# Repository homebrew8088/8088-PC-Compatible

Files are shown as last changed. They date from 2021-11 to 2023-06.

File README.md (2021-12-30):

# 8088-PC-Compatible
8088 PC Compatible
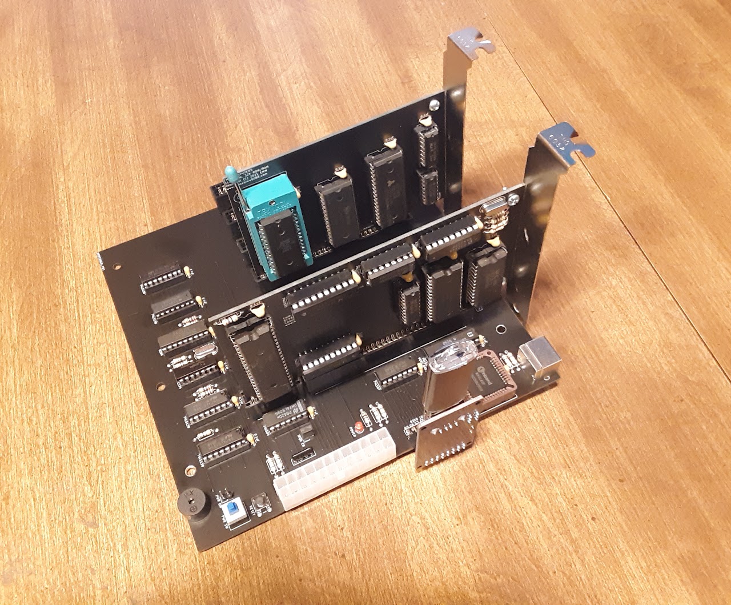
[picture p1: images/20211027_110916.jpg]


\
\
This is a repository for my 8088 PC Compatible project developed in 2021. The Motherboard is built to be generally PC XT compatible.

**Homepage**\
https://www.homebrew8088.com/

**Join the discussion group on Discord**\
https://discord.gg/AswNqwpRGP

**eBay store**\
http://www.ebay.com/sch/emil6190/m.html

**Features:**\
-8088, NEC V20, OR NEC V40 Processor\
-512k RAM (This can be changed)\
-8 Bit ISA sockets (4 slots or 7 slots)\
-PC Speaker\
-USB "Hard Drive"\
-PS/2 Keyboard\
-ATX form factor\
-Add on DMA controller (7 slot ISA only) 

[My BIOS Files](https://github.com/homebrew8088/8088-PC-Compatible/tree/main/bios) are early versions and are very primitive.

The best BIOS to use is located at https://gitlab.com/hakfoo1/v40-bios. This works on the V20 and V40 just fine. You will need one of the earlier version if you are using an actual 8088 processor. This is due to some 80186 code that was included.

-note this BIOS will not boot without a video card.

You will find the [Keyboard Fix](https://github.com/homebrew8088/8088-PC-Compatible/tree/main/asm/keyboard%20fix) under asm. Add this to your autoexec.bat if your keyboard is not working after DOS boots up.

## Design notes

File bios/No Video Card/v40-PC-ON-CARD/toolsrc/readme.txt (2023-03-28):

These tools were originally written in QuickBASIC and compiled for DOS.

However, they can be compiled for Windows/Linux with no modifications using

the FreeBASIC compiler with the "-lang qb" switch.

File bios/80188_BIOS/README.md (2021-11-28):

## This BIOS is for the 80188 with a CGA card

This is my basic BIOS adjusted for the 80188.\
For my project the only setup code needed for the 80188 processor is.

<pre>
MOV DX, 0XFFFE     ;Set DX to the Relocation Register
MOV AX, 0X40FF     ;Set AX to the new value
OUT DX, AX         ;OUT to port 0XFFFE

or 

MOV DX, 0XFFFE     ;Set DX to the Relocation Register
MOV AX, 0X60FF     ;Set AX to the new value
OUT DX, AX         ;OUT to port 0XFFFE
</pre>

This sets the internal interrupt controller as the slave making the external interrupt controller the master.

IO PORT 0XFFFE (Default value = 0X20FF)
Bit 15 |Bit 14       |Bit 13 |Bit 12       |Bit 11 - Bit 0 
-------|-------------|-------|-------------|-------
X 	   |Slave/Master |X      |M/IO         |Relocation Address 
0      |1 = S, 0 = M |0      |1 = M, 0 = IO|12 Bits if Mem Address, 8 Bits if IO Address

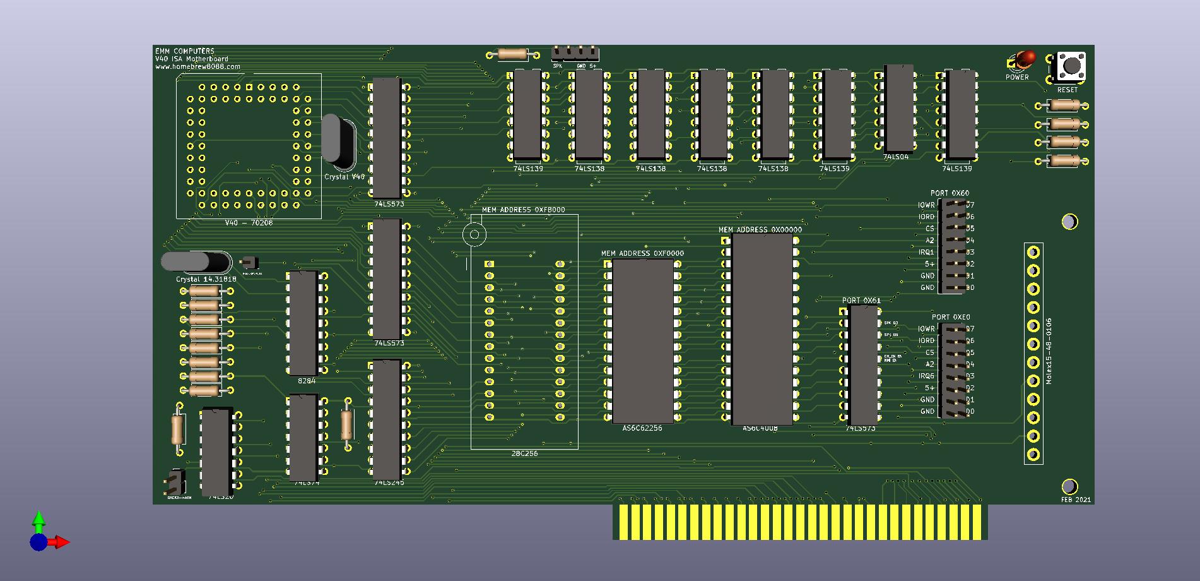
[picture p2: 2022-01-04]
Kicad/Multi ATX ISA With DMA/V40.jpg

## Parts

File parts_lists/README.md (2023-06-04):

# Parts List
This list was last updated 17 Nov 21

## Main Board 7 Slot
Description                 | Quantity
--------------------------- | ------------------------
PCB	                        |1
62 Pin Edge Card Connector 	|7
16 Pin Edge Card Connector 	|2
PLCC 44                    	|1
PS/2 Connector             	|1
24 Pin ATX Power Connector	|1
16 Right Angle Pin Header	  |1
6x6x4mm Button	            |1
8x8mm Push Pull Button	    |1
PC Speaker                	|1
1x2 Pin Header            	|1
3mm Led	                    |1
510 ohm Resistor	          |3
27 ohm Resistor           	|4
33 ohm Resistor           	|1
10K ohm Resistor	          |7
10k ohm 4 Pin Resistor Network  |2
10k ohm 9 Pin Resistor Network  |1
0.1uF Capacitor             |28
14.31818 MHz Crystal        |1
14 Pin DIP Socket         	|3
16 Pin DIP Socket         	|6
18 Pin DIP Socket           |1
20 Pin DIP Socket         	|2
74LS138                   	|3
74LS139	                    |3
74LS04                     	|1
74LS07                     	|1
74LS573	                    |1
74LS245                     |1
74LS74	                    |1
P8284	                      |1
VT82C42V                  	|1
CH376	                      |1
USB Drive	                  |1

## 8088 / V20 Card
Description           | Quantity
--------------------- | ------------------------
PCB	                  |1
16 Pin DIP Socket	    |1
18 Pin DIP Socket	    |1
20 Pin DIP Socket	    |3
24 Pin DIP Socket   	|1
28 Pin DIP Socket   	|1
40 Pin DIP Socket	    |1
70108 V20	            |1
74LS573	              |2
74LS245	              |1
74LS257	              |1
P8284               	|1
8259                	|1
8253                	|1
0.1uF Capacitor     	|8
510 ohm Resistor	    |2
27 ohm Resistor	      |1
10k ohm Resistor    	|2
~24 MHz Crystal      	|1
Keystone 9202	        |1
Screws              	|2

## V40 Card
Description           | Quantity
--------------------- | ------------------------
PCB	                  |1
PLCC 68 Socket	      |1
20 Pin DIP Socket	    |3
70208 V40	            |1
74LS573	              |2
74LS245	              |1
0.1uF Capacitor	      |4
10k ohm Resistor	    |2
16 MHz Crystal	      |1
Keystone 9202	        |1
Screws	              |2

## 640K RAM / 64K ROM Card
Description           | Quantity
--------------------- | ------------------------
PCB	                  |1
16 Pin DIP Socket     |2
32 Pin DIP Socket	    |4
74LS138	              |1
74LS139	              |1
AS6C4008	            |1
AS6C1008	            |1
W29C020	              |1
0.1uF Capacitor     	|6
Keystone 9202       	|1
Screws              	|2

## 512K RAM / 32K ROM Card
Description           | Quantity
--------------------- | ------------------------
PCB	                  |1
16 Pin DIP Socket     |2
28 Pin DIP Socket	    |1
32 Pin DIP Socket	    |1
28 Pin ZIF Socket	    |1
74LS138	              |1
74LS139	              |1
62256	                |1
AS6C4008	            |1
28C256	              |1
0.1uF Capacitor     	|5
Keystone 9202       	|1
Screws              	|2

## 640K RAM / 32K ROM Card
Description           | Quantity
--------------------- | ------------------------
PCB	                  |1
16 Pin DIP Socket     |2
28 Pin DIP Socket	    |2
32 Pin DIP Socket	    |2
74LS138	              |1
74LS139	              |1
AS6C4008	            |1
AS6C1008	            |1
62256	                |1
28C256	              |1
0.1uF Capacitor     	|6
Keystone 9202       	|1
Screws              	|2

## 8237 DMA Controller Card
Description           | Quantity
--------------------- | ------------------------
PCB	                  |1
40 Pin DIP Socket     |1
20 Pin DIP Socket     |1
16 Pin DIP Socket     |2
14 Pin DIP Socket     |1
74LS573		            |1
74LS670		            |1
74LS139		            |1
74LS04		            |1
8237-5		            |1
0.1uF Capacitor		    |5
10k ohm Resistor		  |2
27 ohm Resistor |1
Keystone 9202		      |1
Screws		            |2

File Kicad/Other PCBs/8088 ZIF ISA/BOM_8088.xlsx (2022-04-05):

Comment | Designator | Footprint | JLCPCB Part #（optional）
0.1uF | C1, C2, C3, C4, C5, C6, C7, C8 | RAD-0.2 | C19355
27R | R1 | Axial,2.4X6.5mm | C433740
510R | R2, R3 | Axial,2.4X6.5mm | C433711
10K | R4, R5 | Axial,2.4X6.5mm | C433778
DIP 40 SOCKET | U1 | DIP-40 | C72123
DIP 20 SOCKET | U2, U3, U4 | DIP-20 | C72118
DIP 16 SOCKET | U5 | DIP-16 | C72115
DIP 18 SOCKET | U6 | DIP-18 | C72116
DIP 28 SOCKET | U7 | DIP-28 | C72121
DIP 24 SOCKET | U8 | DIP-24 | C72120

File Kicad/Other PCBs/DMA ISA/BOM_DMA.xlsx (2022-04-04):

Comment | Designator | Footprint | JLCPCB Part #（optional）
0.1uF | C1, C2, C3, C4, C5 | RAD-0.2 | C19355
27R | R3 | Axial,2.4X6.5mm | C433740
10K | R1, R2 | Axial,2.4X6.5mm | C433778
DIP 40 SOCKET | U1 | DIP-40 | C72123
DIP 20 SOCKET | U5 | DIP-20 | C72118
DIP 16 SOCKET | U2, U4 | DIP-16 | C72115
DIP 14 SOCKET | U3 | DIP-14 | C72114

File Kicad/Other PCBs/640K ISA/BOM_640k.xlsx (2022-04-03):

Comment | Designator | Footprint | JLCPCB Part #（optional）
DIP-28 | U1, U2 | DIP-28_W15.24mm | C72121
DIP-32 | U3, U4 | DIP-32_W15.24mm | C146583
DIP-16 | U5, U6 | DIP-16_W7.62mm | C72115
0.1uF (104) | C1, C2, C3, C4, C5, C6 | RAD-0.2 | C19355

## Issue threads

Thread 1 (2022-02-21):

PIT initialisation code

gyorka, 2022-02-21:
Hi!
Since I'm doing V50 design myself, I wondered if someone did something similiar in the past, and I found your code and board design
I've looked into BIOS code and found that you're initialising Timer/Counter 2 to 0xFFFF - this counter counts down to 1, not to 0, thus you're a bit on high side for 18.2Hz period
Initialisation value should be 0x0000 instead, and it seems to be quite common "error"
Anyways - great project and I hope to see more of projects like this from you ;)
Cheers
 Sebastian

Closed 2023-06-17.

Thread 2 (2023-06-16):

pdf schematics seem to be broken

jmio23, 2023-06-16:
I've tried acrobat, word, chrome and a whole bunch of others, always looks like this

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

cuvtixo, 2023-06-16:
er, jmio23, firstly, there's 8 different schematics, I think you are looking at the 8088.pdf . But, THAT IS THE SCHEMATIC.  There's nothing more to these. They are not full electronic diagrams with symbols for resistors, capacitors, etc. It is mainly just the integrated circuits, and for example, 4 Slot Main Board.pdf has the various numerical values, but what you see is what you get.  I'm sorry you were expecting more.

homebrew8088, 2023-06-17:
That is how I draw my schematics. When I add the net lines it gets to busy for me to look at. I just know the chips by memory at this point and assign the pins where they need to go.

Yes they are bit out of date. I should get some newer ones published. **But** when you open the Kicad project files you will get the most up to date schematic that I been working on. Plus if you open the PCB files you can highlight the traces and see how everything is connected.

jmio23, 2023-06-18:
> That is how I draw my schematics. When I add the net lines it gets to busy for me to look at. I just know the chips by memory at this point and assign the pins where they need to go.
>
> Yes they are bit out of date. I should get some newer ones published. **But** when you open the Kicad project files you will get the most up to date schematic that I been working on. Plus if you open the PCB files you can highlight the traces and see how everything is connected.

thanks I'll check those files out; I've never used kiCad, will I be able to see for eg the entire circuit for the ISA pinout and ISA/BIOS connections? Unfortunately due to disability, even installing kiCad, let alone using it, will be a challenge for me, but if it will give me those details then it's worth the pain

I am trying to learn enough, so that I can add a solution for low rez monochrome graphics to my v20-mbc; an ISA bus i can plug a video (or whatever) card into is my preferred option; I was contemplating an ISA emulation over SPI, or an emulation of both the bus and graphics over SPI, but that feels a convoluted approach (esp considering what I still need to learn) if I can persuade the atmega32/BIOS to handle a hardware ISA bus

Closed 2023-06-17.

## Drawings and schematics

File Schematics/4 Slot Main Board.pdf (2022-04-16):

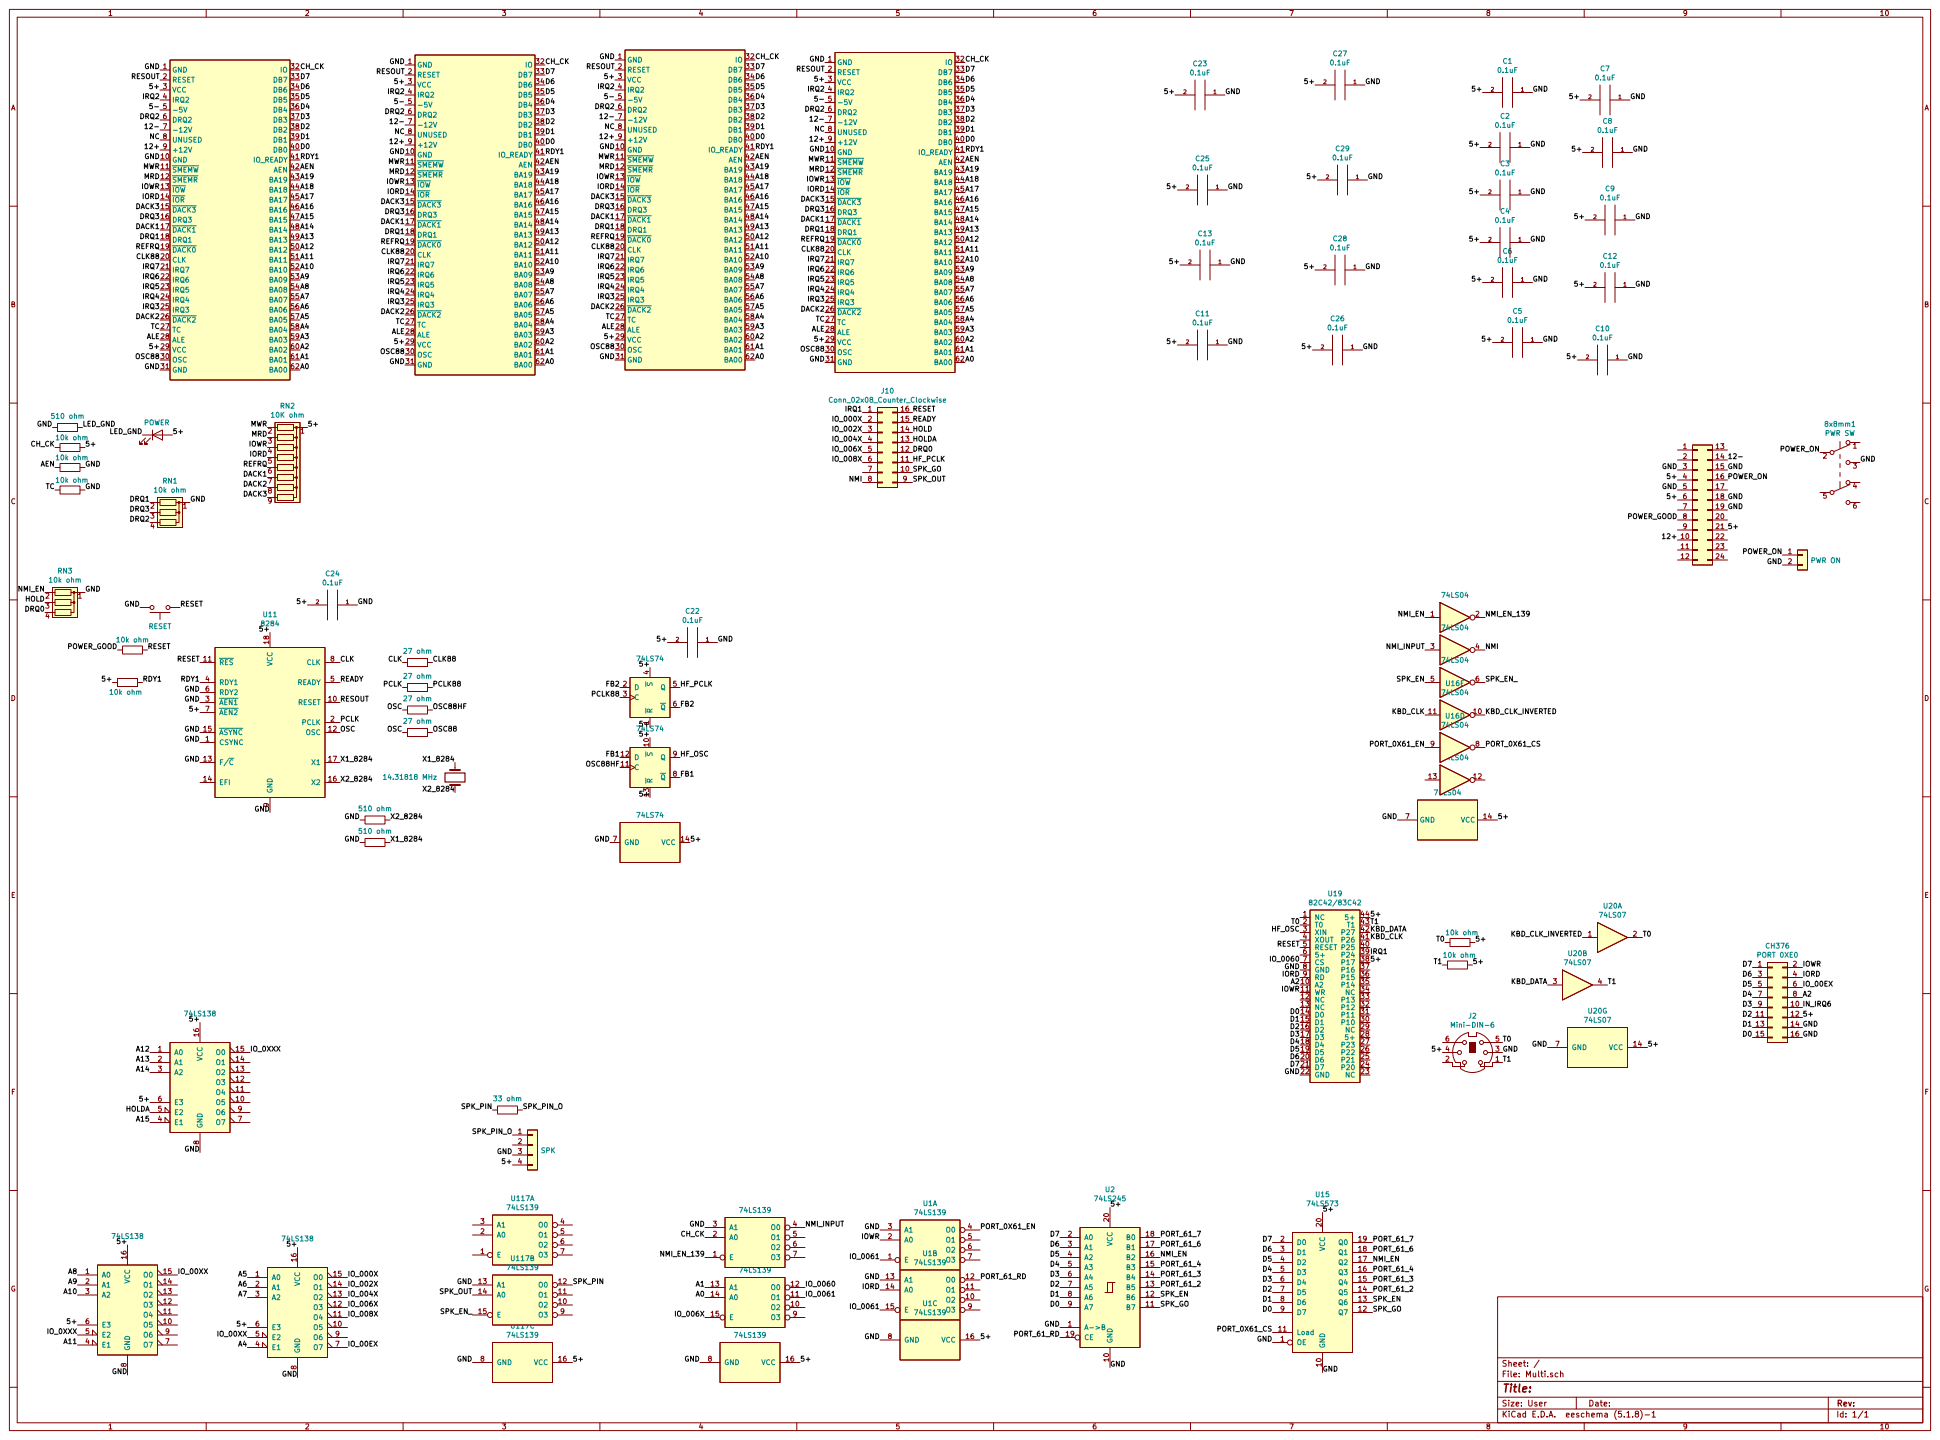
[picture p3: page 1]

12- AEN
IOWR MRD MWR GND

Id: 1/1 Title: File: Multi.sch Sheet: /

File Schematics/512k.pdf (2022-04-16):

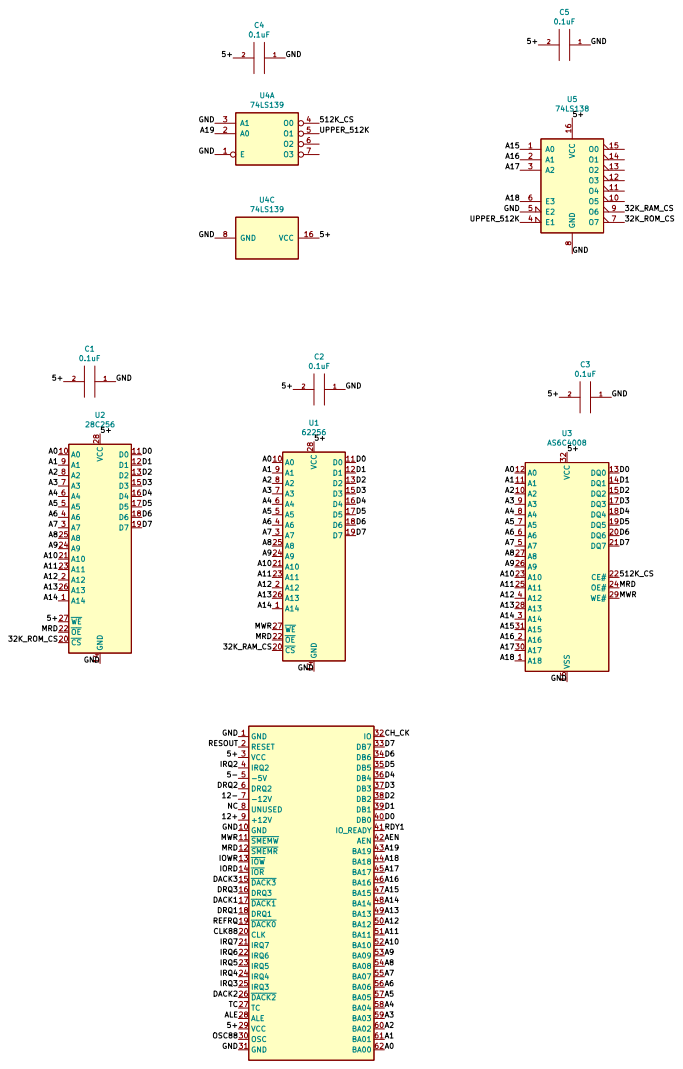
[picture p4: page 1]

IOWR MRD MWR GND

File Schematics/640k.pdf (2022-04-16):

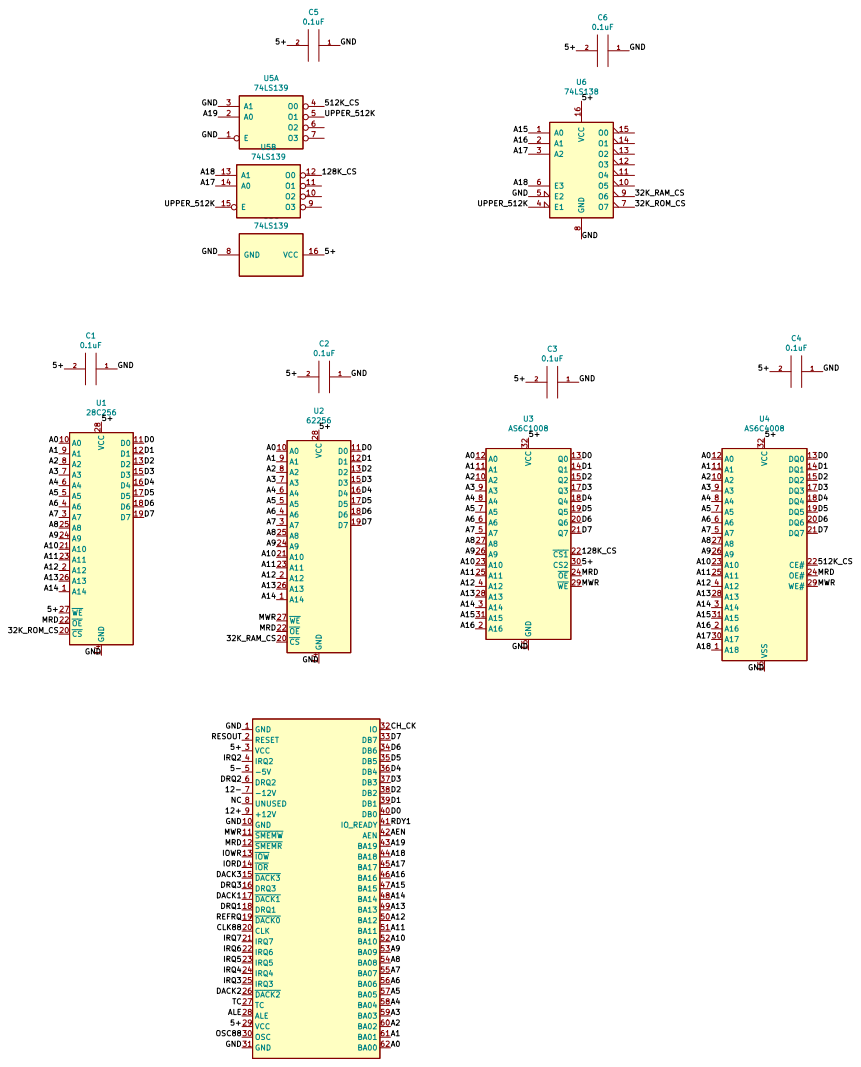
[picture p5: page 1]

IOWR MRD MWR GND

Id: 1/1 Title: File: 640k.sch Sheet: /

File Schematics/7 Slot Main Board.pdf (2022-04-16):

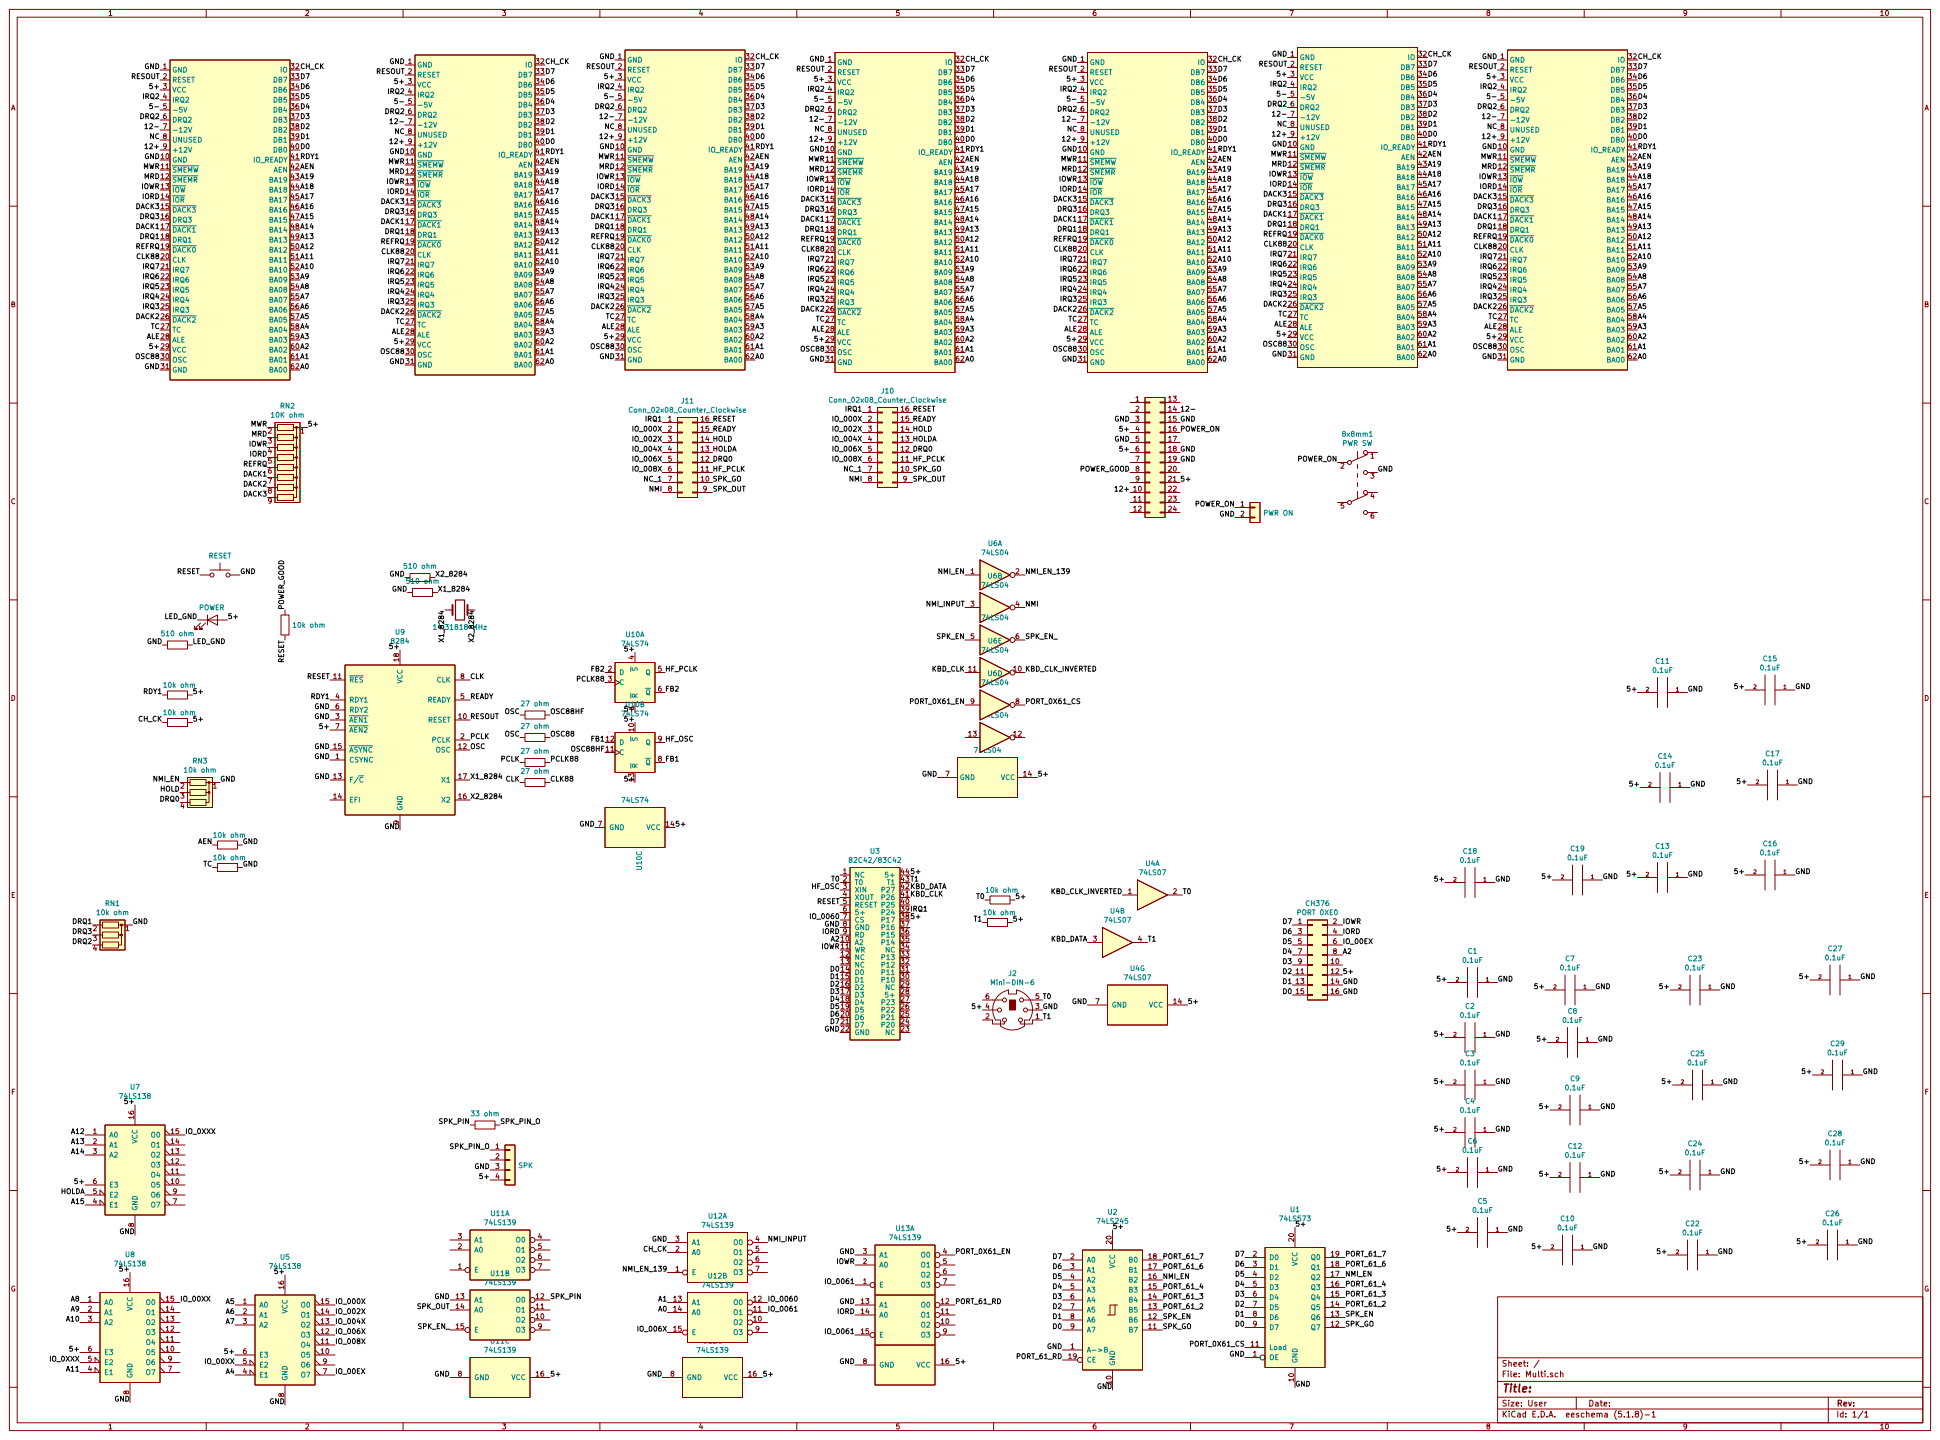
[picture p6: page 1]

IOWR MRD MWR GND

Id: 1/1 Title: File: Multi.sch Sheet: /

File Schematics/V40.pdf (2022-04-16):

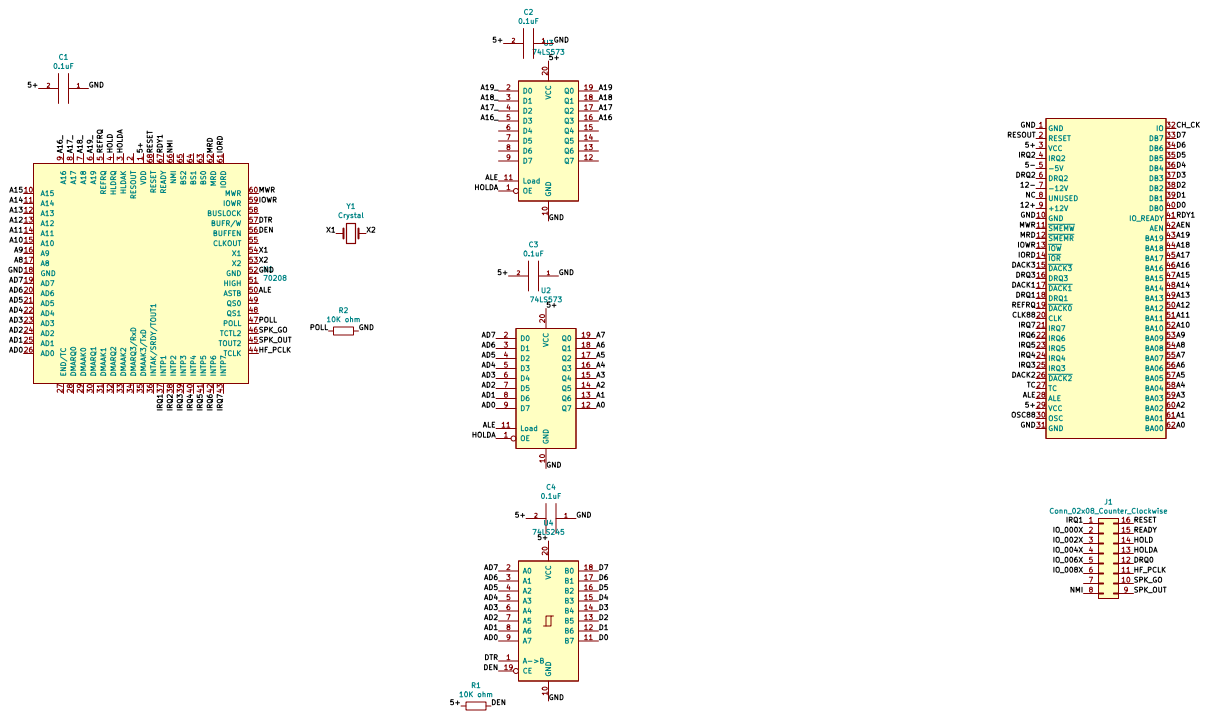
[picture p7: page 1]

IOWR MRD MWR GND

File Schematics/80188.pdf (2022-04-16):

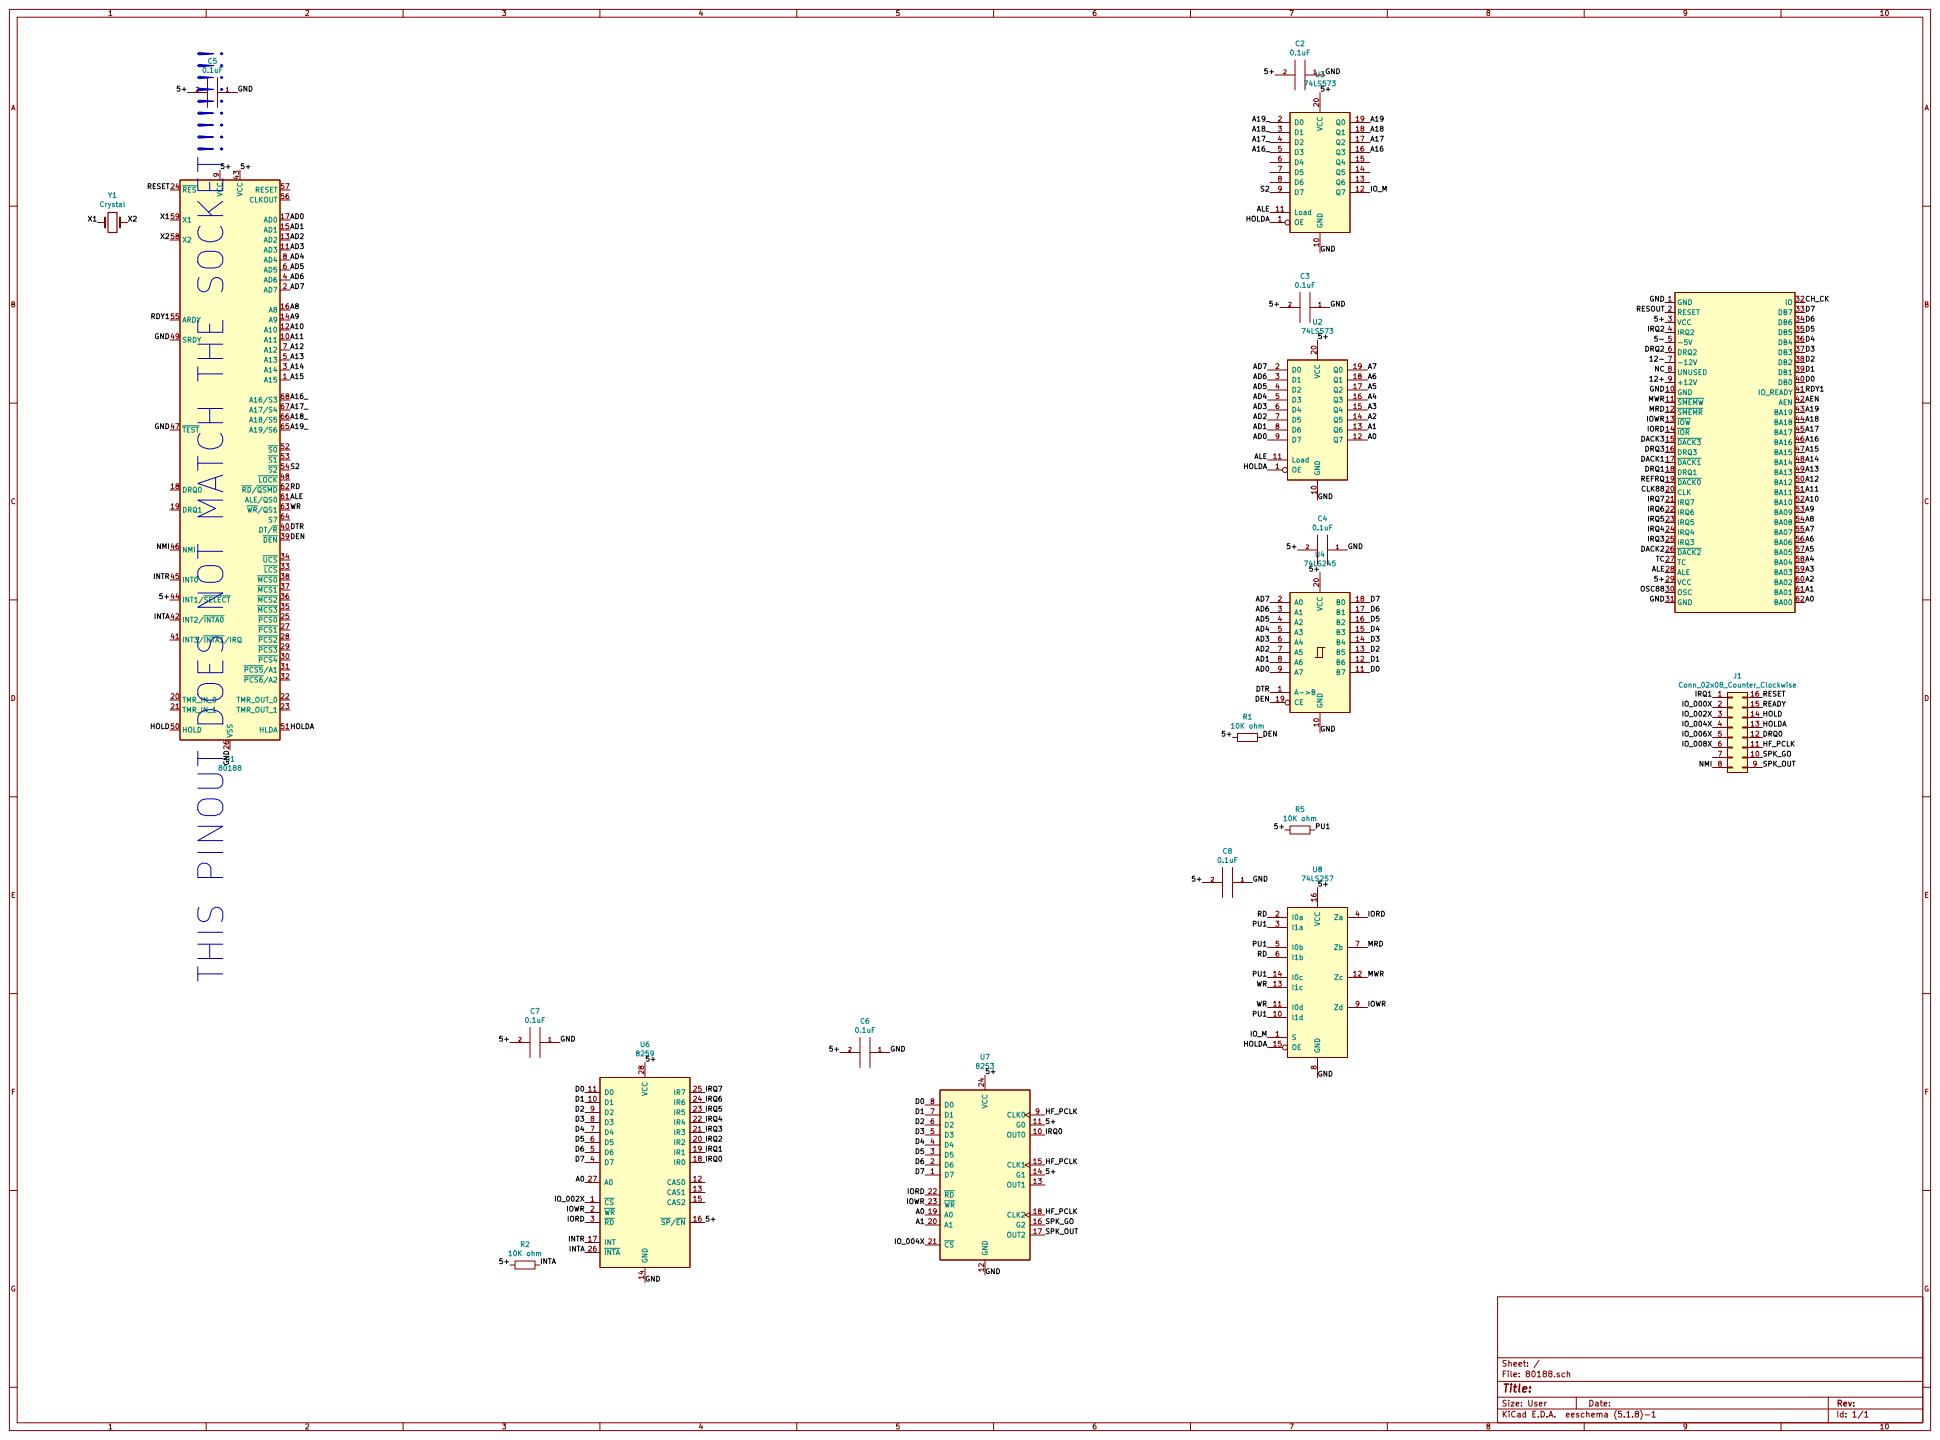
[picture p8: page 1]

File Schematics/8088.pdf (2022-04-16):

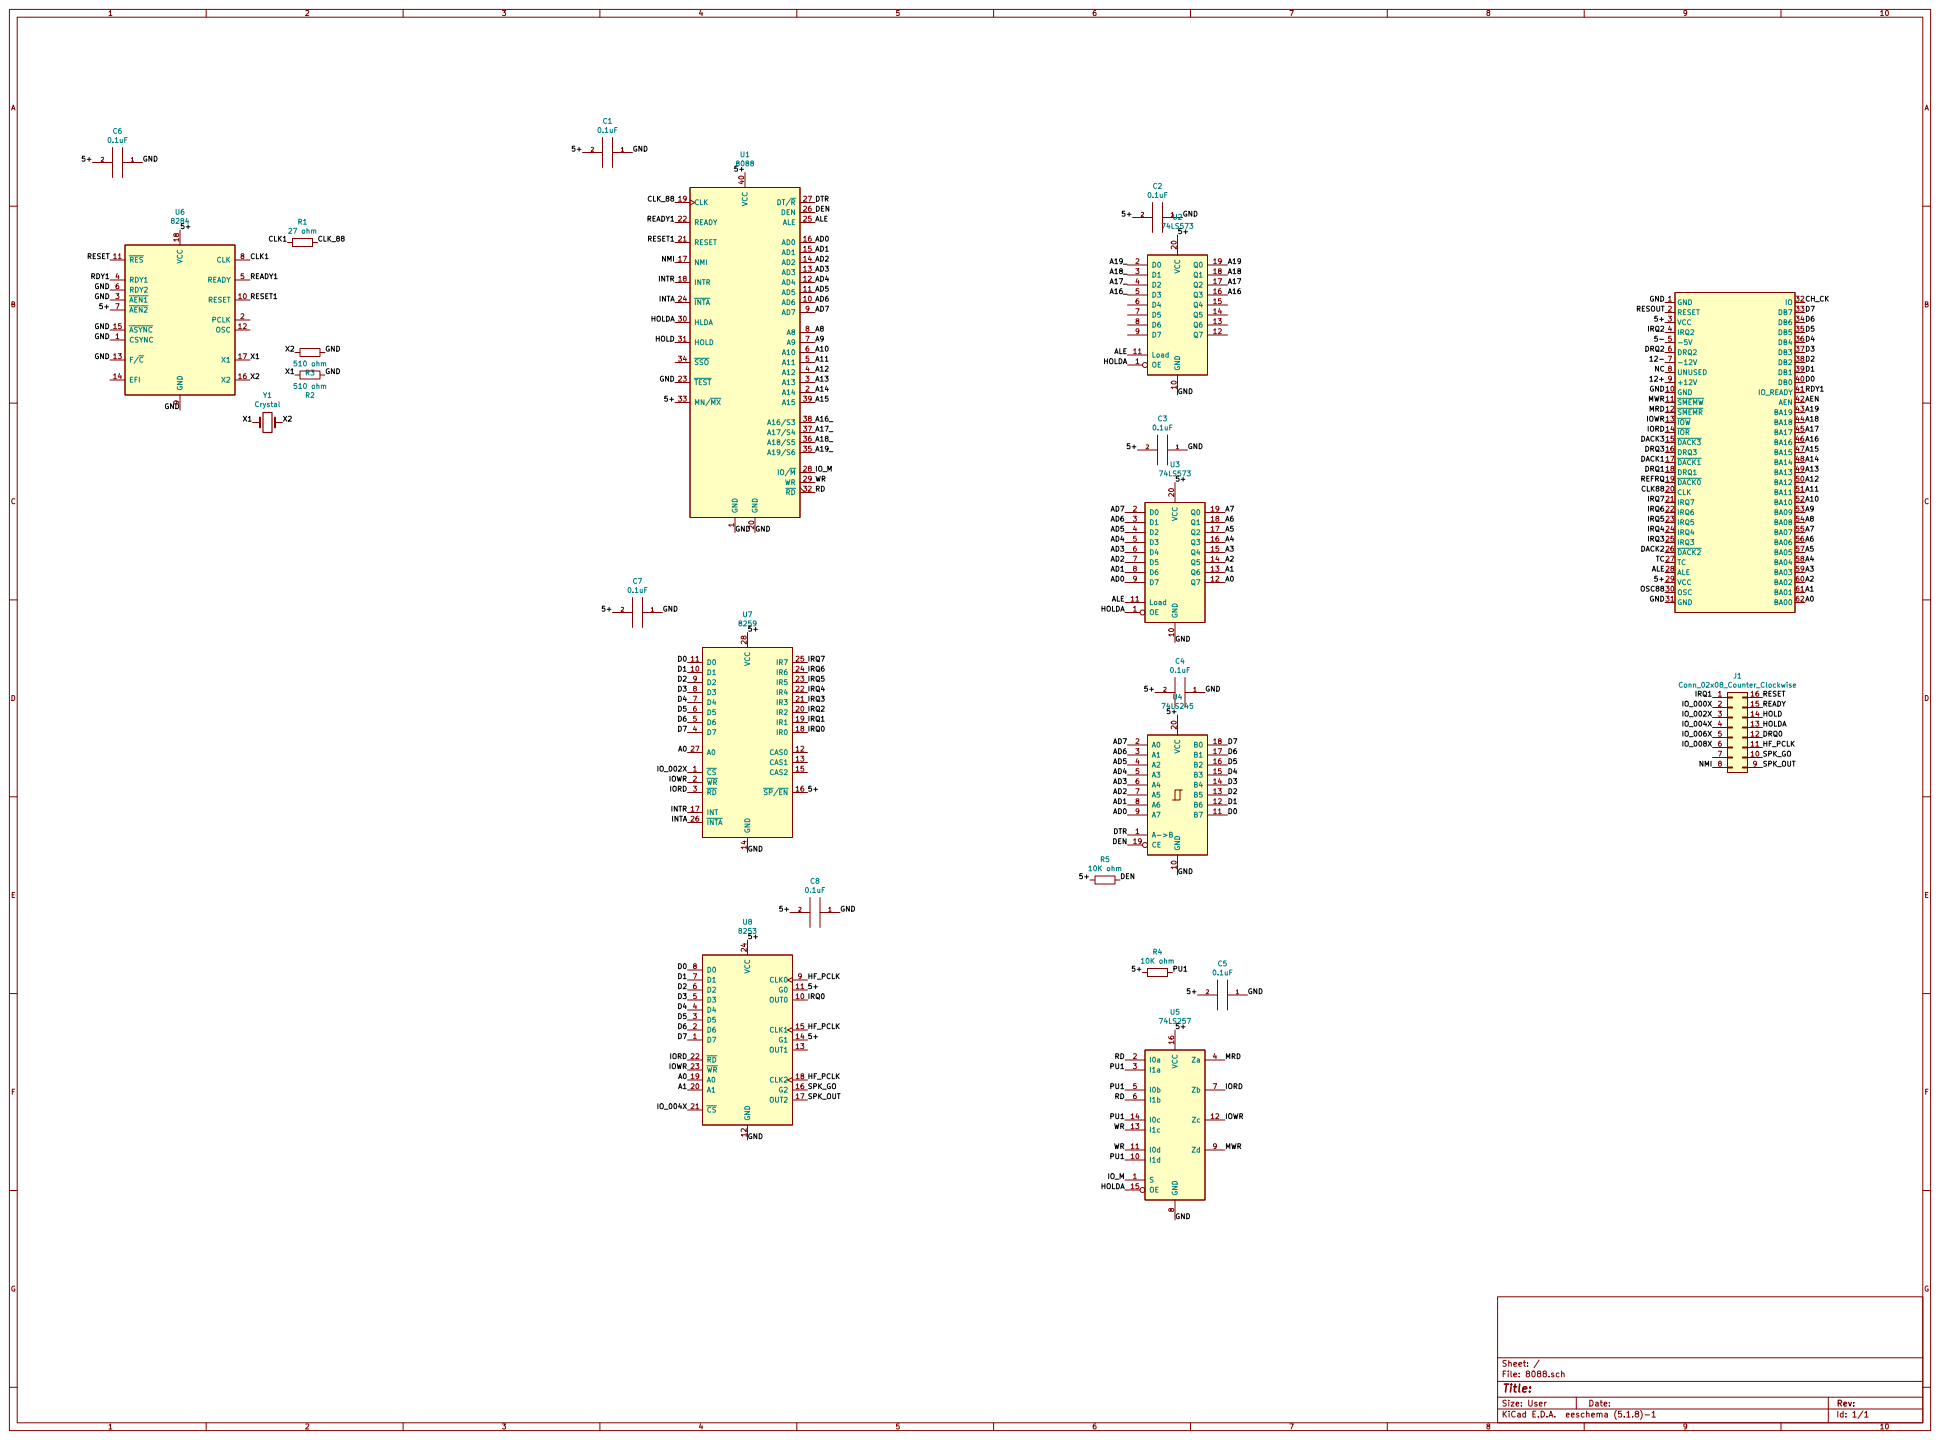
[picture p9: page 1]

Id: 1/1 Title: File: 8088.sch Sheet: / S 1

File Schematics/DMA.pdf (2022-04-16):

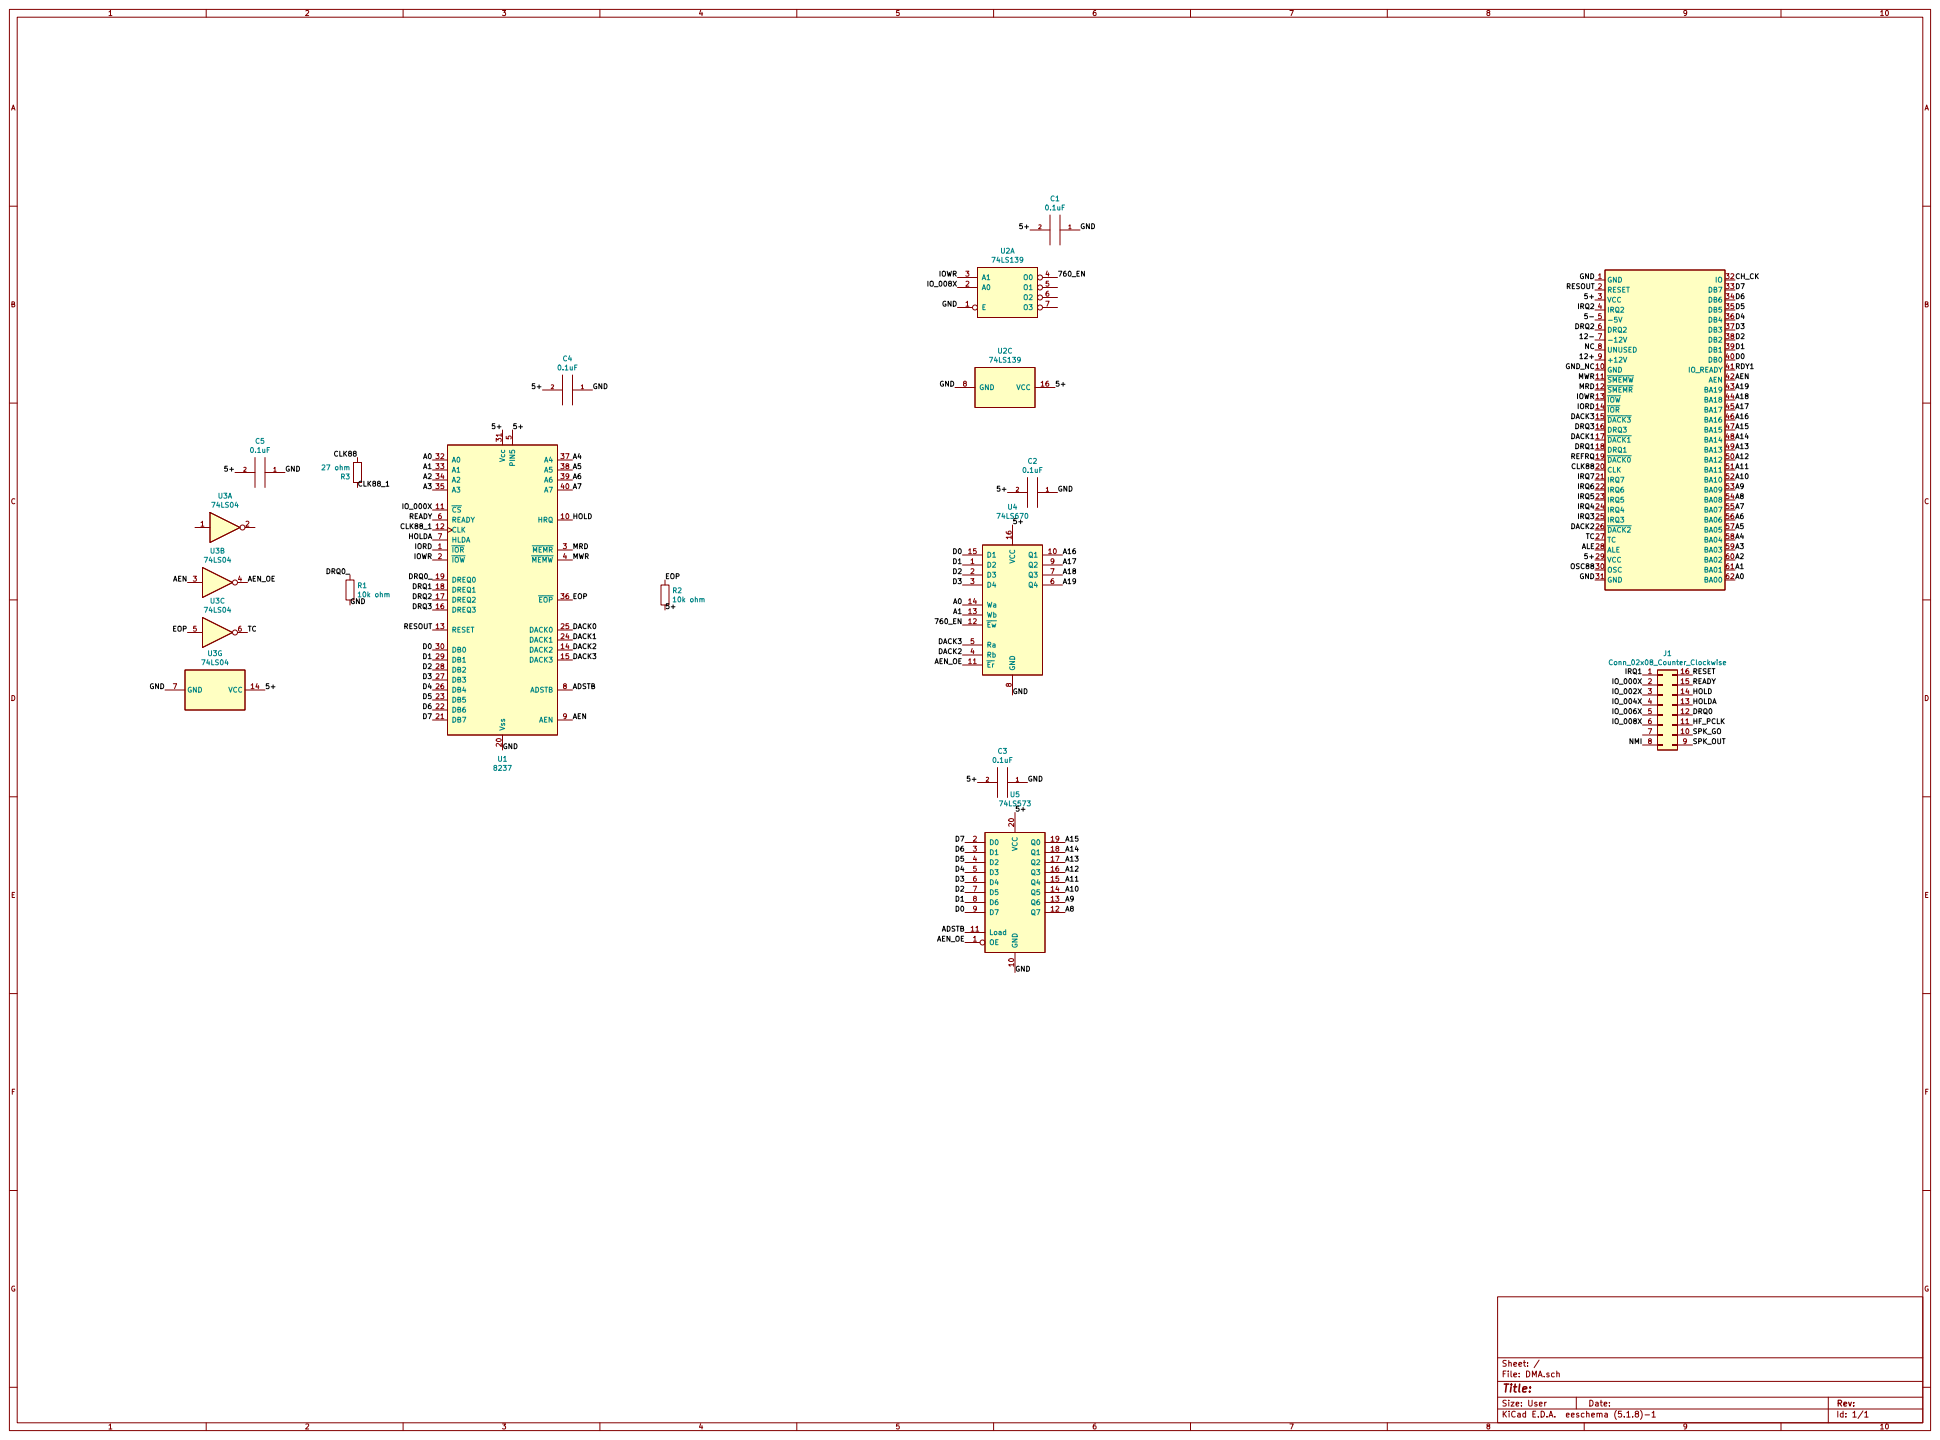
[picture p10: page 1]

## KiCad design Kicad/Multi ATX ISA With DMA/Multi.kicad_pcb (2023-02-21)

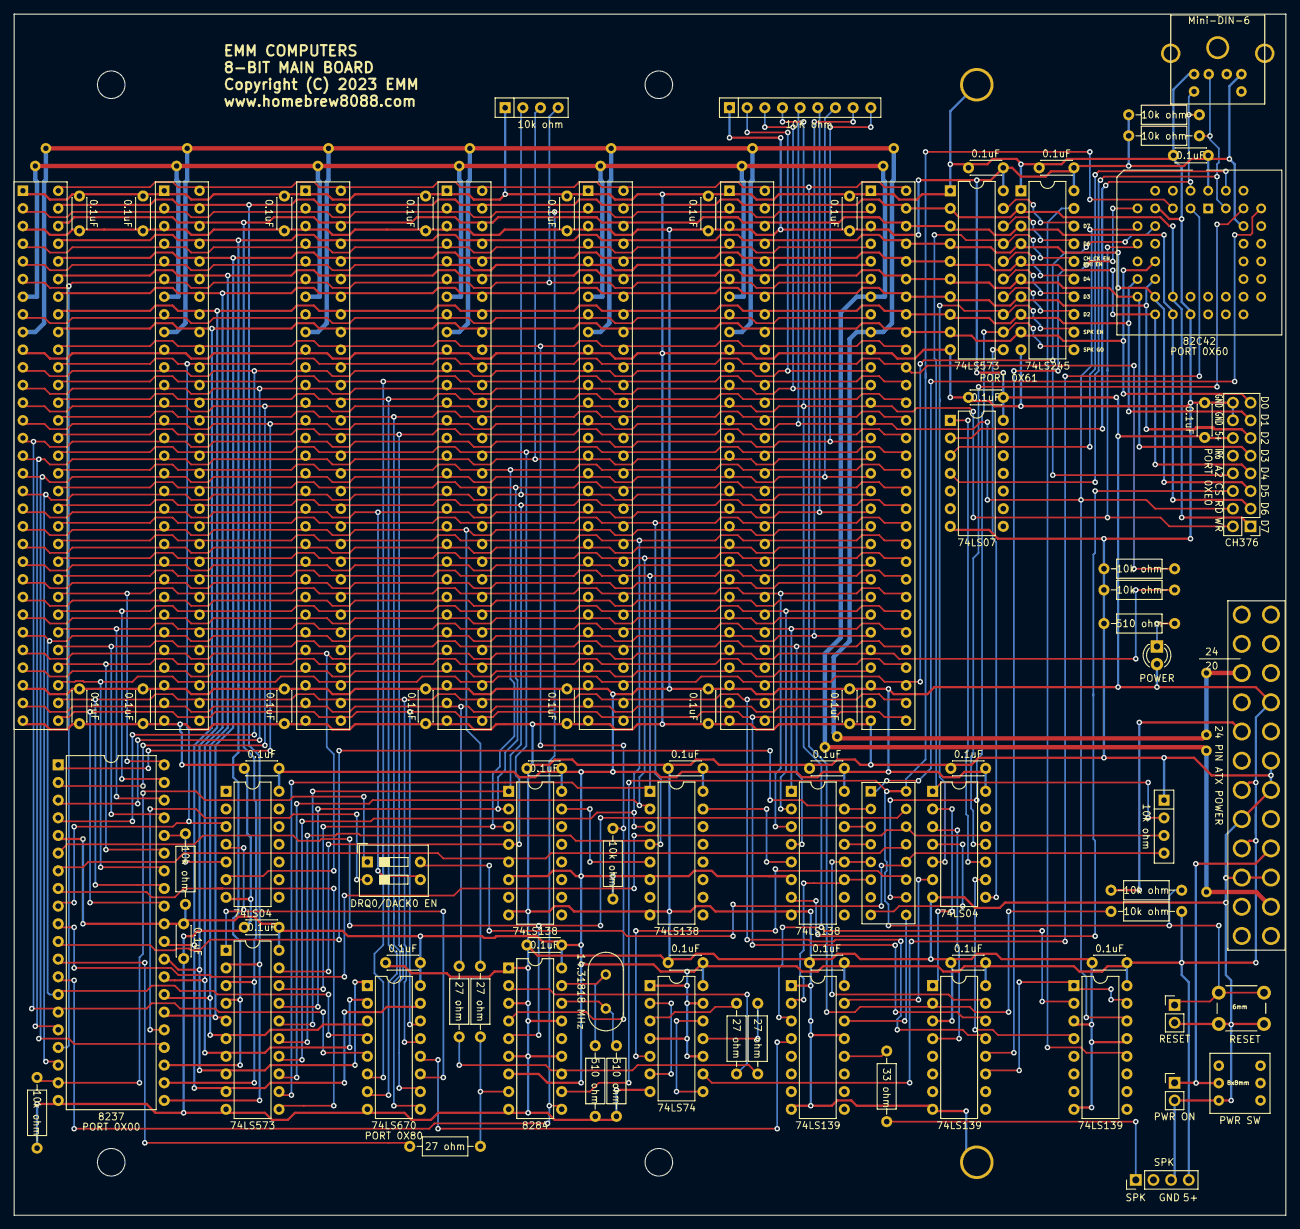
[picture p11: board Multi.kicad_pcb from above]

Board: 2 copper layers, 182.9 x 172.7 mm, 109 parts (0 on the bottom side), 119 nets.

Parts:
8x8mm1: PWR SW; 6 PIN DTDP
ATXPOWER1: Conn_02x12_Top_Bottom; 24_PIN_ATX_POWER
C1, C1#2, C1#3, C2, C3, C4, C5, C6, C7, C8, C9, C10, C11, C12, C13, C14, C15, C16, C17, C18, C19, C22, C23, C24, C25, C26, C27, C28, C29, C63, C64, C65: 0.1uF; C_Disc_D4.3mm_W1.9mm_P5.00mm
CH376: PORT 0XE0; PinHeader_2x08_P2.54mm_Vertical
D1: POWER; LED_D3.0mm
J1, J4, J5, J7, J8, J9, J11: Bus_ISA_8bit; 8-bit-ISA
J2: Mini-DIN-6; 6_PIN_DIN
J3: SPK; PinHeader_1x04_P2.54mm_Vertical
J6: PWR ON; PinHeader_1x02_P2.54mm_Vertical
J10: Conn_02x08_Counter_Clockwise; 2x08_PIN_EDGE_CARD
J12: RESET; PinHeader_1x02_P2.54mm_Vertical
R: L; Large_Via
R1, R2, R4: 510 ohm; R_Axial_DIN0207_L6.3mm_D2.5mm_P10.16mm_Horizontal
R3, R14, R17, R18, R63: 27 ohm; R_Axial_DIN0207_L6.3mm_D2.5mm_P10.16mm_Horizontal
R5, R6, R7, R8, R9, R12, R13, R61, R62: 10k ohm; R_Axial_DIN0207_L6.3mm_D2.5mm_P10.16mm_Horizontal
R#2, R#3, R#4, R#5, R#6, R#7, R#8, R#9, R#10, R#11, R#12, R#13, R#14, R#15, R#16, R#17, R#18, R#19, R#20: L; Large_Via
RN1, RN3: 10k ohm; R_Array_SIP4
RN2: 10K ohm; R_Array_SIP9
SW1: RESET; SW_PUSH_6mm
SW2: DRQ0/DACK0 EN; SW_DIP_SPSTx02_Slide_9.78x7.26mm_W7.62mm_P2.54mm
U1, U17, U117: 74LS139; DIP-16_W7.62mm
U2: 74LS245; DIP-20_W7.62mm
U3: 33 ohm; R_Axial_DIN0207_L6.3mm_D2.5mm_P10.16mm_Horizontal
U9, U12, U13: 74LS138; DIP-16_W7.62mm
U11: 8284; DIP-18_W7.62mm
U14: 74LS74; DIP-14_W7.62mm
U15, U65: 74LS573; DIP-20_W7.62mm
U16, U63: 74LS04; DIP-14_W7.62mm
U19: 82C42; PLCC-44_THT-Socket
U20: 74LS07; DIP-14_W7.62mm
U61: 8237; DIP-40_W15.24mm
U64: 74LS670; DIP-16_W7.62mm
Y2: 14.31818 MHz; Crystal_HC18-U_Vertical

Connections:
/5+: ATXPOWER1.4, ATXPOWER1.6, ATXPOWER1.21, C1.2, C1#2.2, C1#3.2, C2.2, C3.2, C4.2, C5.2, C6.2, C7.2, C8.2, C9.2, C10.2, C11.2, C12.2, C13.2, C14.2, C15.2, C16.2, C17.2, C18.2, C19.2, C22.2, C23.2, C24.2, C25.2, C26.2, C27.2, C28.2, C29.2, C63.2, C64.2, C65.2, CH376.12, D1.2, J1.3, J1.29, J2.4, J3.4, J4.3, J4.29, J5.3, J5.29, J7.3, J7.29, J8.3, J8.29, J9.3, J9.29, J11.3, J11.29, R6.1, R7.1, R8.1, R9.1, R62.2, RN2.1, U1.16, U2.20, U9.6, U9.16, U11.7, U11.18, U12.6, U12.16, U13.6, U13.16, U14.1, U14.4, U14.10, U14.13, U14.14, U15.20, U16.14, U17.16, U19.38, U19.44, U20.14, U61.5, U61.31, U63.14, U64.16, U65.20, U117.16
/5-: J1.5, J4.5, J5.5, J7.5, J8.5, J9.5, J11.5
/12+: ATXPOWER1.10, J1.9, J4.9, J5.9, J7.9, J8.9, J9.9, J11.9, R.1, R#3.1, R#6.1, R#7.1, R#8.1, R#12.1, R#14.1, R#15.1, R#18.1, R#20.1
/12-: ATXPOWER1.14, J1.7, J4.7, J5.7, J7.7, J8.7, J9.7, J11.7, R#2.1, R#4.1, R#5.1, R#9.1, R#10.1, R#11.1, R#13.1, R#16.1, R#17.1, R#19.1
/760_EN: U64.12, U117.4
/A0: J1.62, J4.62, J5.62, J7.62, J8.62, J9.62, J11.62, U17.14, U61.32, U64.14
/A1: J1.61, J4.61, J5.61, J7.61, J8.61, J9.61, J11.61, U17.13, U61.33, U64.13
/A2: CH376.8, J1.60, J4.60, J5.60, J7.60, J8.60, J9.60, J11.60, U19.10, U61.34
/A3: J1.59, J4.59, J5.59, J7.59, J8.59, J9.59, J11.59, U61.35
/A4: J1.58, J4.58, J5.58, J7.58, J8.58, J9.58, J11.58, U13.4, U61.37
/A5: J1.57, J4.57, J5.57, J7.57, J8.57, J9.57, J11.57, U13.1, U61.38
/A6: J1.56, J4.56, J5.56, J7.56, J8.56, J9.56, J11.56, U13.2, U61.39
/A7: J1.55, J4.55, J5.55, J7.55, J8.55, J9.55, J11.55, U13.3, U61.40
/A8: J1.54, J4.54, J5.54, J7.54, J8.54, J9.54, J11.54, U12.1, U65.12
/A9: J1.53, J4.53, J5.53, J7.53, J8.53, J9.53, J11.53, U12.2, U65.13
/A10: J1.52, J4.52, J5.52, J7.52, J8.52, J9.52, J11.52, U12.3, U65.14
/A11: J1.51, J4.51, J5.51, J7.51, J8.51, J9.51, J11.51, U12.4, U65.15
/A12: J1.50, J4.50, J5.50, J7.50, J8.50, J9.50, J11.50, U9.1, U65.16
/A13: J1.49, J4.49, J5.49, J7.49, J8.49, J9.49, J11.49, U9.2, U65.17
/A14: J1.48, J4.48, J5.48, J7.48, J8.48, J9.48, J11.48, U9.3, U65.18
/A15: J1.47, J4.47, J5.47, J7.47, J8.47, J9.47, J11.47, U9.4, U65.19
/A16: J1.46, J4.46, J5.46, J7.46, J8.46, J9.46, J11.46, U64.10
/A17: J1.45, J4.45, J5.45, J7.45, J8.45, J9.45, J11.45, U64.9
/A18: J1.44, J4.44, J5.44, J7.44, J8.44, J9.44, J11.44, U64.7
/A19: J1.43, J4.43, J5.43, J7.43, J8.43, J9.43, J11.43, U64.6
/ADSTB: U61.8, U65.11
/AEN: J1.42, J4.42, J5.42, J7.42, J8.42, J9.42, J11.42, R12.2, U61.9, U63.3
/AEN_OE: U63.4, U64.11, U65.1
/ALE: J1.28, J4.28, J5.28, J7.28, J8.28, J9.28, J11.28
/CH_CK: J1.32, J4.32, J5.32, J7.32, J8.32, J9.32, J11.32, R7.2, U17.2
/CLK: R18.2, R63.2, U11.8
/CLK88: J1.20, J4.20, J5.20, J7.20, J8.20, J9.20, J11.20, R18.1
/CLK88_1: R63.1, U61.12
/D0: CH376.15, J1.40, J4.40, J5.40, J7.40, J8.40, J9.40, J11.40, U2.9, U15.9, U19.14, U61.30, U64.15, U65.9
/D1: CH376.13, J1.39, J4.39, J5.39, J7.39, J8.39, J9.39, J11.39, U2.8, U15.8, U19.15, U61.29, U64.1, U65.8
/D2: CH376.11, J1.38, J4.38, J5.38, J7.38, J8.38, J9.38, J11.38, U2.7, U15.7, U19.16, U61.28, U64.2, U65.7
/D3: CH376.9, J1.37, J4.37, J5.37, J7.37, J8.37, J9.37, J11.37, U2.6, U15.6, U19.17, U61.27, U64.3, U65.6
/D4: CH376.7, J1.36, J4.36, J5.36, J7.36, J8.36, J9.36, J11.36, U2.5, U15.5, U19.18, U61.26, U65.5
/D5: CH376.5, J1.35, J4.35, J5.35, J7.35, J8.35, J9.35, J11.35, U2.4, U15.4, U19.19, U61.23, U65.4
/D6: CH376.3, J1.34, J4.34, J5.34, J7.34, J8.34, J9.34, J11.34, U2.3, U15.3, U19.20, U61.22, U65.3
/D7: CH376.1, J1.33, J4.33, J5.33, J7.33, J8.33, J9.33, J11.33, U2.2, U15.2, U19.21, U61.21, U65.2
/DACK0: SW2.2, U61.25
/DACK1: J1.17, J4.17, J5.17, J7.17, J8.17, J9.17, J11.17, RN2.7, U61.24
/DACK2: J1.26, J4.26, J5.26, J7.26, J8.26, J9.26, J11.26, RN2.8, U61.14, U64.4
/DACK3: J1.15, J4.15, J5.15, J7.15, J8.15, J9.15, J11.15, RN2.9, U61.15, U64.5
/DRQ0: J10.12, RN3.4, SW2.4
/DRQ0_: R61.1, SW2.1, U61.19
/DRQ1: J1.18, J4.18, J5.18, J7.18, J8.18, J9.18, J11.18, RN1.2, U61.18
/DRQ2: J1.6, J4.6, J5.6, J7.6, J8.6, J9.6, J11.6, RN1.4, U61.17
/DRQ3: J1.16, J4.16, J5.16, J7.16, J8.16, J9.16, J11.16, RN1.3, U61.16
/EOP: R62.1, U61.36, U63.5
/FB1: U14.8, U14.12
/FB2: U14.2, U14.6
/GND: 8x8mm1.3, ATXPOWER1.3, ATXPOWER1.5, ATXPOWER1.15, ATXPOWER1.18, ATXPOWER1.19, C1.1, C1#2.1, C1#3.1, C2.1, C3.1, C4.1, C5.1, C6.1, C7.1, C8.1, C9.1, C10.1, C11.1, C12.1, C13.1, C14.1, C15.1, C16.1, C17.1, C18.1, C19.1, C22.1, C23.1, C24.1, C25.1, C26.1, C27.1, C28.1, C29.1, C63.1, C64.1, C65.1, CH376.14, CH376.16, J1.1, J1.10, J1.31, J2.3, J3.3, J4.1, J4.10, J4.31, J5.1, J5.10, J5.31, J6.2, J7.1, J7.10, J7.31, J8.1, J8.10, J8.31, J9.1, J9.10, J9.31, J11.1, J11.10, J11.31, J12.2, R1.2, R2.2, R4.2, R12.1, R13.1, R61.2, RN1.1, RN3.1, SW1.2, U1.3, U1.8, U1.13, U2.1, U2.10, U9.8, U11.1, U11.3, U11.6, U11.9, U11.13, U11.15, U12.8, U13.8, U14.7, U15.1, U15.10, U16.7, U17.3, U17.8, U19.8, U19.22, U20.7, U61.20, U63.7, U64.8, U65.10, U117.1, U117.8, U117.13
/HF_OSC: U14.9, U19.3
/HF_PCLK: J10.11, U14.5
/HOLD: J10.14, RN3.3, U61.10
/HOLDA: J10.13, U9.5, U61.7
/IORD: CH376.4, J1.14, J4.14, J5.14, J7.14, J8.14, J9.14, J11.14, RN2.5, U1.14, U19.9, U61.1
/IOWR: CH376.2, J1.13, J4.13, J5.13, J7.13, J8.13, J9.13, J11.13, RN2.4, U1.2, U19.11, U61.2, U117.3
/IO_00EX: CH376.6, U13.7
/IO_000X: J10.2, U13.15, U61.11
/IO_00XX: U12.15, U13.5
/IO_0XXX: U9.15, U12.5
/IO_002X: J10.3, U13.14
/IO_004X: J10.4, U13.13
/IO_006X: J10.5, U13.12, U17.15
/IO_008X: J10.6, U13.11, U117.2
/IO_0060: U17.12, U19.7
/IO_0061: U1.1, U1.15, U17.11
/IRQ1: J10.1, U19.39
/IRQ2: J1.4, J4.4, J5.4, J7.4, J8.4, J9.4, J11.4
/IRQ3: J1.25, J4.25, J5.25, J7.25, J8.25, J9.25, J11.25
/IRQ4: J1.24, J4.24, J5.24, J7.24, J8.24, J9.24, J11.24
/IRQ5: J1.23, J4.23, J5.23, J7.23, J8.23, J9.23, J11.23
/IRQ6: J1.22, J4.22, J5.22, J7.22, J8.22, J9.22, J11.22
/IRQ7: J1.21, J4.21, J5.21, J7.21, J8.21, J9.21, J11.21
/KBD_CLK: U16.11, U19.41
/KBD_CLK_INVERTED: U16.10, U20.1
/KBD_DATA: U19.42, U20.3
/LED_GND: D1.1, R1.1
/MRD: J1.12, J4.12, J5.12, J7.12, J8.12, J9.12, J11.12, RN2.3, U61.3
/MWR: J1.11, J4.11, J5.11, J7.11, J8.11, J9.11, J11.11, RN2.2, U61.4
/NC: J1.8, J4.8, J5.8, J7.8, J8.8, J9.8, J11.8
/NMI: J10.8, U16.4
/NMI_EN: RN3.2, U2.16, U15.17, U16.1
/NMI_EN_139: U16.2, U17.1
/NMI_INPUT: U16.3, U17.4
/OSC: R3.2, R14.2, U11.12
/OSC88: J1.30, J4.30, J5.30, J7.30, J8.30, J9.30, J11.30, R14.1
/OSC88HF: R3.1, U14.11
/PCLK: R17.2, U11.2
/PCLK88: R17.1, U14.3
/PORT_0X61_CS: U15.11, U16.8
/PORT_0X61_EN: U1.4, U16.9
/PORT_61_2: U2.13, U15.14
/PORT_61_3: U2.14, U15.15
/PORT_61_4: U2.15, U15.16
/PORT_61_6: U2.17, U15.18
/PORT_61_7: U2.18, U15.19
/PORT_61_RD: U1.12, U2.19
/POWER_GOOD: ATXPOWER1.8, R5.1
/POWER_ON: 8x8mm1.2, ATXPOWER1.16, J6.1
/RDY1: J1.41, J4.41, J5.41, J7.41, J8.41, J9.41, J11.41, R6.2, U11.4
/READY: J10.15, U11.5, U61.6
/REFRQ: J1.19, J4.19, J5.19, J7.19, J8.19, J9.19, J11.19, RN2.6, SW2.3
/RESET: J10.16, J12.1, R5.2, SW1.1, U11.11, U19.5
/RESOUT: J1.2, J4.2, J5.2, J7.2, J8.2, J9.2, J11.2, U11.10, U61.13
/SPK_EN: U2.12, U15.13, U16.5
/SPK_EN_: U16.6, U117.15
/SPK_GO: J10.10, U2.11, U15.12
/SPK_OUT: J10.9, U117.14
/SPK_PIN: U3.2, U117.12
/SPK_PIN_O: J3.1, U3.1
/T0: J2.5, R8.2, U19.2, U20.2
/T1: J2.1, R9.2, U19.43, U20.4
/TC: J1.27, J4.27, J5.27, J7.27, J8.27, J9.27, J11.27, R13.2, U63.6
/X1_8284: R4.1, U11.17, Y2.2
/X2_8284: R2.1, U11.16, Y2.1

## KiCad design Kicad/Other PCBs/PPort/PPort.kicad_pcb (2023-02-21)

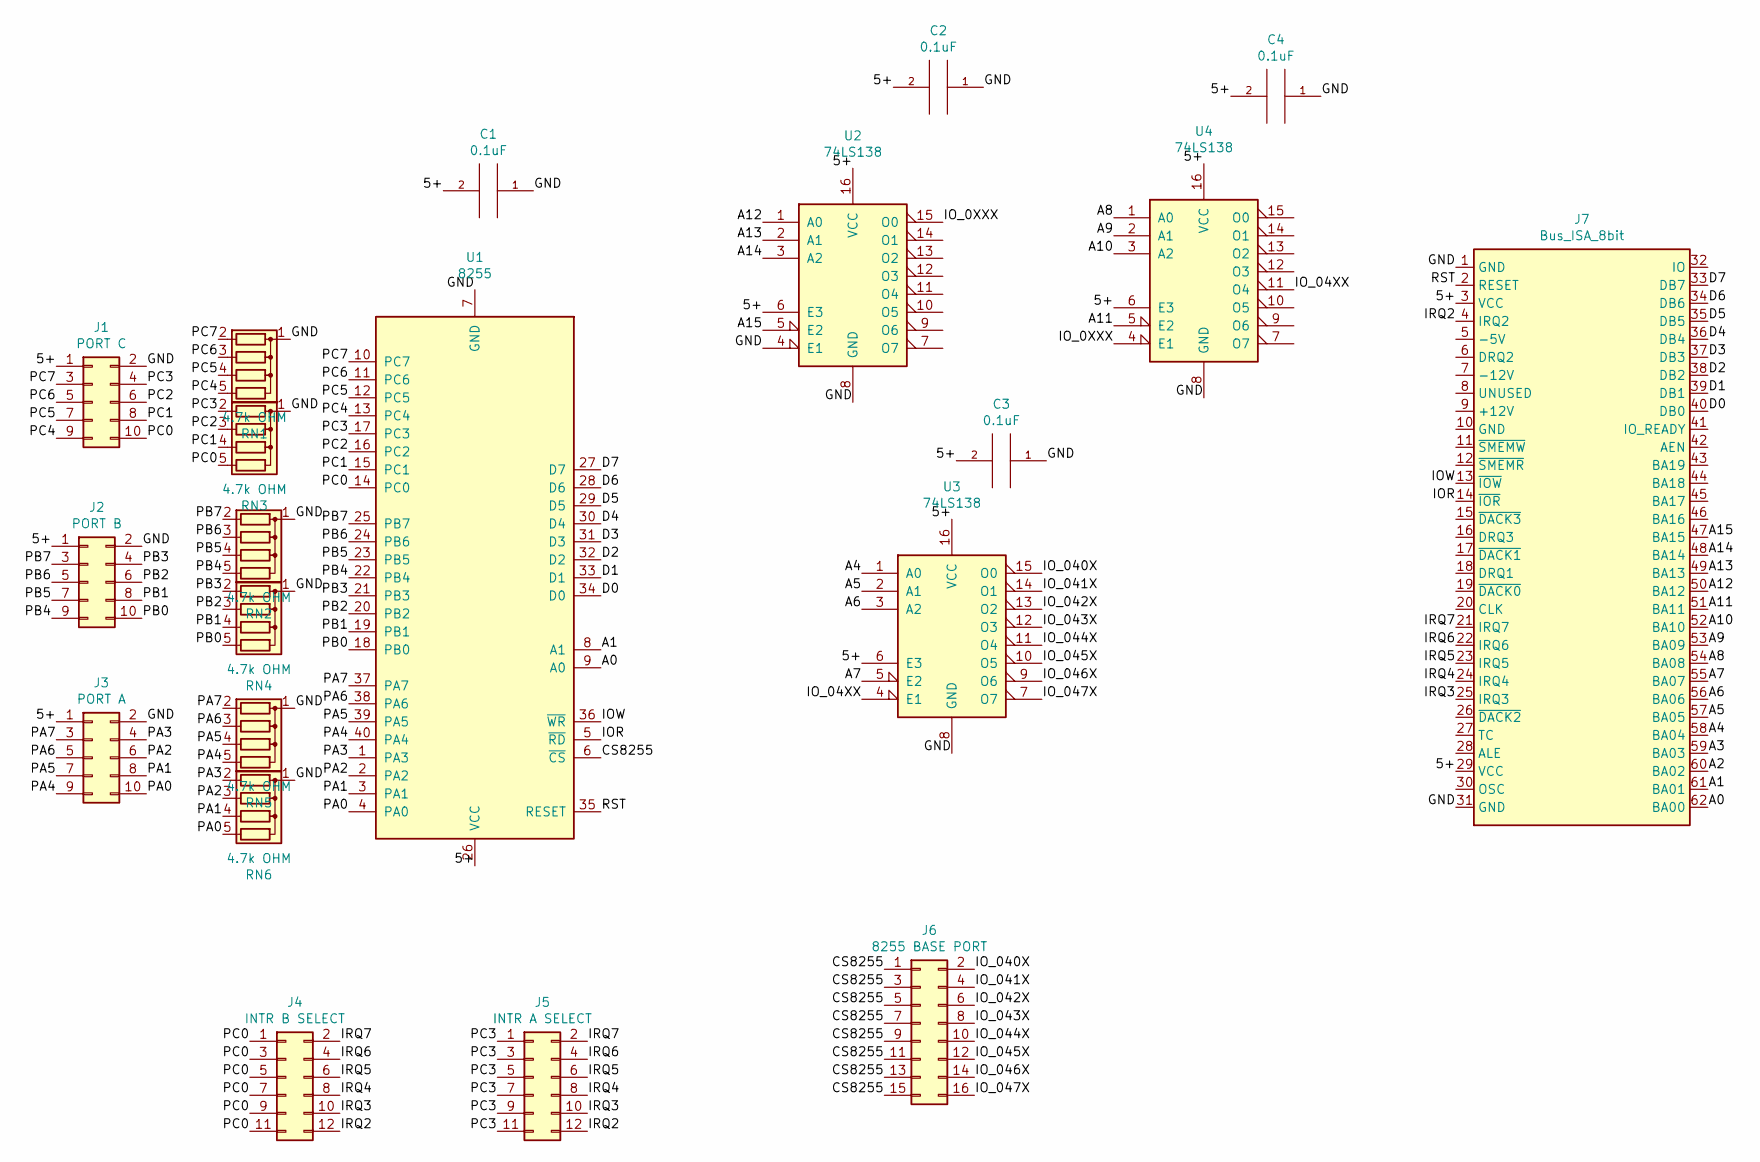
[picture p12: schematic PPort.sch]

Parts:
C1, C2, C3, C4: 0.1uF; C_Disc_D4.3mm_W1.9mm_P5.00mm
J1: PORT C; PinHeader_2x05_P2.54mm_Vertical
J2: PORT B; PinHeader_2x05_P2.54mm_Vertical
J3: PORT A; PinHeader_2x05_P2.54mm_Vertical
J4: INTR B SELECT; PinHeader_2x06_P2.54mm_Vertical
J5: INTR A SELECT; PinHeader_2x06_P2.54mm_Vertical
J6: 8255 BASE PORT; PinHeader_2x08_P2.54mm_Vertical
J7: Bus_ISA_8bit; BUS_8_BIT
RN1, RN2, RN3, RN4, RN5, RN6: 4.7k OHM; R_Array_SIP5
U1: 8255; DIP-40_W15.24mm
U2, U3, U4: 74LS138; DIP-16_W7.62mm

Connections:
/5+: C1.2, C2.2, C3.2, C4.2, J1.1, J2.1, J3.1, J7.3 (VCC), J7.29 (VCC), U1.26 (VCC), U2.6 (E3), U2.16 (VCC), U3.6 (E3), U3.16 (VCC), U4.6 (E3), U4.16 (VCC)
/A0: J7.62 (BA00), U1.9 (A0)
/A1: J7.61 (BA01), U1.8 (A1)
/A2: J7.60 (BA02)
/A3: J7.59 (BA03)
/A4: J7.58 (BA04), U3.1 (A0)
/A5: J7.57 (BA05), U3.2 (A1)
/A6: J7.56 (BA06), U3.3 (A2)
/A7: J7.55 (BA07), U3.5 (E2)
/A8: J7.54 (BA08), U4.1 (A0)
/A9: J7.53 (BA09), U4.2 (A1)
/A10: J7.52 (BA10), U4.3 (A2)
/A11: J7.51 (BA11), U4.5 (E2)
/A12: J7.50 (BA12), U2.1 (A0)
/A13: J7.49 (BA13), U2.2 (A1)
/A14: J7.48 (BA14), U2.3 (A2)
/A15: J7.47 (BA15), U2.5 (E2)
/CS8255: J6.1, J6.3, J6.5, J6.7, J6.9, J6.11, J6.13, J6.15, U1.6 (~CS~)
/D0: J7.40 (DB0), U1.34 (D0)
/D1: J7.39 (DB1), U1.33 (D1)
/D2: J7.38 (DB2), U1.32 (D2)
/D3: J7.37 (DB3), U1.31 (D3)
/D4: J7.36 (DB4), U1.30 (D4)
/D5: J7.35 (DB5), U1.29 (D5)
/D6: J7.34 (DB6), U1.28 (D6)
/D7: J7.33 (DB7), U1.27 (D7)
/GND: C1.1, C2.1, C3.1, C4.1, J1.2, J2.2, J3.2, J7.1 (GND), J7.31 (GND), RN1.1 (common), RN2.1 (common), RN3.1 (common), RN4.1 (common), RN5.1 (common), RN6.1 (common), U1.7 (GND), U2.4 (E1), U2.8 (GND), U3.8 (GND), U4.8 (GND); also elsewhere on the board
/IOR: J7.14 (~IOR), U1.5 (~RD~)
/IOW: J7.13 (~IOW), U1.36 (~WR~)
/IO_0XXX: U2.15 (O0), U4.4 (E1)
/IO_04XX: U3.4 (E1), U4.11 (O4)
/IO_040X: J6.2, U3.15 (O0)
/IO_041X: J6.4, U3.14 (O1)
/IO_042X: J6.6, U3.13 (O2)
/IO_043X: J6.8, U3.12 (O3)
/IO_044X: J6.10, U3.11 (O4)
/IO_045X: J6.12, U3.10 (O5)
/IO_046X: J6.14, U3.9 (O6)
/IO_047X: J6.16, U3.7 (O7)
/IRQ2: J4.12, J5.12, J7.4 (IRQ2)
/IRQ3: J4.10, J5.10, J7.25 (IRQ3)
/IRQ4: J4.8, J5.8, J7.24 (IRQ4)
/IRQ5: J4.6, J5.6, J7.23 (IRQ5)
/IRQ6: J4.4, J5.4, J7.22 (IRQ6)
/IRQ7: J4.2, J5.2, J7.21 (IRQ7)
/PA0: J3.10, RN6.5 (R4), U1.4 (PA0)
/PA1: J3.8, RN6.4 (R3), U1.3 (PA1)
/PA2: J3.6, RN6.3 (R2), U1.2 (PA2)
/PA3: J3.4, RN6.2 (R1), U1.1 (PA3)
/PA4: J3.9, RN5.5 (R4), U1.40 (PA4)
/PA5: J3.7, RN5.4 (R3), U1.39 (PA5)
/PA6: J3.5, RN5.3 (R2), U1.38 (PA6)
/PA7: J3.3, RN5.2 (R1), U1.37 (PA7)
/PB0: J2.10, RN4.5 (R4), U1.18 (PB0)
/PB1: J2.8, RN4.4 (R3), U1.19 (PB1)
/PB2: J2.6, RN4.3 (R2), U1.20 (PB2)
/PB3: J2.4, RN4.2 (R1), U1.21 (PB3)
/PB4: J2.9, RN2.5 (R4), U1.22 (PB4)
/PB5: J2.7, RN2.4 (R3), U1.23 (PB5)
/PB6: J2.5, RN2.3 (R2), U1.24 (PB6)
/PB7: J2.3, RN2.2 (R1), U1.25 (PB7)
/PC0: J1.10, J4.1, J4.3, J4.5, J4.7, J4.9, J4.11, RN3.5 (R4), U1.14 (PC0)
/PC1: J1.8, RN3.4 (R3), U1.15 (PC1)
/PC2: J1.6, RN3.3 (R2), U1.16 (PC2)
/PC3: J1.4, J5.1, J5.3, J5.5, J5.7, J5.9, J5.11, RN3.2 (R1), U1.17 (PC3)
/PC4: J1.9, RN1.5 (R4), U1.13 (PC4)
/PC5: J1.7, RN1.4 (R3), U1.12 (PC5)
/PC6: J1.5, RN1.3 (R2), U1.11 (PC6)
/PC7: J1.3, RN1.2 (R1), U1.10 (PC7)
/RST: J7.2 (RESET), U1.35 (RESET)

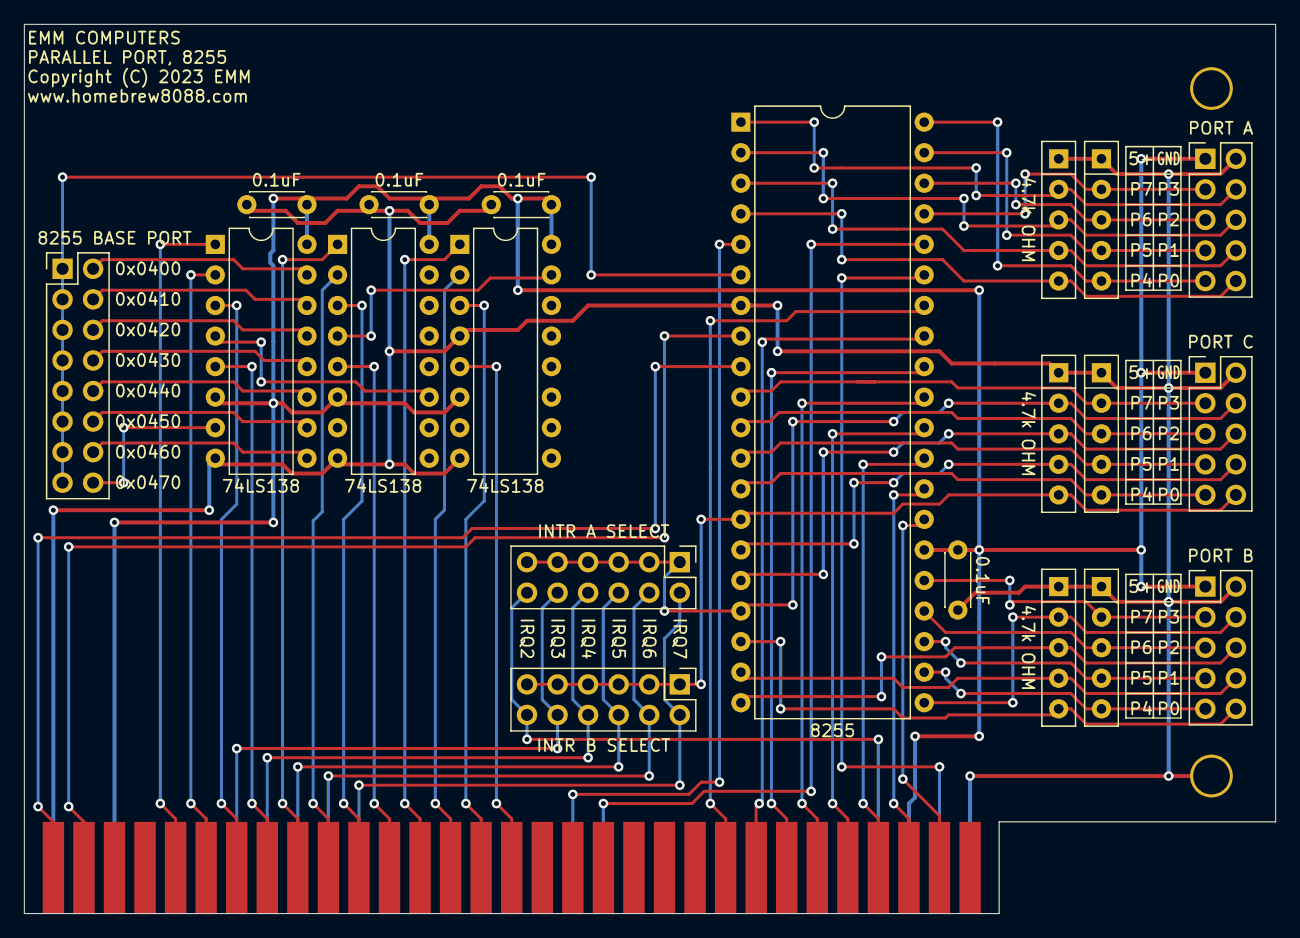
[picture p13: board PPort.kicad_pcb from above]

Board: 2 copper layers, 104.0 x 73.9 mm, 23 parts (0 on the bottom side), 68 nets.

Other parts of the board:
R: L; Large_Via
R#2: L; Large_Via

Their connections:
/GND: R.1; also elsewhere on the board

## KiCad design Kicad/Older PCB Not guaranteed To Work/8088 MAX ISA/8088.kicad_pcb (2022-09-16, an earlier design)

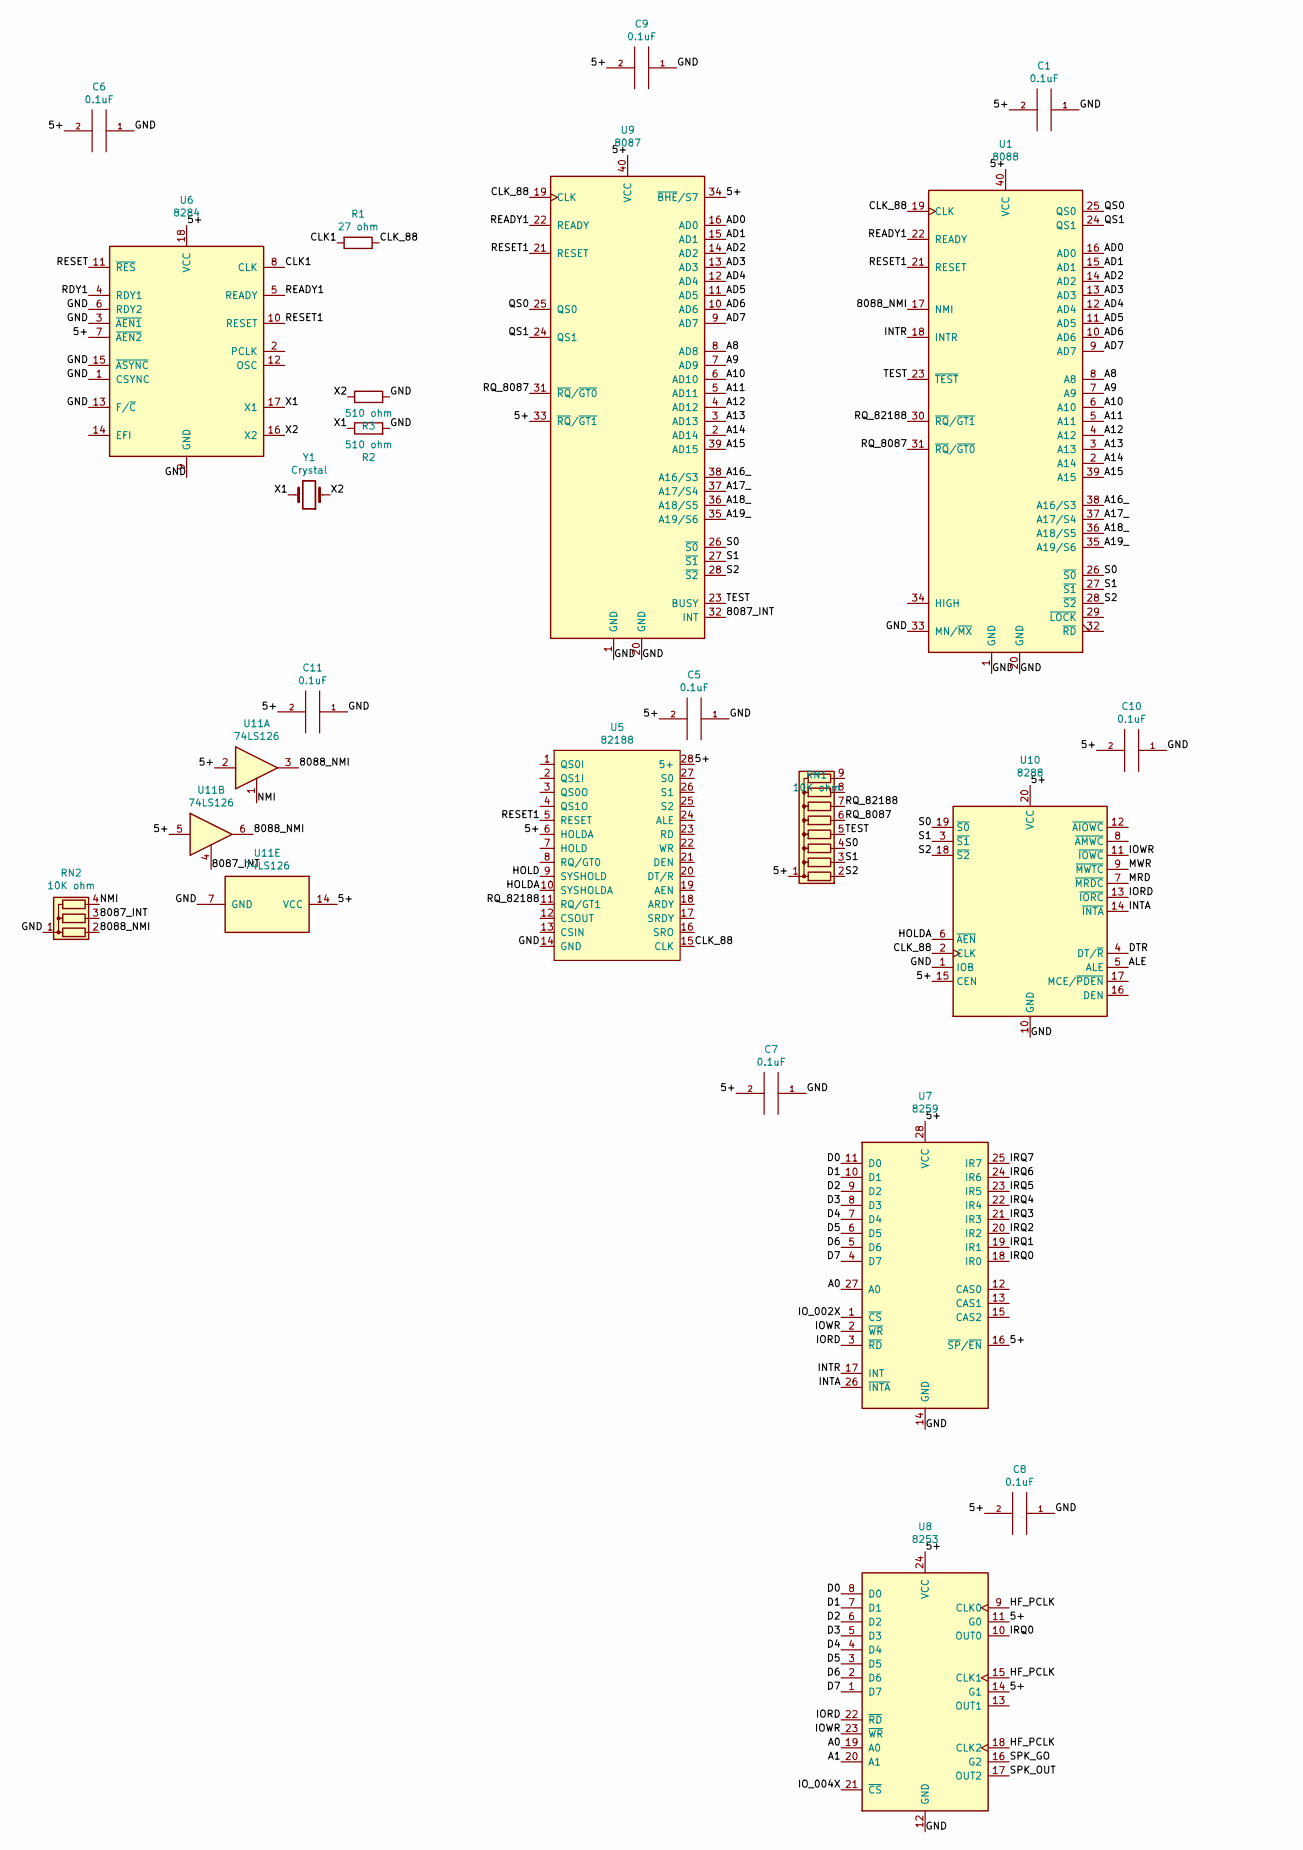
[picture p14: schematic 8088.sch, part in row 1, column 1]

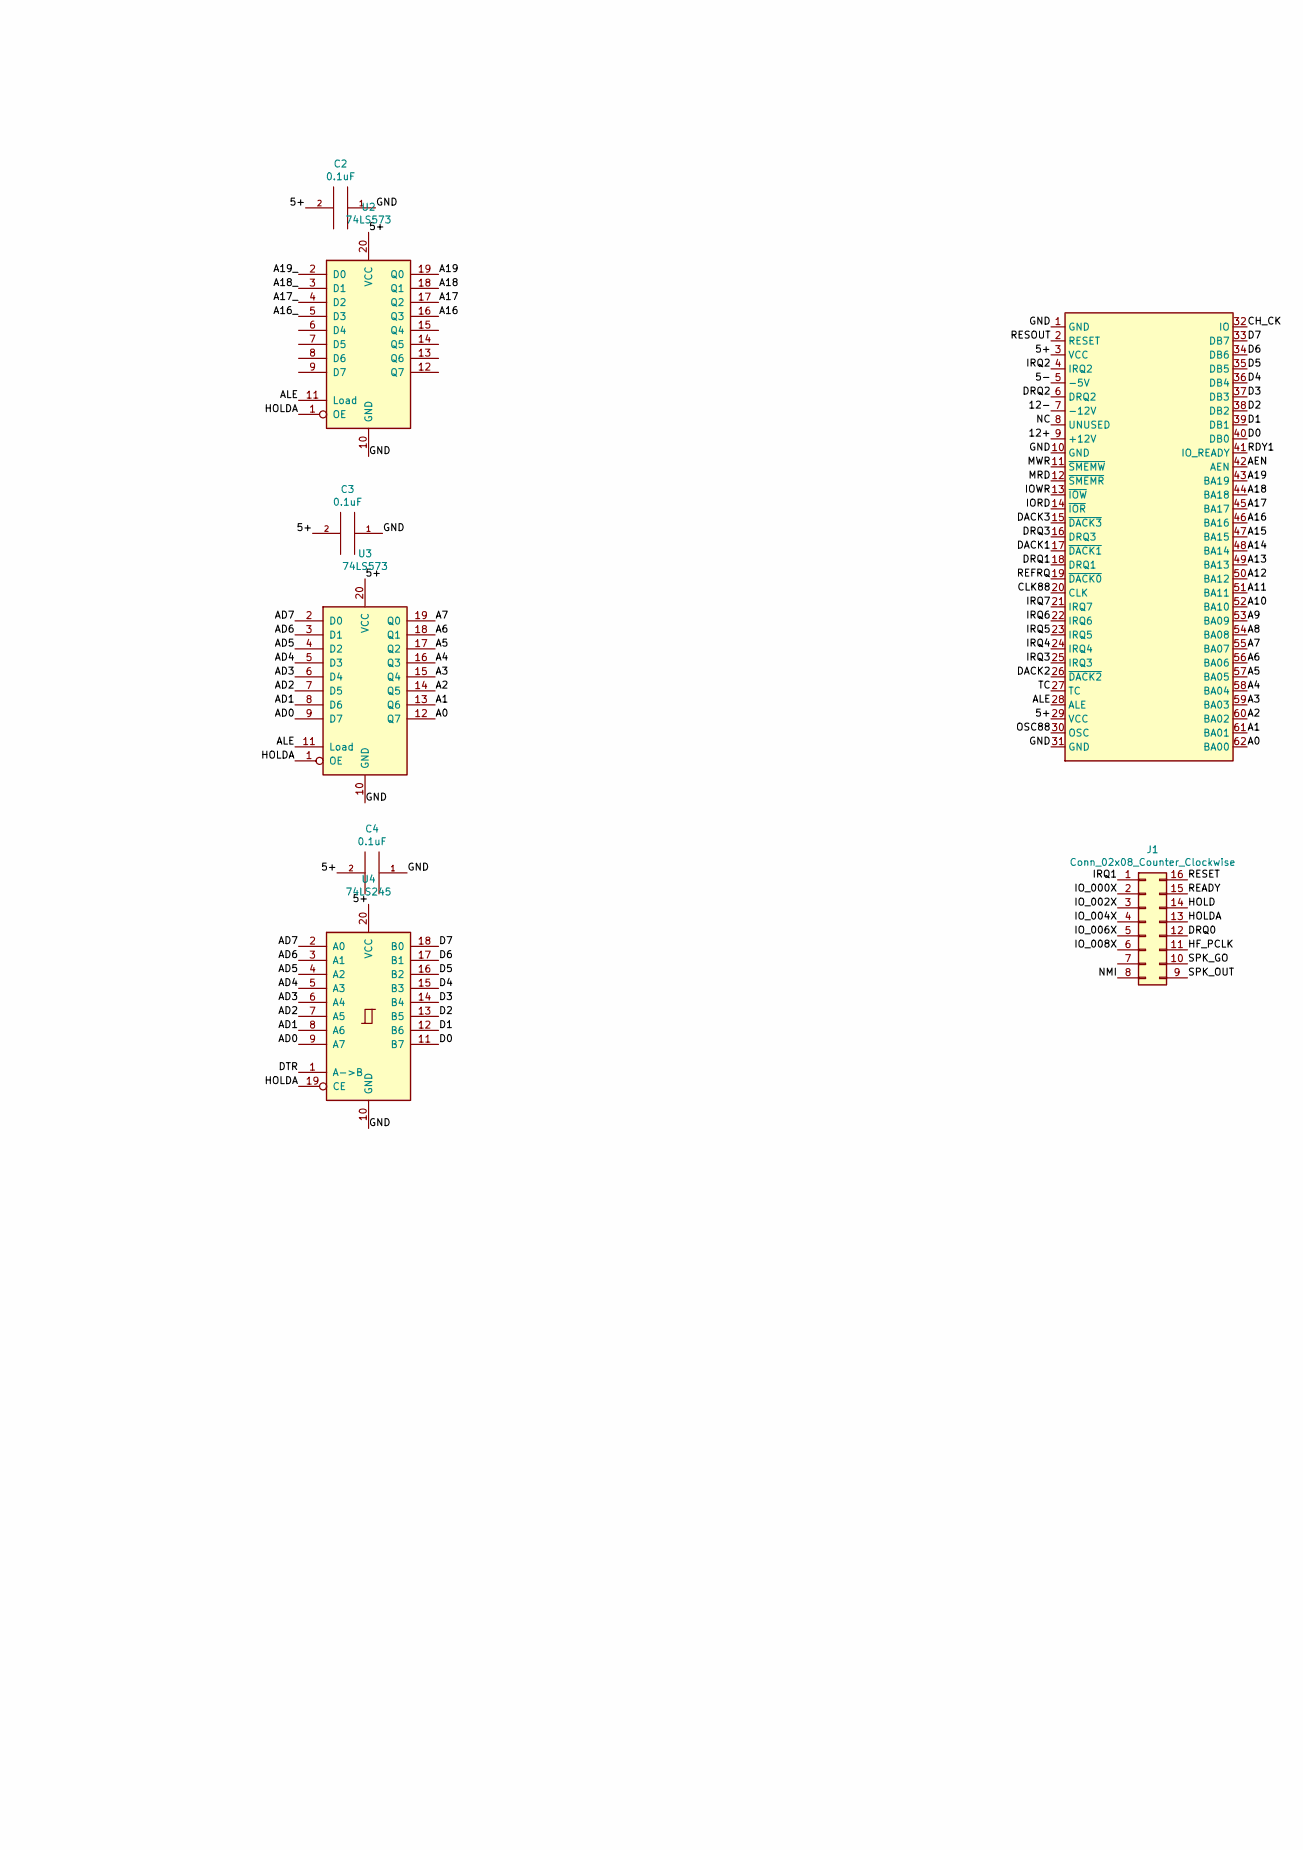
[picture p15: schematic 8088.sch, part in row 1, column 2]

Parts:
C1, C2, C3, C4, C5, C6, C7, C8, C9, C10, C11: 0.1uF; C_Disc_D4.3mm_W1.9mm_P5.00mm
J1: Conn_02x08_Counter_Clockwise; 16_EDGE_CARD_BUS
J9: Bus_ISA_8bit; BUS_8_BIT
R1: 27 ohm; R_Axial_DIN0207_L6.3mm_D2.5mm_P10.16mm_Horizontal
R2, R3: 510 ohm; R_Axial_DIN0207_L6.3mm_D2.5mm_P10.16mm_Horizontal
RN1: 10K ohm; R_Array_SIP9
RN2: 10K ohm; R_Array_SIP4
U1: 8088; DIP-40_W15.24mm
U2, U3: 74LS573; DIP-20_W7.62mm
U4: 74LS245; DIP-20_W7.62mm
U5: 82188; DIP-28_W15.24mm
U6: 8284; DIP-18_W7.62mm
U7: 8259; DIP-28_W15.24mm
U8: 8253; DIP-24_W15.24mm
U9: 8087; DIP-40_W15.24mm
U10: 8288; DIP-20_W7.62mm
U11: 74LS126; DIP-14_W7.62mm
Y1: Crystal; Crystal_HC18-U_Vertical

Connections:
/5+: C1.2, C2.2, C3.2, C4.2, C5.2, C6.2, C7.2, C8.2, C9.2, C10.2, C11.2, J9.3 (VCC), J9.29 (VCC), RN1.1 (common), U1.40 (VCC), U2.20 (VCC), U3.20 (VCC), U4.20 (VCC), U5.6 (HOLDA), U5.28 (5+), U6.7 (~AEN2~), U6.18 (VCC), U7.16 (~SP~/~EN~), U7.28 (VCC), U8.11 (G0), U8.14 (G1), U8.24 (VCC), U9.33 (~RQ~/~GT1~), U9.34 (~BHE~/S7), U9.40 (VCC), U10.15 (CEN), U10.20 (VCC), U11.2, U11.5, U11.14 (VCC)
/5-: J9.5 (-5V)
/12+: J9.9 (+12V)
/12-: J9.7 (-12V)
/8087_INT: RN2.3 (R2), U9.32 (INT), U11.4
/8088_NMI: RN2.2 (R1), U1.17 (NMI), U11.3, U11.6
/A0: J9.62 (BA00), U3.12 (Q7), U7.27 (A0), U8.19 (A0)
/A1: J9.61 (BA01), U3.13 (Q6), U8.20 (A1)
/A2: J9.60 (BA02), U3.14 (Q5)
/A3: J9.59 (BA03), U3.15 (Q4)
/A4: J9.58 (BA04), U3.16 (Q3)
/A5: J9.57 (BA05), U3.17 (Q2)
/A6: J9.56 (BA06), U3.18 (Q1)
/A7: J9.55 (BA07), U3.19 (Q0)
/A8: J9.54 (BA08), U1.8 (A8), U9.8 (AD8)
/A9: J9.53 (BA09), U1.7 (A9), U9.7 (AD9)
/A10: J9.52 (BA10), U1.6 (A10), U9.6 (AD10)
/A11: J9.51 (BA11), U1.5 (A11), U9.5 (AD11)
/A12: J9.50 (BA12), U1.4 (A12), U9.4 (AD12)
/A13: J9.49 (BA13), U1.3 (A13), U9.3 (AD13)
/A14: J9.48 (BA14), U1.2 (A14), U9.2 (AD14)
/A15: J9.47 (BA15), U1.39 (A15), U9.39 (AD15)
/A16: J9.46 (BA16), U2.16 (Q3)
/A16_: U1.38 (A16/S3), U2.5 (D3), U9.38 (A16/S3)
/A17: J9.45 (BA17), U2.17 (Q2)
/A17_: U1.37 (A17/S4), U2.4 (D2), U9.37 (A17/S4)
/A18: J9.44 (BA18), U2.18 (Q1)
/A18_: U1.36 (A18/S5), U2.3 (D1), U9.36 (A18/S5)
/A19: J9.43 (BA19), U2.19 (Q0)
/A19_: U1.35 (A19/S6), U2.2 (D0), U9.35 (A19/S6)
/AD0: U1.16 (AD0), U3.9 (D7), U4.9 (A7), U9.16 (AD0)
/AD1: U1.15 (AD1), U3.8 (D6), U4.8 (A6), U9.15 (AD1)
/AD2: U1.14 (AD2), U3.7 (D5), U4.7 (A5), U9.14 (AD2)
/AD3: U1.13 (AD3), U3.6 (D4), U4.6 (A4), U9.13 (AD3)
/AD4: U1.12 (AD4), U3.5 (D3), U4.5 (A3), U9.12 (AD4)
/AD5: U1.11 (AD5), U3.4 (D2), U4.4 (A2), U9.11 (AD5)
/AD6: U1.10 (AD6), U3.3 (D1), U4.3 (A1), U9.10 (AD6)
/AD7: U1.9 (AD7), U3.2 (D0), U4.2 (A0), U9.9 (AD7)
/AEN: J9.42 (AEN)
/ALE: J9.28 (ALE), U2.11 (Load), U3.11 (Load), U10.5 (ALE)
/CH_CK: J9.32 (IO)
/CLK1: R1.2, U6.8 (CLK)
/CLK88: J9.20 (CLK)
/CLK_88: R1.1, U1.19 (CLK), U5.15 (CLK), U9.19 (CLK), U10.2 (CLK)
/D0: J9.40 (DB0), U4.11 (B7), U7.11 (D0), U8.8 (D0)
/D1: J9.39 (DB1), U4.12 (B6), U7.10 (D1), U8.7 (D1)
/D2: J9.38 (DB2), U4.13 (B5), U7.9 (D2), U8.6 (D2)
/D3: J9.37 (DB3), U4.14 (B4), U7.8 (D3), U8.5 (D3)
/D4: J9.36 (DB4), U4.15 (B3), U7.7 (D4), U8.4 (D4)
/D5: J9.35 (DB5), U4.16 (B2), U7.6 (D5), U8.3 (D5)
/D6: J9.34 (DB6), U4.17 (B1), U7.5 (D6), U8.2 (D6)
/D7: J9.33 (DB7), U4.18 (B0), U7.4 (D7), U8.1 (D7)
/DACK1: J9.17 (~DACK1)
/DACK2: J9.26 (~DACK2)
/DACK3: J9.15 (~DACK3)
/DRQ0: J1.12
/DRQ1: J9.18 (DRQ1)
/DRQ2: J9.6 (DRQ2)
/DRQ3: J9.16 (DRQ3)
/DTR: U4.1 (A->B), U10.4 (DT/~R~)
/GND: C1.1, C2.1, C3.1, C4.1, C5.1, C6.1, C7.1, C8.1, C9.1, C10.1, C11.1, J9.1 (GND), J9.10 (GND), J9.31 (GND), R2.2, R3.2, RN2.1 (common), U1.1 (GND), U1.20 (GND), U1.33 (MN/~MX~), U2.10 (GND), U3.10 (GND), U4.10 (GND), U5.14 (GND), U6.1 (CSYNC), U6.3 (~AEN1~), U6.6 (RDY2), U6.9 (GND), U6.13 (F/~C~), U6.15 (~ASYNC~), U7.14 (GND), U8.12 (GND), U9.1 (GND), U9.20 (GND), U10.1 (IOB), U10.10 (GND), U11.7 (GND); also elsewhere on the board
/HF_PCLK: J1.11, U8.9 (CLK0), U8.15 (CLK1), U8.18 (CLK2)
/HOLD: J1.14, U5.9 (SYSHOLD)
/HOLDA: J1.13, U2.1 (OE), U3.1 (OE), U4.19 (CE), U5.10 (SYSHOLDA), U10.6 (~AEN~)
/INTA: U7.26 (~INTA~), U10.14 (~INTA~)
/INTR: U1.18 (INTR), U7.17 (INT)
/IORD: J9.14 (~IOR), U7.3 (~RD~), U8.22 (~RD~), U10.13 (~IORC~)
/IOWR: J9.13 (~IOW), U7.2 (~WR~), U8.23 (~WR~), U10.11 (~IOWC~)
/IO_000X: J1.2
/IO_002X: J1.3, U7.1 (~CS~)
/IO_004X: J1.4, U8.21 (~CS~)
/IO_006X: J1.5
/IO_008X: J1.6
/IRQ0: U7.18 (IR0), U8.10 (OUT0)
/IRQ1: J1.1, U7.19 (IR1)
/IRQ2: J9.4 (IRQ2), U7.20 (IR2)
/IRQ3: J9.25 (IRQ3), U7.21 (IR3)
/IRQ4: J9.24 (IRQ4), U7.22 (IR4)
/IRQ5: J9.23 (IRQ5), U7.23 (IR5)
/IRQ6: J9.22 (IRQ6), U7.24 (IR6)
/IRQ7: J9.21 (IRQ7), U7.25 (IR7)
/MRD: J9.12 (~SMEMR), U10.7 (~MRDC~)
/MWR: J9.11 (~SMEMW), U10.9 (~MWTC~)
/NC: J9.8 (UNUSED)
/NMI: J1.8, RN2.4 (R3), U11.1
/OSC88: J9.30 (OSC)
/QS0: U1.25 (QS0), U9.25 (QS0)
/QS1: U1.24 (QS1), U9.24 (QS1)
/RDY1: J9.41 (IO_READY), U6.4 (RDY1)
/READY: J1.15
/READY1: U1.22 (READY), U6.5 (READY), U9.22 (READY)
/REFRQ: J9.19 (~DACK0)
/RESET: J1.16, U6.11 (~RES~)
/RESET1: U1.21 (RESET), U5.5 (RESET), U6.10 (RESET), U9.21 (RESET)
/RESOUT: J9.2 (RESET)
/RQ_8087: RN1.6 (R5), U1.31 (~RQ~/~GT0~), U9.31 (~RQ~/~GT0~)
/RQ_82188: RN1.7 (R6), U1.30 (~RQ~/~GT1~), U5.11 (RQ/GT1)
/S0: RN1.4 (R3), U1.26 (~S0~), U9.26 (~S0~), U10.19 (~S0~)
/S1: RN1.3 (R2), U1.27 (~S1~), U9.27 (~S1~), U10.3 (~S1~)
/S2: RN1.2 (R1), U1.28 (~S2~), U9.28 (~S2~), U10.18 (~S2~)
/SPK_GO: J1.10, U8.16 (G2)
/SPK_OUT: J1.9, U8.17 (OUT2)
/TC: J9.27 (TC)
/TEST: RN1.5 (R4), U1.23 (~TEST~), U9.23 (BUSY)
/X1: R2.1, U6.17 (X1), Y1.2
/X2: R3.1, U6.16 (X2), Y1.1

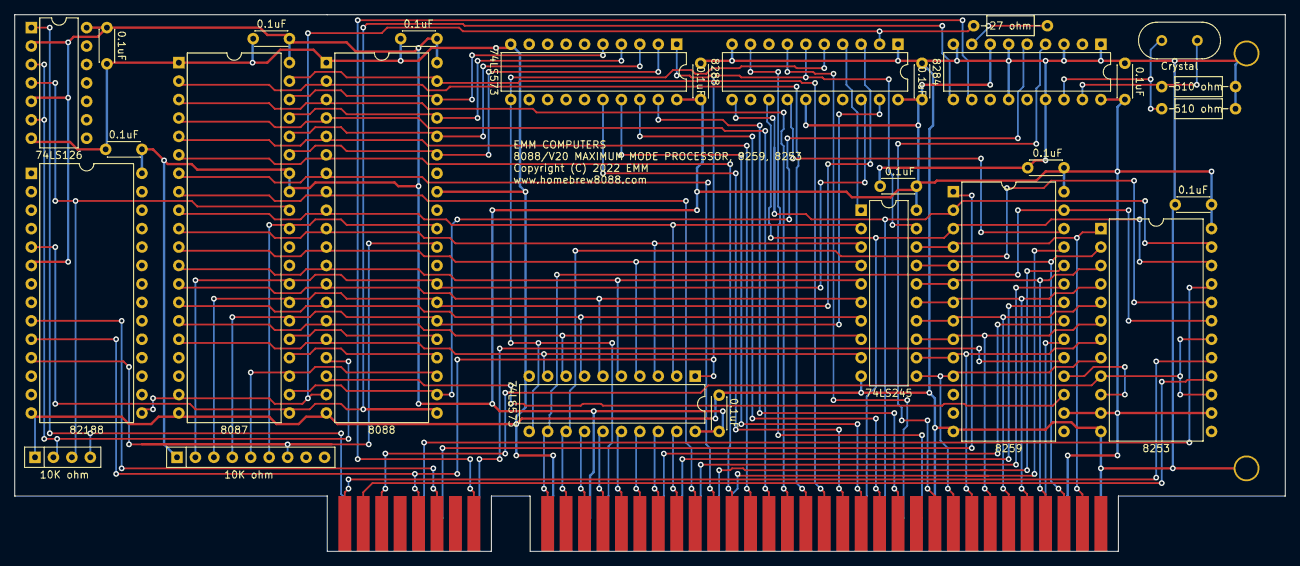
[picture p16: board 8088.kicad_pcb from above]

Board: 2 copper layers, 175.0 x 73.9 mm, 32 parts (0 on the bottom side), 84 nets.

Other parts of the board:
R: L; Large_Via
R#2: L; Large_Via

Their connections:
/GND: R.1, R#2.1; also elsewhere on the board

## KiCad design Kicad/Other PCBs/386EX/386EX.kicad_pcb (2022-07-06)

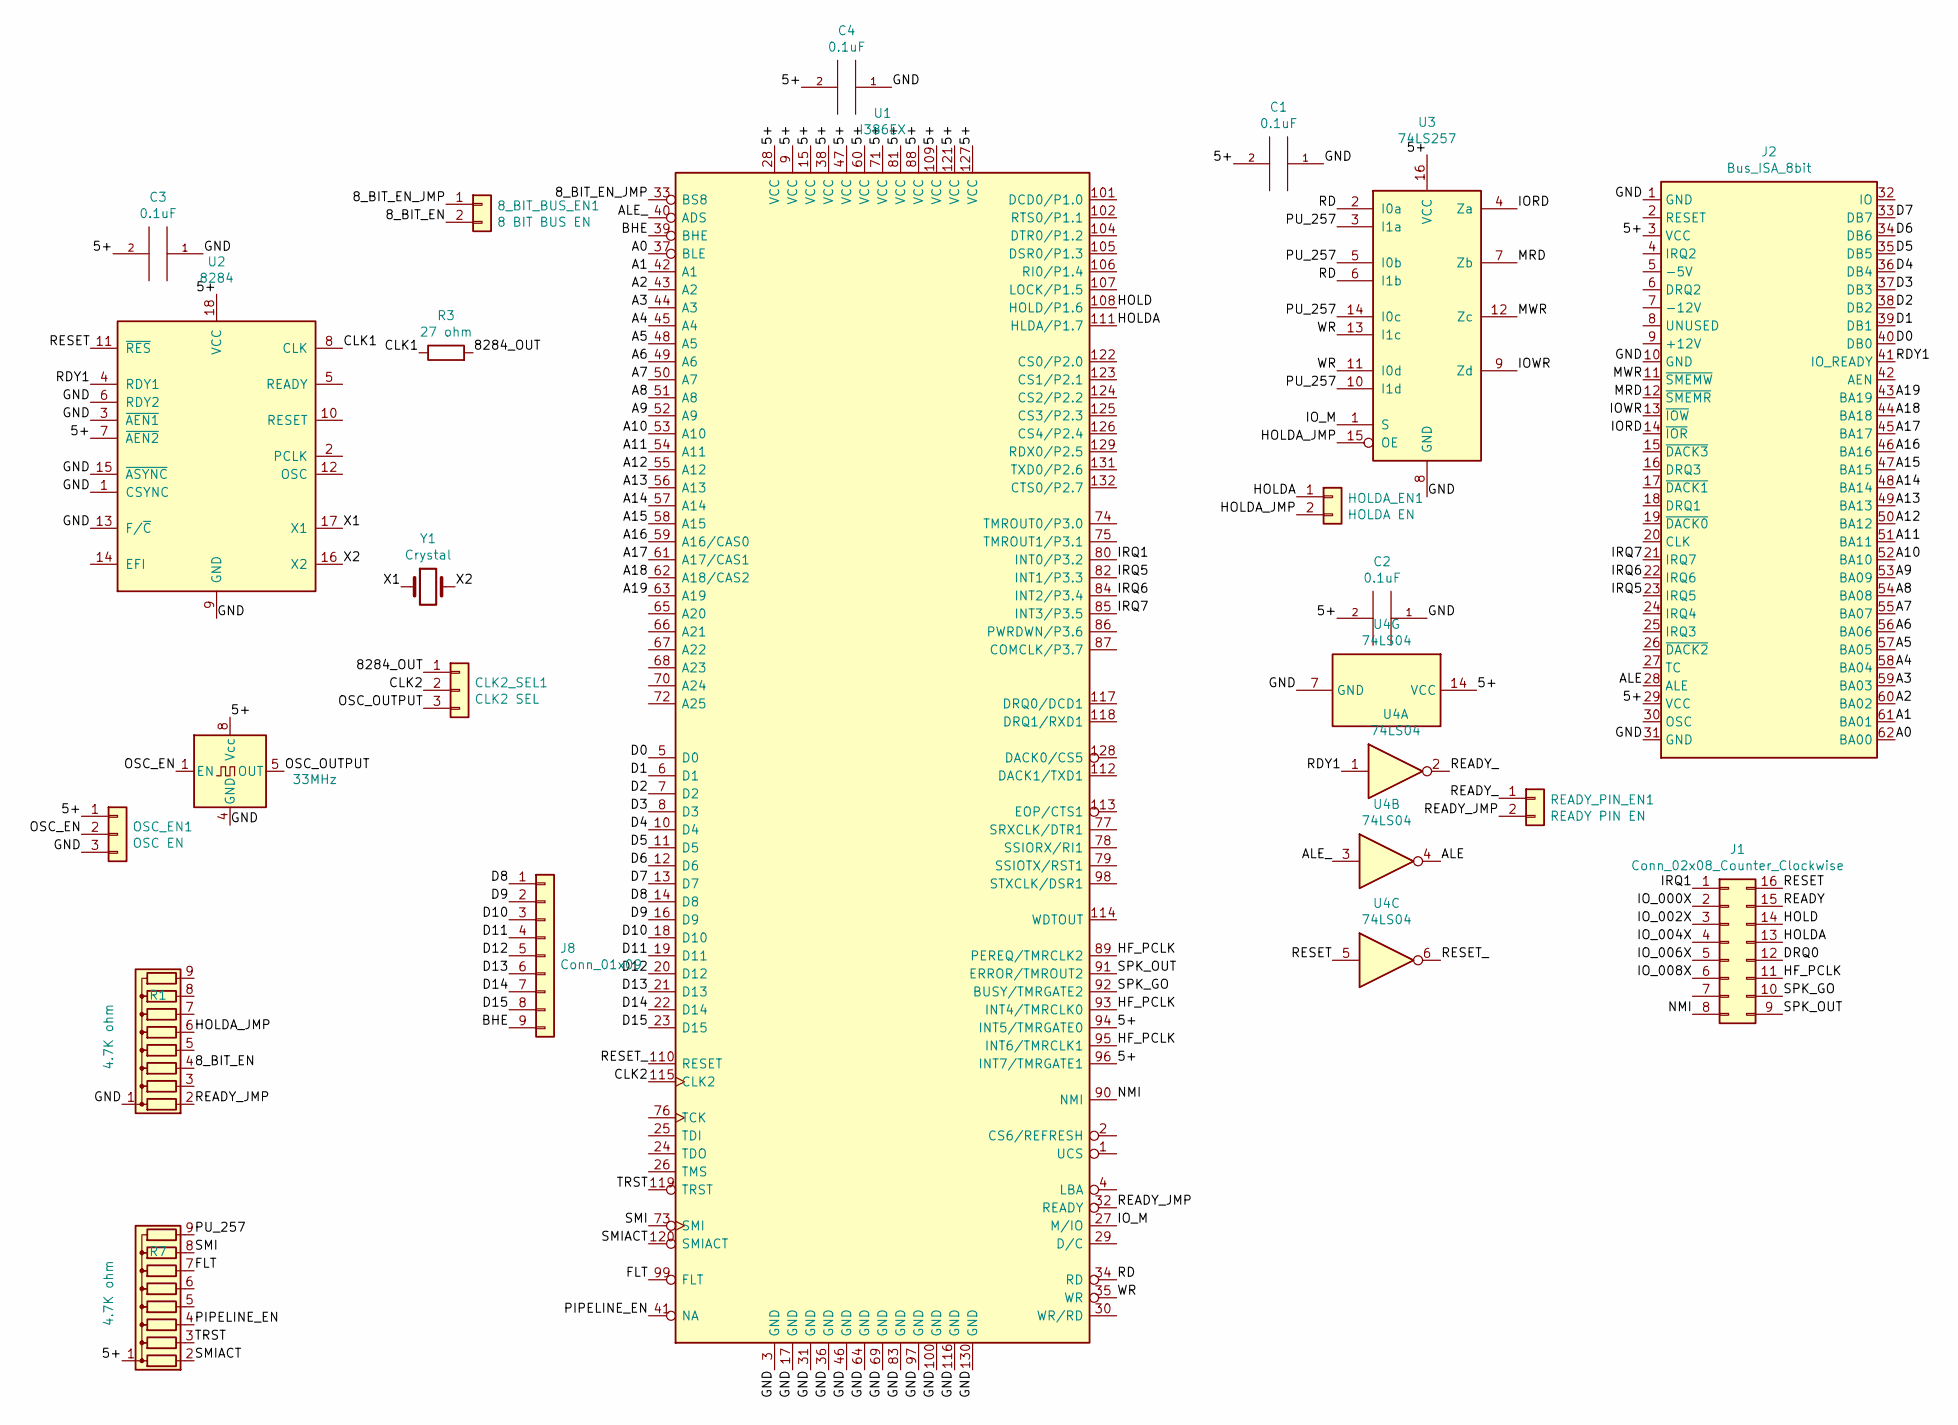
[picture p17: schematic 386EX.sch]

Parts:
8_BIT_BUS_EN1: 8 BIT BUS EN; PinHeader_1x02_P2.54mm_Vertical
C1, C2, C3, C4: 0.1uF; C_Disc_D4.3mm_W1.9mm_P5.00mm
CLK2_SEL1: CLK2 SEL; PinHeader_1x03_P2.54mm_Vertical
HOLDA_EN1: HOLDA EN; PinHeader_1x02_P2.54mm_Vertical
J1: Conn_02x08_Counter_Clockwise; 16_EDGE_CARD_BUS
J2: Bus_ISA_8bit; BUS_8_BIT
J8: Conn_01x09; PinHeader_1x09_P2.54mm_Vertical
OSC_EN1: OSC EN; PinHeader_1x03_P2.54mm_Vertical
R1, R7: 4.7K ohm; R_Array_SIP9
R3: 27 ohm; R_Axial_DIN0207_L6.3mm_D2.5mm_P10.16mm_Horizontal
READY_PIN_EN1: READY PIN EN; PinHeader_1x02_P2.54mm_Vertical
U1: I386EX; PQFP-132_24x24mm_P0.635mm_i386
U2: 8284; DIP-18_W7.62mm
U3: 74LS257; DIP-16_W7.62mm
U4: 74LS04; DIP-14_W7.62mm
X1: 33MHz; Oscillator_DIP-8
Y1: Crystal; Crystal_HC18-U_Vertical

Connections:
/5+: C1.2, C2.2, C3.2, C4.2, J2.3 (VCC), J2.29 (VCC), OSC_EN1.1, R7.1 (common), U1.9 (VCC), U1.15 (VCC), U1.28 (VCC), U1.38 (VCC), U1.47 (VCC), U1.60 (VCC), U1.71 (VCC), U1.81 (VCC), U1.88 (VCC), U1.94 (INT5/TMRGATE0), U1.96 (INT7/TMRGATE1), U1.109 (VCC), U1.121 (VCC), U1.127 (VCC), U2.7 (~AEN2~), U2.18 (VCC), U3.16 (VCC), U4.14 (VCC), X1.8 (Vcc)
/8_BIT_EN: 8_BIT_BUS_EN1.2, R1.4 (R3)
/8_BIT_EN_JMP: 8_BIT_BUS_EN1.1, U1.33 (BS8)
/8284_OUT: CLK2_SEL1.1, R3.2
/A0: J2.62 (BA00), U1.37 (BLE)
/A1: J2.61 (BA01), U1.42 (A1)
/A2: J2.60 (BA02), U1.43 (A2)
/A3: J2.59 (BA03), U1.44 (A3)
/A4: J2.58 (BA04), U1.45 (A4)
/A5: J2.57 (BA05), U1.48 (A5)
/A6: J2.56 (BA06), U1.49 (A6)
/A7: J2.55 (BA07), U1.50 (A7)
/A8: J2.54 (BA08), U1.51 (A8)
/A9: J2.53 (BA09), U1.52 (A9)
/A10: J2.52 (BA10), U1.53 (A10)
/A11: J2.51 (BA11), U1.54 (A11)
/A12: J2.50 (BA12), U1.55 (A12)
/A13: J2.49 (BA13), U1.56 (A13)
/A14: J2.48 (BA14), U1.57 (A14)
/A15: J2.47 (BA15), U1.58 (A15)
/A16: J2.46 (BA16), U1.59 (A16/CAS0)
/A17: J2.45 (BA17), U1.61 (A17/CAS1)
/A18: J2.44 (BA18), U1.62 (A18/CAS2)
/A19: J2.43 (BA19), U1.63 (A19)
/ALE: J2.28 (ALE), U4.4
/ALE_: U1.40 (ADS), U4.3
/BHE: J8.9, U1.39 (BHE)
/CLK1: R3.1, U2.8 (CLK)
/CLK2: CLK2_SEL1.2, U1.115 (CLK2)
/D0: J2.40 (DB0), U1.5 (D0)
/D1: J2.39 (DB1), U1.6 (D1)
/D2: J2.38 (DB2), U1.7 (D2)
/D3: J2.37 (DB3), U1.8 (D3)
/D4: J2.36 (DB4), U1.10 (D4)
/D5: J2.35 (DB5), U1.11 (D5)
/D6: J2.34 (DB6), U1.12 (D6)
/D7: J2.33 (DB7), U1.13 (D7)
/D8: J8.1, U1.14 (D8)
/D9: J8.2, U1.16 (D9)
/D10: J8.3, U1.18 (D10)
/D11: J8.4, U1.19 (D11)
/D12: J8.5, U1.20 (D12)
/D13: J8.6, U1.21 (D13)
/D14: J8.7, U1.22 (D14)
/D15: J8.8, U1.23 (D15)
/DRQ0: J1.12
/FLT: R7.7 (R6), U1.99 (FLT)
/GND: C1.1, C2.1, C3.1, C4.1, J2.1 (GND), J2.10 (GND), J2.31 (GND), OSC_EN1.3, R1.1 (common), U1.3 (GND), U1.17 (GND), U1.31 (GND), U1.36 (GND), U1.46 (GND), U1.64 (GND), U1.69 (GND), U1.83 (GND), U1.97 (GND), U1.100 (GND), U1.116 (GND), U1.130 (GND), U2.1 (CSYNC), U2.3 (~AEN1~), U2.6 (RDY2), U2.9 (GND), U2.13 (F/~C~), U2.15 (~ASYNC~), U3.8 (GND), U4.7 (GND), X1.4 (GND)
/HF_PCLK: J1.11, U1.89 (PEREQ/TMRCLK2), U1.93 (INT4/TMRCLK0), U1.95 (INT6/TMRCLK1)
/HOLD: J1.14, U1.108 (HOLD/P1.6)
/HOLDA: HOLDA_EN1.1, J1.13, U1.111 (HLDA/P1.7)
/HOLDA_JMP: HOLDA_EN1.2, R1.6 (R5), U3.15 (OE)
/IORD: J2.14 (~IOR), U3.4 (Za)
/IOWR: J2.13 (~IOW), U3.9 (Zd)
/IO_000X: J1.2
/IO_002X: J1.3
/IO_004X: J1.4
/IO_006X: J1.5
/IO_008X: J1.6
/IO_M: U1.27 (M/IO), U3.1 (S)
/IRQ1: J1.1, U1.80 (INT0/P3.2)
/IRQ5: J2.23 (IRQ5), U1.82 (INT1/P3.3)
/IRQ6: J2.22 (IRQ6), U1.84 (INT2/P3.4)
/IRQ7: J2.21 (IRQ7), U1.85 (INT3/P3.5)
/MRD: J2.12 (~SMEMR), U3.7 (Zb)
/MWR: J2.11 (~SMEMW), U3.12 (Zc)
/NMI: J1.8, U1.90 (NMI)
/OSC_EN: OSC_EN1.2, X1.1 (EN)
/OSC_OUTPUT: CLK2_SEL1.3, X1.5 (OUT)
/PIPELINE_EN: R7.4 (R3), U1.41 (NA)
/PU_257: R7.9 (R8), U3.3 (I1a), U3.5 (I0b), U3.10 (I1d), U3.14 (I0c)
/RD: U1.34 (RD), U3.2 (I0a), U3.6 (I1b)
/RDY1: J2.41 (IO_READY), U2.4 (RDY1), U4.1
/READY: J1.15
/READY_: READY_PIN_EN1.1, U4.2
/READY_JMP: R1.2 (R1), READY_PIN_EN1.2, U1.32 (READY)
/RESET: J1.16, U2.11 (~RES~), U4.5
/RESET_: U1.110 (RESET), U4.6
/SMI: R7.8 (R7), U1.73 (SMI)
/SMIACT: R7.2 (R1), U1.120 (SMIACT)
/SPK_GO: J1.10, U1.92 (BUSY/TMRGATE2)
/SPK_OUT: J1.9, U1.91 (ERROR/TMROUT2)
/TRST: R7.3 (R2), U1.119 (TRST)
/WR: U1.35 (WR), U3.11 (I0d), U3.13 (I1c)
/X1: U2.17 (X1), Y1.1
/X2: U2.16 (X2), Y1.2

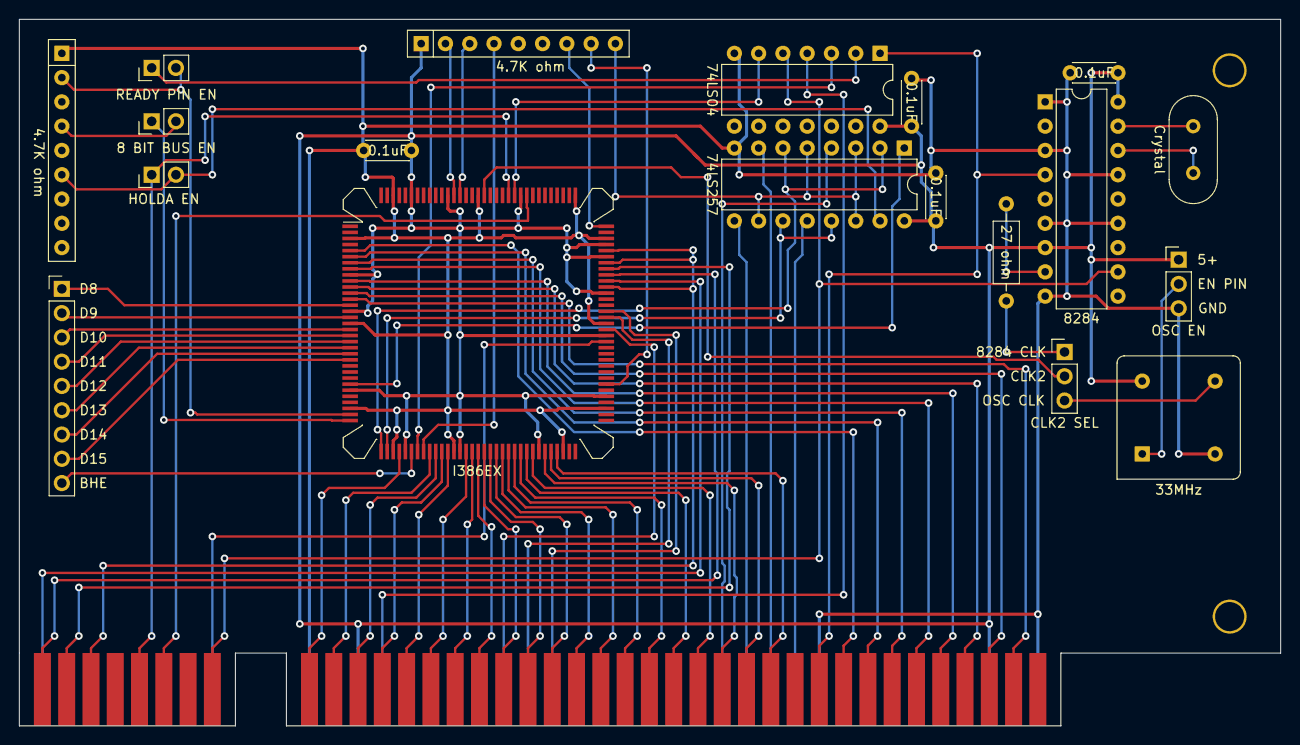
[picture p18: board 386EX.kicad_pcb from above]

Board: 2 copper layers, 132.0 x 73.9 mm, 23 parts (0 on the bottom side), 79 nets.

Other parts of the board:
R: L; Large_Via
R#2: L; Large_Via

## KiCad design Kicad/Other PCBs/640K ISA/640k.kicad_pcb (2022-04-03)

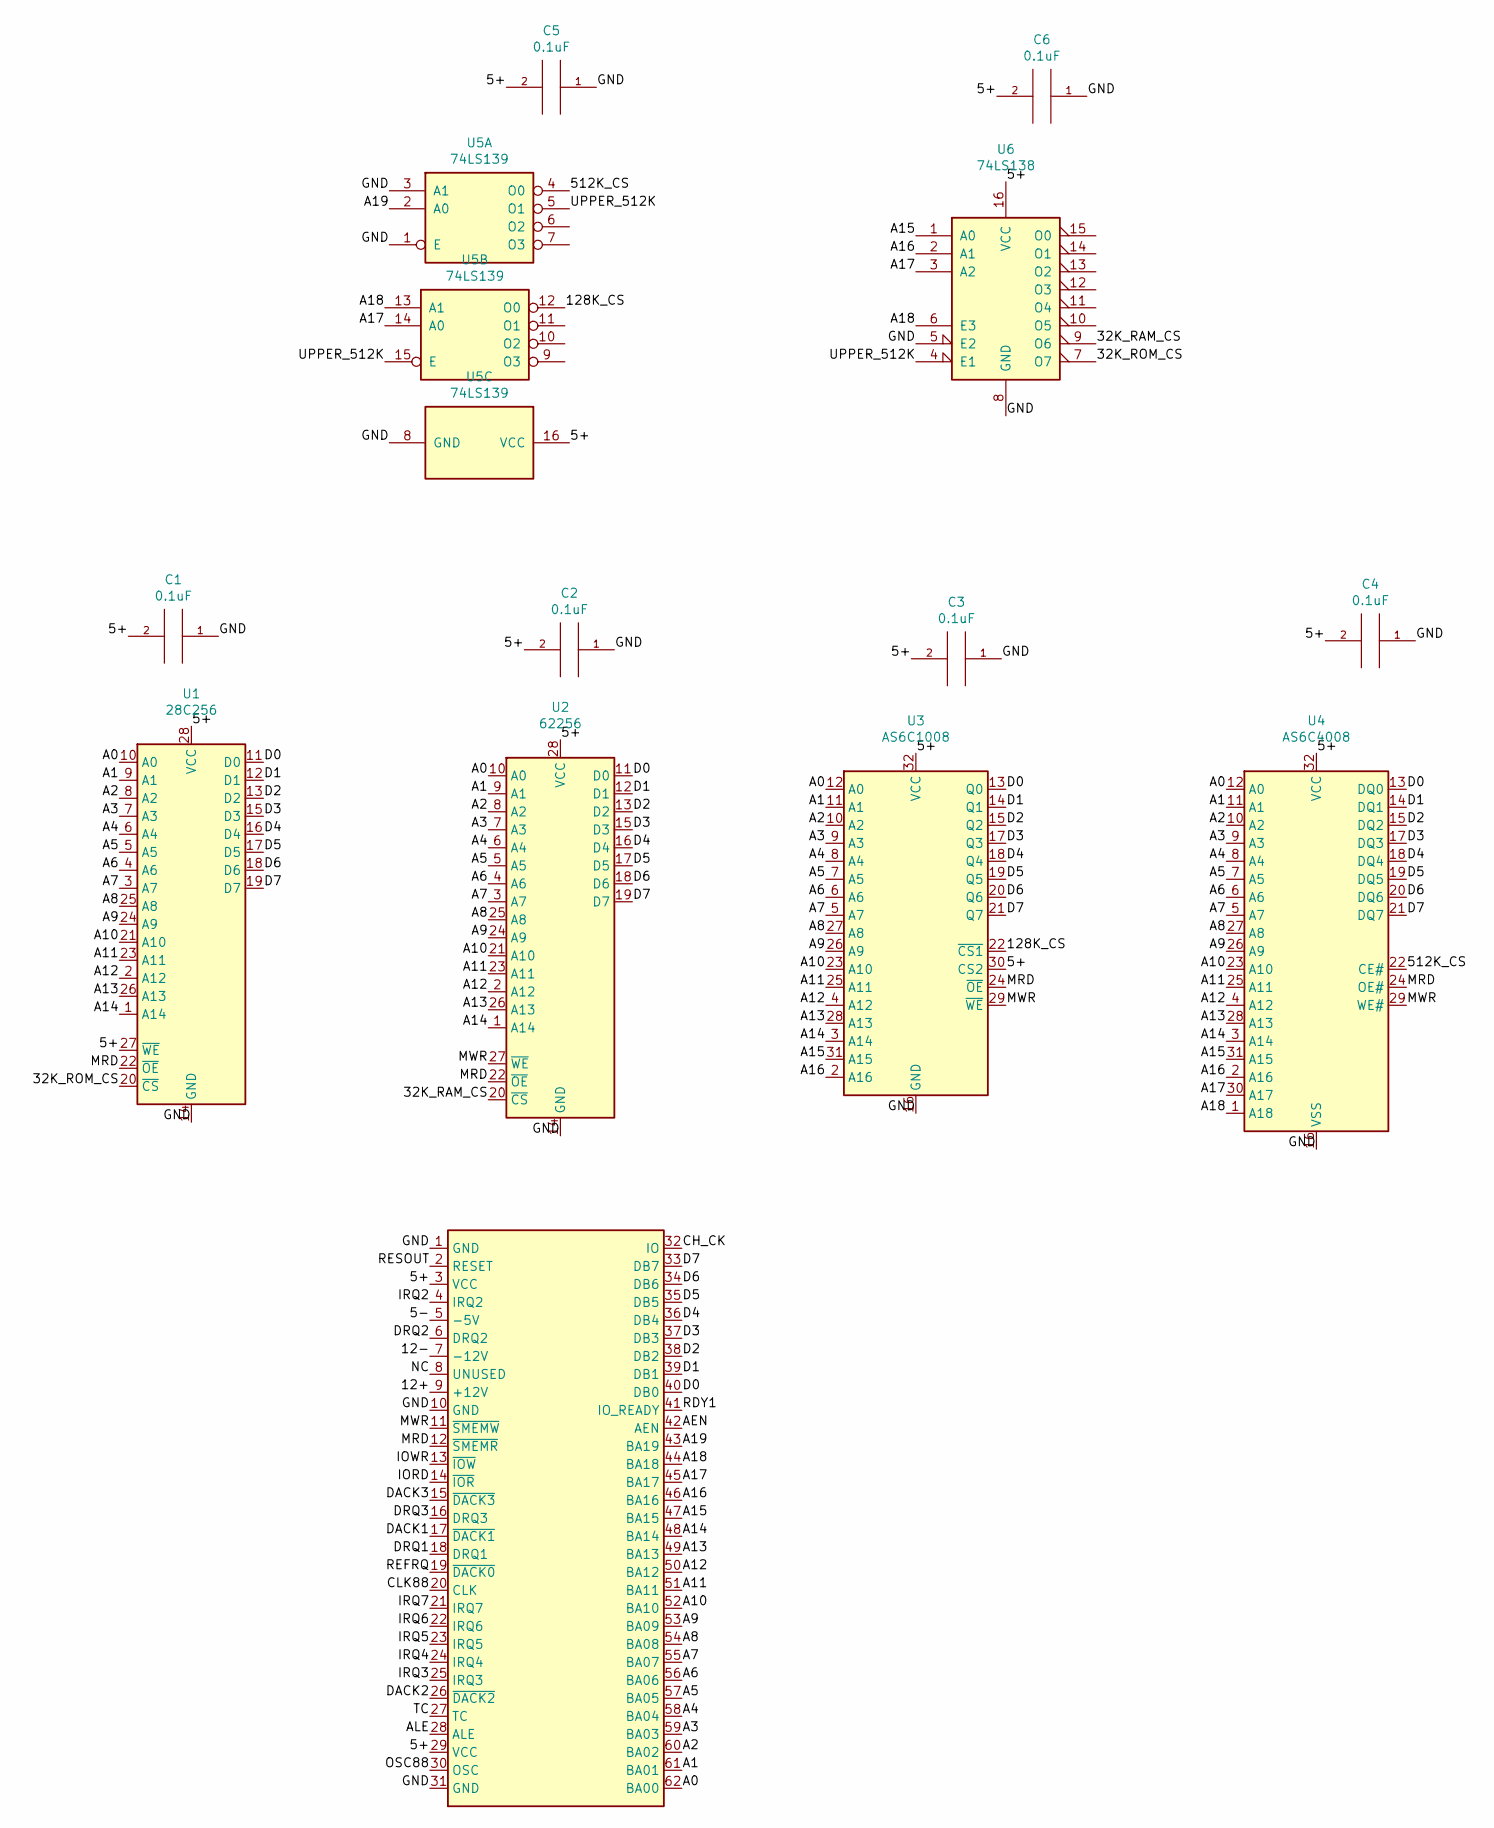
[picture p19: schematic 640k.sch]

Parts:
C1, C2, C3, C4, C5, C6: 0.1uF; C_Disc_D4.3mm_W1.9mm_P5.00mm
J9: Bus_ISA_8bit; BUS_8_BIT
U1: 28C256; DIP-28_W15.24mm
U2: 62256; DIP-28_W15.24mm
U3: AS6C1008; DIP-32_W15.24mm
U4: AS6C4008; DIP-32_W15.24mm
U5: 74LS139; DIP-16_W7.62mm
U6: 74LS138; DIP-16_W7.62mm

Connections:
/5+: C1.2, C2.2, C3.2, C4.2, C5.2, C6.2, J9.3 (VCC), J9.29 (VCC), U1.27 (~WE), U1.28 (VCC), U2.28 (VCC), U3.30 (CS2), U3.32 (VCC), U4.32 (VCC), U5.16 (VCC), U6.16 (VCC)
/5-: J9.5 (-5V)
/12+: J9.9 (+12V)
/12-: J9.7 (-12V)
/32K_RAM_CS: U2.20 (~CS), U6.9 (O6)
/32K_ROM_CS: U1.20 (~CS), U6.7 (O7)
/128K_CS: U3.22 (~CS1), U5.12 (O0)
/512K_CS: U4.22 (CE#), U5.4 (O0)
/A0: J9.62 (BA00), U1.10 (A0), U2.10 (A0), U3.12 (A0), U4.12 (A0)
/A1: J9.61 (BA01), U1.9 (A1), U2.9 (A1), U3.11 (A1), U4.11 (A1)
/A2: J9.60 (BA02), U1.8 (A2), U2.8 (A2), U3.10 (A2), U4.10 (A2)
/A3: J9.59 (BA03), U1.7 (A3), U2.7 (A3), U3.9 (A3), U4.9 (A3)
/A4: J9.58 (BA04), U1.6 (A4), U2.6 (A4), U3.8 (A4), U4.8 (A4)
/A5: J9.57 (BA05), U1.5 (A5), U2.5 (A5), U3.7 (A5), U4.7 (A5)
/A6: J9.56 (BA06), U1.4 (A6), U2.4 (A6), U3.6 (A6), U4.6 (A6)
/A7: J9.55 (BA07), U1.3 (A7), U2.3 (A7), U3.5 (A7), U4.5 (A7)
/A8: J9.54 (BA08), U1.25 (A8), U2.25 (A8), U3.27 (A8), U4.27 (A8)
/A9: J9.53 (BA09), U1.24 (A9), U2.24 (A9), U3.26 (A9), U4.26 (A9)
/A10: J9.52 (BA10), U1.21 (A10), U2.21 (A10), U3.23 (A10), U4.23 (A10)
/A11: J9.51 (BA11), U1.23 (A11), U2.23 (A11), U3.25 (A11), U4.25 (A11)
/A12: J9.50 (BA12), U1.2 (A12), U2.2 (A12), U3.4 (A12), U4.4 (A12)
/A13: J9.49 (BA13), U1.26 (A13), U2.26 (A13), U3.28 (A13), U4.28 (A13)
/A14: J9.48 (BA14), U1.1 (A14), U2.1 (A14), U3.3 (A14), U4.3 (A14)
/A15: J9.47 (BA15), U3.31 (A15), U4.31 (A15), U6.1 (A0)
/A16: J9.46 (BA16), U3.2 (A16), U4.2 (A16), U6.2 (A1)
/A17: J9.45 (BA17), U4.30 (A17), U5.14 (A0), U6.3 (A2)
/A18: J9.44 (BA18), U4.1 (A18), U5.13 (A1), U6.6 (E3)
/A19: J9.43 (BA19), U5.2 (A0)
/AEN: J9.42 (AEN)
/ALE: J9.28 (ALE)
/CH_CK: J9.32 (IO)
/CLK88: J9.20 (CLK)
/D0: J9.40 (DB0), U1.11 (D0), U2.11 (D0), U3.13 (Q0), U4.13 (DQ0)
/D1: J9.39 (DB1), U1.12 (D1), U2.12 (D1), U3.14 (Q1), U4.14 (DQ1)
/D2: J9.38 (DB2), U1.13 (D2), U2.13 (D2), U3.15 (Q2), U4.15 (DQ2)
/D3: J9.37 (DB3), U1.15 (D3), U2.15 (D3), U3.17 (Q3), U4.17 (DQ3)
/D4: J9.36 (DB4), U1.16 (D4), U2.16 (D4), U3.18 (Q4), U4.18 (DQ4)
/D5: J9.35 (DB5), U1.17 (D5), U2.17 (D5), U3.19 (Q5), U4.19 (DQ5)
/D6: J9.34 (DB6), U1.18 (D6), U2.18 (D6), U3.20 (Q6), U4.20 (DQ6)
/D7: J9.33 (DB7), U1.19 (D7), U2.19 (D7), U3.21 (Q7), U4.21 (DQ7)
/DACK1: J9.17 (~DACK1)
/DACK2: J9.26 (~DACK2)
/DACK3: J9.15 (~DACK3)
/DRQ1: J9.18 (DRQ1)
/DRQ2: J9.6 (DRQ2)
/DRQ3: J9.16 (DRQ3)
/GND: C1.1, C2.1, C3.1, C4.1, C5.1, C6.1, J9.1 (GND), J9.10 (GND), J9.31 (GND), U1.14 (GND), U2.14 (GND), U3.16 (GND), U4.16 (VSS), U5.1 (E), U5.3 (A1), U5.8 (GND), U6.5 (E2), U6.8 (GND); also elsewhere on the board
/IORD: J9.14 (~IOR)
/IOWR: J9.13 (~IOW)
/IRQ2: J9.4 (IRQ2)
/IRQ3: J9.25 (IRQ3)
/IRQ4: J9.24 (IRQ4)
/IRQ5: J9.23 (IRQ5)
/IRQ6: J9.22 (IRQ6)
/IRQ7: J9.21 (IRQ7)
/MRD: J9.12 (~SMEMR), U1.22 (~OE), U2.22 (~OE), U3.24 (~OE), U4.24 (OE#)
/MWR: J9.11 (~SMEMW), U2.27 (~WE), U3.29 (~WE), U4.29 (WE#)
/NC: J9.8 (UNUSED)
/OSC88: J9.30 (OSC)
/RDY1: J9.41 (IO_READY)
/REFRQ: J9.19 (~DACK0)
/RESOUT: J9.2 (RESET)
/TC: J9.27 (TC)
/UPPER_512K: U5.5 (O1), U5.15 (E), U6.4 (E1)

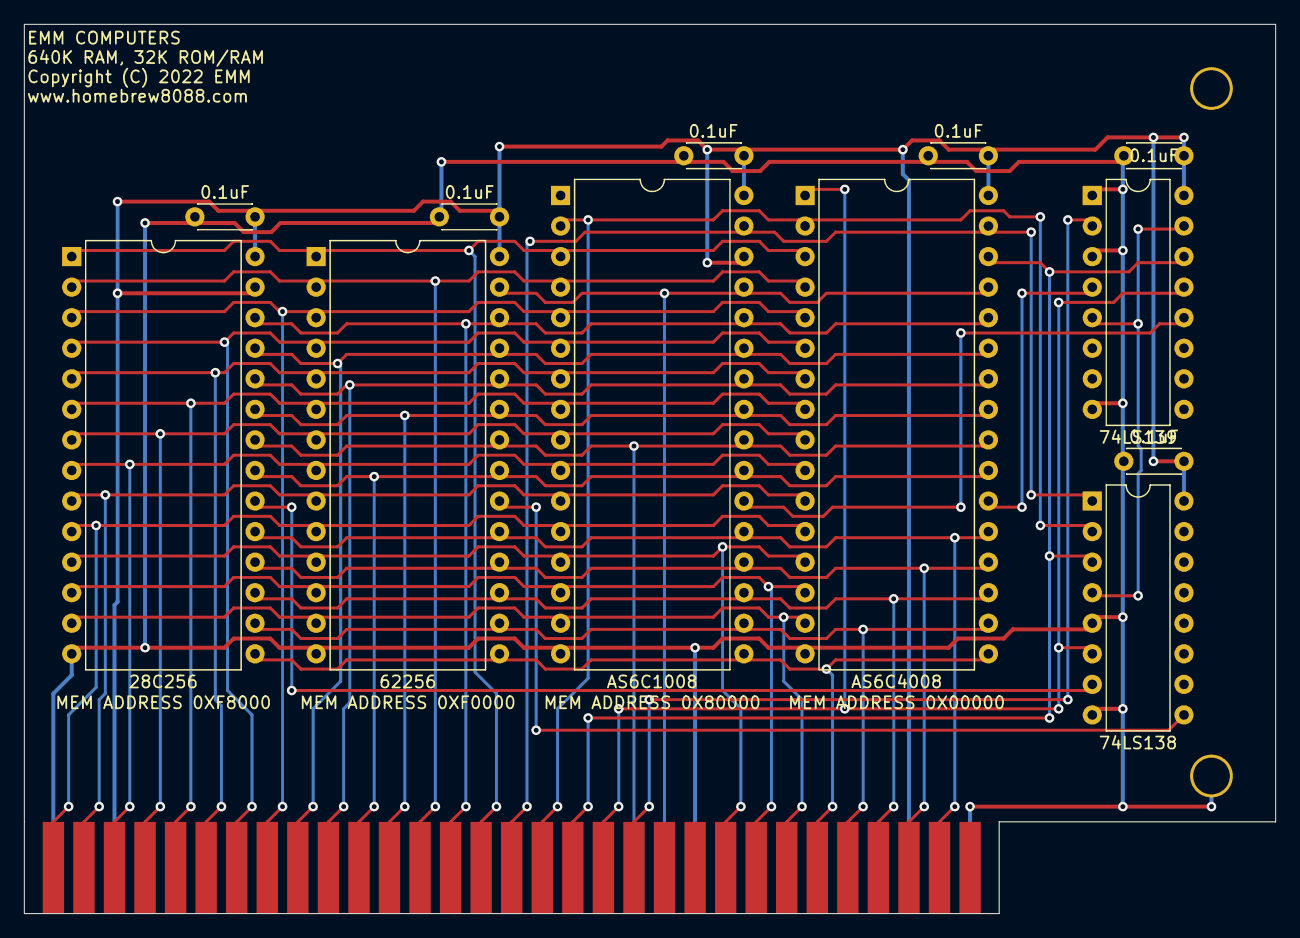
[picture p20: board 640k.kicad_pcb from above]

Board: 2 copper layers, 104.0 x 73.9 mm, 15 parts (0 on the bottom side), 37 nets.

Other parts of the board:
R: L; Large_Via
R#2: L; Large_Via

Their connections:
/GND: R.1; also elsewhere on the board

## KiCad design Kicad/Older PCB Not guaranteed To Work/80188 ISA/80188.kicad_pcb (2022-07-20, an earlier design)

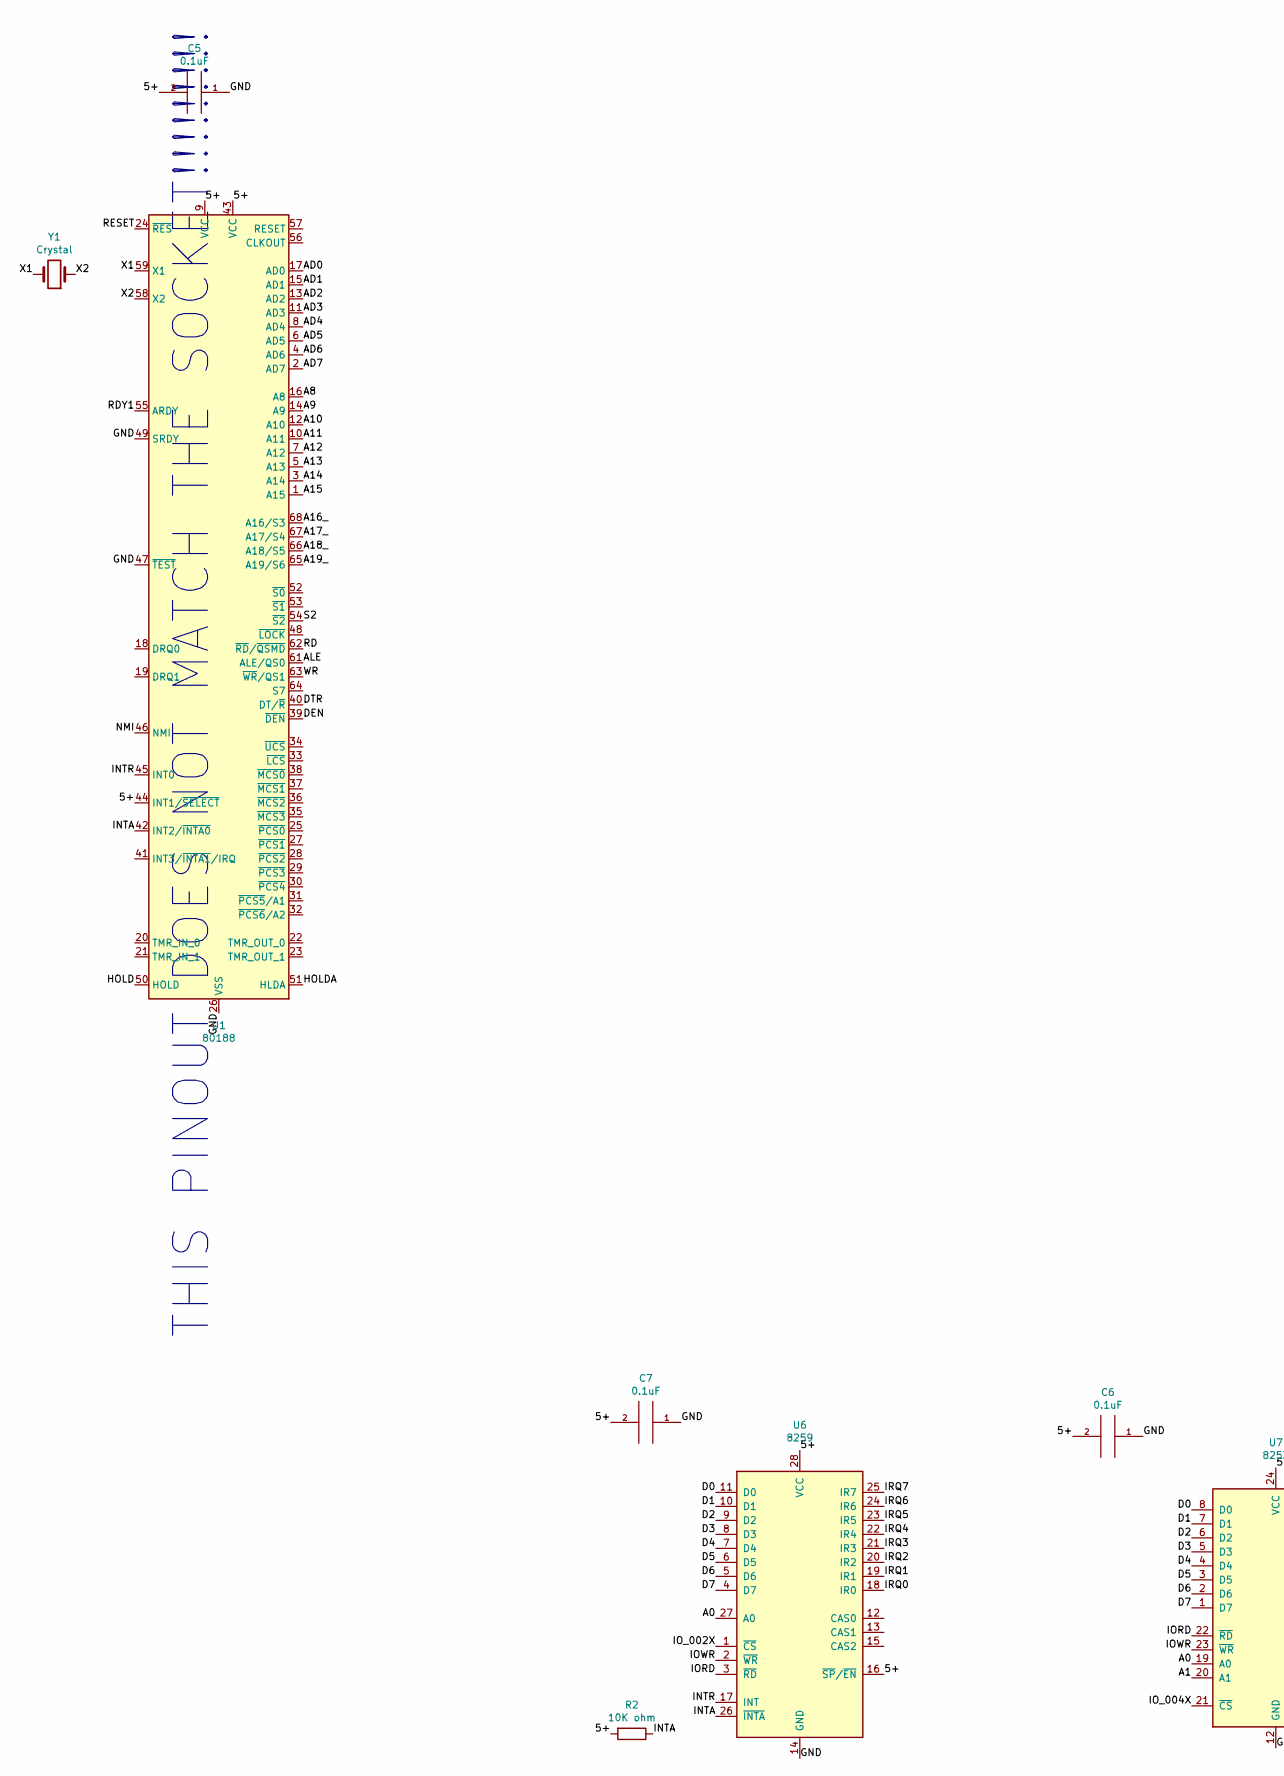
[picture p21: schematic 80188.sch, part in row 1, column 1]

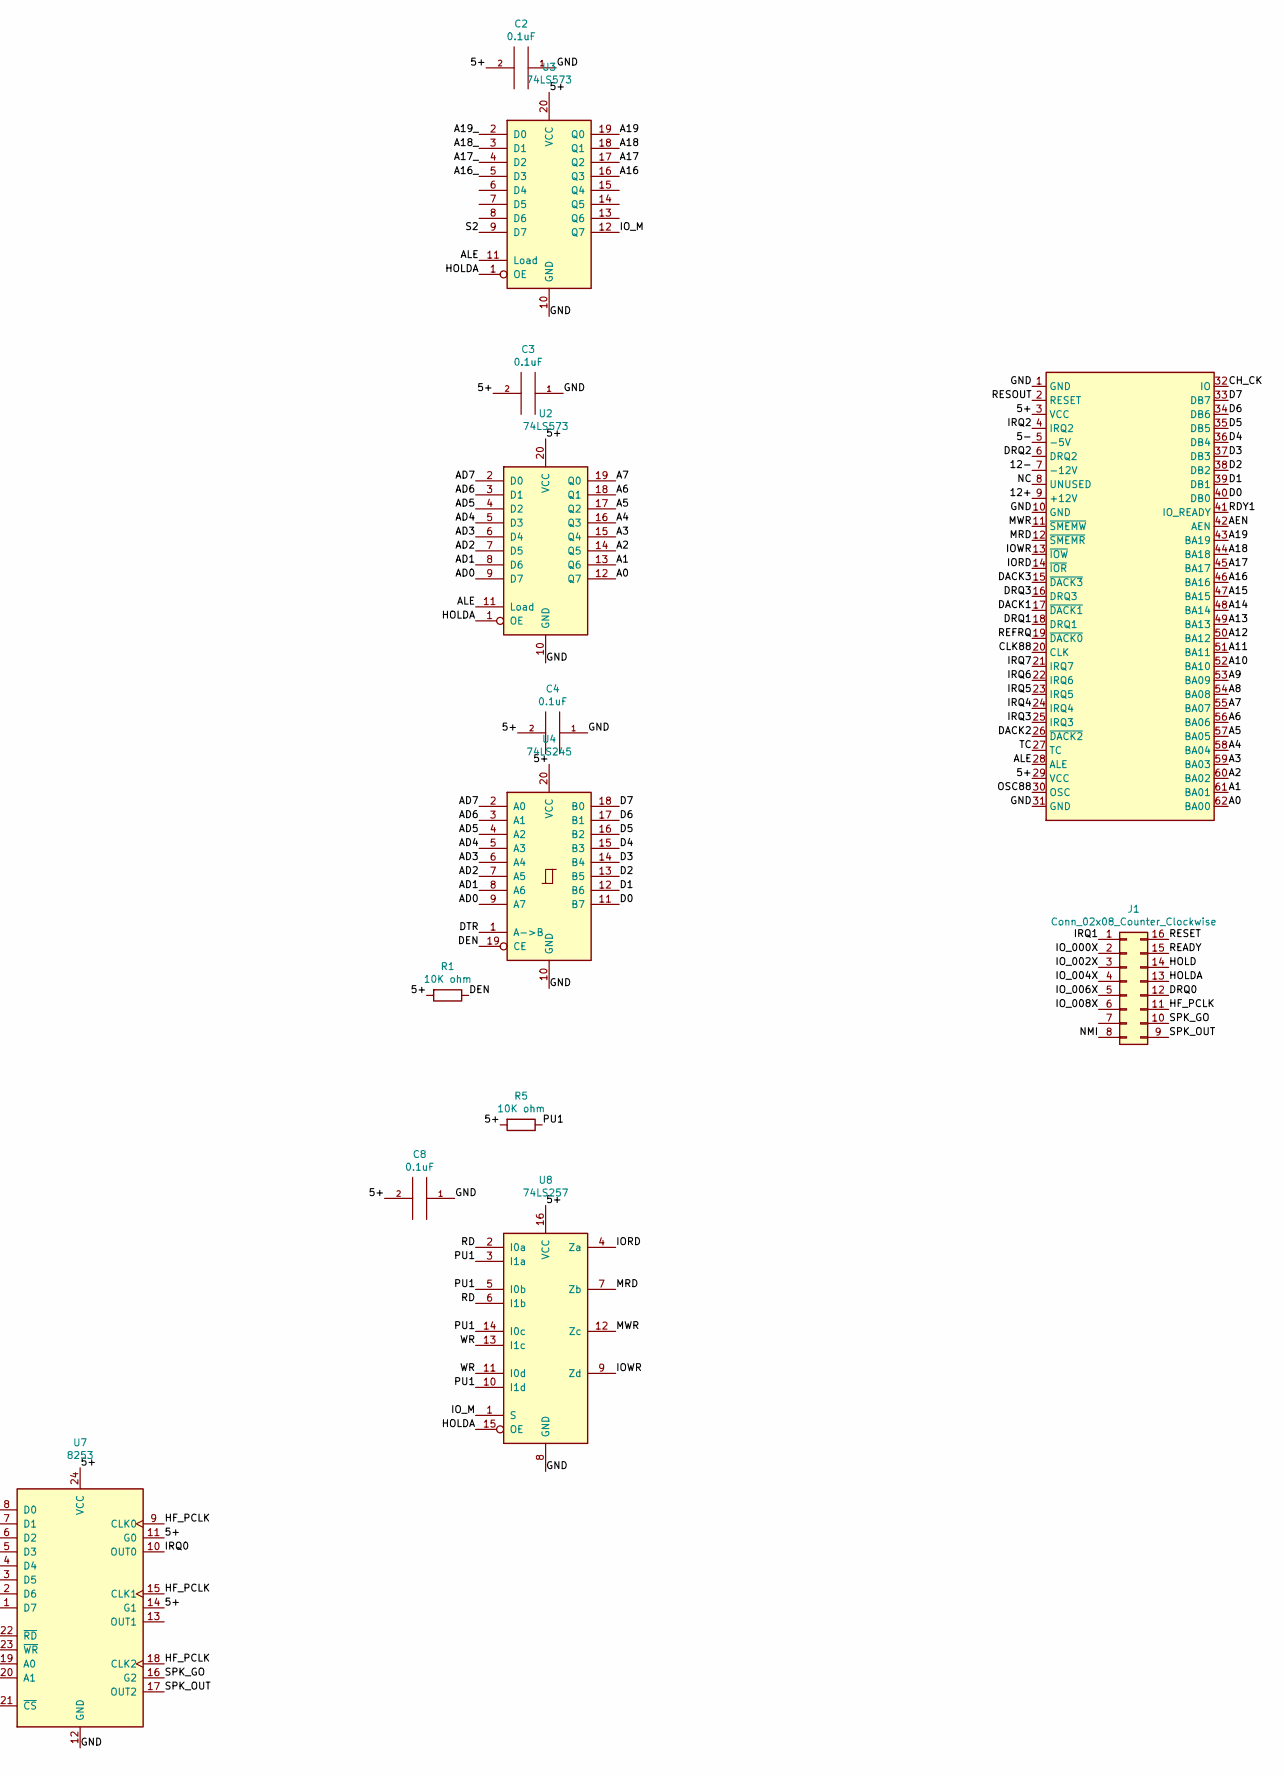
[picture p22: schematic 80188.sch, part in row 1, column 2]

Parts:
C2, C3, C4, C5, C6, C7, C8: 0.1uF; C_Disc_D4.3mm_W1.9mm_P5.00mm
J1: Conn_02x08_Counter_Clockwise; 16_EDGE_CARD_BUS
J9: Bus_ISA_8bit; BUS_8_BIT
R1, R2, R5: 10K ohm; R_Axial_DIN0207_L6.3mm_D2.5mm_P10.16mm_Horizontal
U1: 80188; PLCC-68_THT-Socket
U2, U3: 74LS573; DIP-20_W7.62mm
U4: 74LS245; DIP-20_W7.62mm
U6: 8259; DIP-28_W15.24mm
U7: 8253; DIP-24_W15.24mm
U8: 74LS257; DIP-16_W7.62mm
Y1: Crystal; Crystal_HC18-U_Vertical

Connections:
/5+: C2.2, C3.2, C4.2, C5.2, C6.2, C7.2, C8.2, J9.3 (VCC), J9.29 (VCC), R1.2, R2.2, R5.2, U1.9 (VCC), U1.43 (VCC), U1.44 (INT1/~SELECT~), U2.20 (VCC), U3.20 (VCC), U4.20 (VCC), U6.16 (~SP~/~EN~), U6.28 (VCC), U7.11 (G0), U7.14 (G1), U7.24 (VCC), U8.16 (VCC); also elsewhere on the board
/5-: J9.5 (-5V)
/12+: J9.9 (+12V)
/12-: J9.7 (-12V)
/A0: J9.62 (BA00), U2.12 (Q7), U6.27 (A0), U7.19 (A0)
/A1: J9.61 (BA01), U2.13 (Q6), U7.20 (A1)
/A2: J9.60 (BA02), U2.14 (Q5)
/A3: J9.59 (BA03), U2.15 (Q4)
/A4: J9.58 (BA04), U2.16 (Q3)
/A5: J9.57 (BA05), U2.17 (Q2)
/A6: J9.56 (BA06), U2.18 (Q1)
/A7: J9.55 (BA07), U2.19 (Q0)
/A8: J9.54 (BA08), U1.16 (A8); also elsewhere on the board
/A9: J9.53 (BA09), U1.14 (A9); also elsewhere on the board
/A10: J9.52 (BA10), U1.12 (A10); also elsewhere on the board
/A11: J9.51 (BA11), U1.10 (A11); also elsewhere on the board
/A12: J9.50 (BA12), U1.7 (A12); also elsewhere on the board
/A13: J9.49 (BA13), U1.5 (A13); also elsewhere on the board
/A14: J9.48 (BA14), U1.3 (A14); also elsewhere on the board
/A15: J9.47 (BA15), U1.1 (A15); also elsewhere on the board
/A16: J9.46 (BA16), U3.16 (Q3)
/A16_: U1.68 (A16/S3), U3.5 (D3); also elsewhere on the board
/A17: J9.45 (BA17), U3.17 (Q2)
/A17_: U1.67 (A17/S4), U3.4 (D2); also elsewhere on the board
/A18: J9.44 (BA18), U3.18 (Q1)
/A18_: U1.66 (A18/S5), U3.3 (D1); also elsewhere on the board
/A19: J9.43 (BA19), U3.19 (Q0)
/A19_: U1.65 (A19/S6), U3.2 (D0); also elsewhere on the board
/AD0: U1.17 (AD0), U2.9 (D7), U4.9 (A7); also elsewhere on the board
/AD1: U1.15 (AD1), U2.8 (D6), U4.8 (A6); also elsewhere on the board
/AD2: U1.13 (AD2), U2.7 (D5), U4.7 (A5); also elsewhere on the board
/AD3: U1.11 (AD3), U2.6 (D4), U4.6 (A4); also elsewhere on the board
/AD4: U1.8 (AD4), U2.5 (D3), U4.5 (A3); also elsewhere on the board
/AD5: U1.6 (AD5), U2.4 (D2), U4.4 (A2); also elsewhere on the board
/AD6: U1.4 (AD6), U2.3 (D1), U4.3 (A1); also elsewhere on the board
/AD7: U1.2 (AD7), U2.2 (D0), U4.2 (A0); also elsewhere on the board
/AEN: J9.42 (AEN)
/ALE: J9.28 (ALE), U1.61 (ALE/QS0), U2.11 (Load), U3.11 (Load); also elsewhere on the board
/CH_CK: J9.32 (IO)
/CLK88: J9.20 (CLK)
/D0: J9.40 (DB0), U4.11 (B7), U6.11 (D0), U7.8 (D0)
/D1: J9.39 (DB1), U4.12 (B6), U6.10 (D1), U7.7 (D1)
/D2: J9.38 (DB2), U4.13 (B5), U6.9 (D2), U7.6 (D2)
/D3: J9.37 (DB3), U4.14 (B4), U6.8 (D3), U7.5 (D3)
/D4: J9.36 (DB4), U4.15 (B3), U6.7 (D4), U7.4 (D4)
/D5: J9.35 (DB5), U4.16 (B2), U6.6 (D5), U7.3 (D5)
/D6: J9.34 (DB6), U4.17 (B1), U6.5 (D6), U7.2 (D6)
/D7: J9.33 (DB7), U4.18 (B0), U6.4 (D7), U7.1 (D7)
/DACK1: J9.17 (~DACK1)
/DACK2: J9.26 (~DACK2)
/DACK3: J9.15 (~DACK3)
/DEN: R1.1, U1.39 (~DEN~), U4.19 (CE); also elsewhere on the board
/DRQ0: J1.12
/DRQ1: J9.18 (DRQ1)
/DRQ2: J9.6 (DRQ2)
/DRQ3: J9.16 (DRQ3)
/DTR: U1.40 (DT/~R~), U4.1 (A->B); also elsewhere on the board
/GND: C2.1, C3.1, C4.1, C5.1, C6.1, C7.1, C8.1, J9.1 (GND), J9.10 (GND), J9.31 (GND), U1.26 (VSS), U1.47 (~TEST~), U1.49 (SRDY), U1.60 (VSS), U2.10 (GND), U3.10 (GND), U4.10 (GND), U6.14 (GND), U7.12 (GND), U8.8 (GND); also elsewhere on the board
/HF_PCLK: J1.11, U7.9 (CLK0), U7.15 (CLK1), U7.18 (CLK2)
/HOLD: J1.14, U1.50 (HOLD); also elsewhere on the board
/HOLDA: J1.13, U1.51 (HLDA), U2.1 (OE), U3.1 (OE), U8.15 (OE); also elsewhere on the board
/INTA: R2.1, U1.42 (INT2/~INTA0~), U6.26 (~INTA~); also elsewhere on the board
/INTR: U1.45 (INT0), U6.17 (INT); also elsewhere on the board
/IORD: J9.14 (~IOR), U6.3 (~RD~), U7.22 (~RD~), U8.4 (Za)
/IOWR: J9.13 (~IOW), U6.2 (~WR~), U7.23 (~WR~), U8.9 (Zd)
/IO_000X: J1.2
/IO_002X: J1.3, U6.1 (~CS~)
/IO_004X: J1.4, U7.21 (~CS~)
/IO_006X: J1.5
/IO_008X: J1.6
/IO_M: U3.12 (Q7), U8.1 (S)
/IRQ0: U6.18 (IR0), U7.10 (OUT0)
/IRQ1: J1.1, U6.19 (IR1)
/IRQ2: J9.4 (IRQ2), U6.20 (IR2)
/IRQ3: J9.25 (IRQ3), U6.21 (IR3)
/IRQ4: J9.24 (IRQ4), U6.22 (IR4)
/IRQ5: J9.23 (IRQ5), U6.23 (IR5)
/IRQ6: J9.22 (IRQ6), U6.24 (IR6)
/IRQ7: J9.21 (IRQ7), U6.25 (IR7)
/MRD: J9.12 (~SMEMR), U8.7 (Zb)
/MWR: J9.11 (~SMEMW), U8.12 (Zc)
/NC: J9.8 (UNUSED)
/NMI: J1.8, U1.46 (NMI); also elsewhere on the board
/OSC88: J9.30 (OSC)
/PU1: R5.1, U8.3 (I1a), U8.5 (I0b), U8.10 (I1d), U8.14 (I0c)
/RD: U1.62 (~RD~/~QSMD~), U8.2 (I0a), U8.6 (I1b); also elsewhere on the board
/RDY1: J9.41 (IO_READY), U1.55 (ARDY); also elsewhere on the board
/READY: J1.15
/REFRQ: J9.19 (~DACK0)
/RESET: J1.16, U1.24 (~RES~); also elsewhere on the board
/RESOUT: J9.2 (RESET)
/S2: U1.54 (~S2~), U3.9 (D7); also elsewhere on the board
/SPK_GO: J1.10, U7.16 (G2)
/SPK_OUT: J1.9, U7.17 (OUT2)
/TC: J9.27 (TC)
/WR: U1.63 (~WR~/QS1), U8.11 (I0d), U8.13 (I1c); also elsewhere on the board
/X1: U1.59 (X1), Y1.2; also elsewhere on the board
/X2: U1.58 (X2), Y1.1; also elsewhere on the board

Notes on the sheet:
THIS PINOUT DOES NOT MATCH THE SOCKET!!!!!!!!!


Board: 2 copper layers, 143.0 x 73.9 mm, 22 parts (0 on the bottom side), 76 nets.

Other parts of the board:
80188: PLCC-68_THT-Socket
R: L; Large_Via
R#2: L; Large_Via

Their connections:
/5+: 80188.9, 80188.43, 80188.44; also elsewhere on the board
/A8: 80188.16; also elsewhere on the board
/A9: 80188.14; also elsewhere on the board
/A10: 80188.12; also elsewhere on the board
/A11: 80188.10; also elsewhere on the board
/A12: 80188.7; also elsewhere on the board
/A13: 80188.5; also elsewhere on the board
/A14: 80188.3; also elsewhere on the board
/A15: 80188.1; also elsewhere on the board
/A16_: 80188.68; also elsewhere on the board
/A17_: 80188.67; also elsewhere on the board
/A18_: 80188.66; also elsewhere on the board
/A19_: 80188.65; also elsewhere on the board
/AD0: 80188.17; also elsewhere on the board
/AD1: 80188.15; also elsewhere on the board
/AD2: 80188.13; also elsewhere on the board
/AD3: 80188.11; also elsewhere on the board
/AD4: 80188.8; also elsewhere on the board
/AD5: 80188.6; also elsewhere on the board
/AD6: 80188.4; also elsewhere on the board
/AD7: 80188.2; also elsewhere on the board
/ALE: 80188.61; also elsewhere on the board
/DEN: 80188.39; also elsewhere on the board
/DTR: 80188.40; also elsewhere on the board
/GND: 80188.26, 80188.47, 80188.49, 80188.60, R.1, R#2.1; also elsewhere on the board
/HOLD: 80188.50; also elsewhere on the board
/HOLDA: 80188.51; also elsewhere on the board
/INTA: 80188.42; also elsewhere on the board
/INTR: 80188.45; also elsewhere on the board
/NMI: 80188.46; also elsewhere on the board
/RD: 80188.62; also elsewhere on the board
/RDY1: 80188.55; also elsewhere on the board
/RESET: 80188.24; also elsewhere on the board
/S2: 80188.54; also elsewhere on the board
/WR: 80188.63; also elsewhere on the board
/X1: 80188.59; also elsewhere on the board
/X2: 80188.58; also elsewhere on the board

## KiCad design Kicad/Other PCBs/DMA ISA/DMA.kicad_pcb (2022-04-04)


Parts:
C1, C2, C3, C4, C5: 0.1uF; C_Disc_D4.3mm_W1.9mm_P5.00mm
J1: Conn_02x08_Counter_Clockwise; 16_EDGE_CARD_BUS
J9: Bus_ISA_8bit; BUS_8_BIT
R1, R2: 10k ohm; R_Axial_DIN0207_L6.3mm_D2.5mm_P10.16mm_Horizontal
R3: 27 ohm; R_Axial_DIN0207_L6.3mm_D2.5mm_P10.16mm_Horizontal
U1: 8237; DIP-40_W15.24mm
U2: 74LS139; DIP-16_W7.62mm
U3: 74LS04; DIP-14_W7.62mm
U4: 74LS670; DIP-16_W7.62mm
U5: 74LS573; DIP-20_W7.62mm

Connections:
/5+: C1.2, C2.2, C3.2, C4.2, C5.2, J9.3 (VCC), J9.29 (VCC), R2.2, U1.5 (PIN5), U1.31 (Vcc), U2.16 (VCC), U3.14 (VCC), U4.16 (VCC), U5.20 (VCC)
/5-: J9.5 (-5V)
/12+: J9.9 (+12V)
/12-: J9.7 (-12V)
/760_EN: U2.4 (O0), U4.12 (~Ew)
/A0: J9.62 (BA00), U1.32 (A0), U4.14 (Wa)
/A1: J9.61 (BA01), U1.33 (A1), U4.13 (Wb)
/A2: J9.60 (BA02), U1.34 (A2)
/A3: J9.59 (BA03), U1.35 (A3)
/A4: J9.58 (BA04), U1.37 (A4)
/A5: J9.57 (BA05), U1.38 (A5)
/A6: J9.56 (BA06), U1.39 (A6)
/A7: J9.55 (BA07), U1.40 (A7)
/A8: J9.54 (BA08), U5.12 (Q7)
/A9: J9.53 (BA09), U5.13 (Q6)
/A10: J9.52 (BA10), U5.14 (Q5)
/A11: J9.51 (BA11), U5.15 (Q4)
/A12: J9.50 (BA12), U5.16 (Q3)
/A13: J9.49 (BA13), U5.17 (Q2)
/A14: J9.48 (BA14), U5.18 (Q1)
/A15: J9.47 (BA15), U5.19 (Q0)
/A16: J9.46 (BA16), U4.10 (Q1)
/A17: J9.45 (BA17), U4.9 (Q2)
/A18: J9.44 (BA18), U4.7 (Q3)
/A19: J9.43 (BA19), U4.6 (Q4)
/ADSTB: U1.8 (ADSTB), U5.11 (Load)
/AEN: J9.42 (AEN), U1.9 (AEN), U3.3
/AEN_OE: U3.4, U4.11 (~Er), U5.1 (OE)
/ALE: J9.28 (ALE)
/CH_CK: J9.32 (IO)
/CLK88: J9.20 (CLK), R3.2
/CLK88_1: R3.1, U1.12 (CLK)
/D0: J9.40 (DB0), U1.30 (DB0), U4.15 (D1), U5.9 (D7)
/D1: J9.39 (DB1), U1.29 (DB1), U4.1 (D2), U5.8 (D6)
/D2: J9.38 (DB2), U1.28 (DB2), U4.2 (D3), U5.7 (D5)
/D3: J9.37 (DB3), U1.27 (DB3), U4.3 (D4), U5.6 (D4)
/D4: J9.36 (DB4), U1.26 (DB4), U5.5 (D3)
/D5: J9.35 (DB5), U1.23 (DB5), U5.4 (D2)
/D6: J9.34 (DB6), U1.22 (DB6), U5.3 (D1)
/D7: J9.33 (DB7), U1.21 (DB7), U5.2 (D0)
/DACK0: U1.25 (DACK0)
/DACK1: J9.17 (~DACK1), U1.24 (DACK1)
/DACK2: J9.26 (~DACK2), U1.14 (DACK2), U4.4 (Rb)
/DACK3: J9.15 (~DACK3), U1.15 (DACK3), U4.5 (Ra)
/DRQ0: J1.12
/DRQ0_: R1.1, U1.19 (DREQ0)
/DRQ1: J9.18 (DRQ1), U1.18 (DREQ1)
/DRQ2: J9.6 (DRQ2), U1.17 (DREQ2)
/DRQ3: J9.16 (DRQ3), U1.16 (DREQ3)
/EOP: R2.1, U1.36 (~EOP~), U3.5
/GND: C1.1, C2.1, C3.1, C4.1, C5.1, J9.1 (GND), J9.31 (GND), R1.2, U1.20 (Vss), U2.1 (E), U2.8 (GND), U3.7 (GND), U4.8 (GND), U5.10 (GND); also elsewhere on the board
/GND_NC: J9.10 (GND)
/HF_PCLK: J1.11
/HOLD: J1.14, U1.10 (HRQ)
/HOLDA: J1.13, U1.7 (HLDA)
/IORD: J9.14 (~IOR), U1.1 (~IOR~)
/IOWR: J9.13 (~IOW), U1.2 (~IOW~), U2.3 (A1)
/IO_000X: J1.2, U1.11 (~CS~)
/IO_002X: J1.3
/IO_004X: J1.4
/IO_006X: J1.5
/IO_008X: J1.6, U2.2 (A0)
/IRQ1: J1.1
/IRQ2: J9.4 (IRQ2)
/IRQ3: J9.25 (IRQ3)
/IRQ4: J9.24 (IRQ4)
/IRQ5: J9.23 (IRQ5)
/IRQ6: J9.22 (IRQ6)
/IRQ7: J9.21 (IRQ7)
/MRD: J9.12 (~SMEMR), U1.3 (~MEMR~)
/MWR: J9.11 (~SMEMW), U1.4 (~MEMW~)
/NC: J9.8 (UNUSED)
/NMI: J1.8
/OSC88: J9.30 (OSC)
/RDY1: J9.41 (IO_READY)
/READY: J1.15, U1.6 (READY)
/REFRQ: J9.19 (~DACK0)
/RESET: J1.16
/RESOUT: J9.2 (RESET), U1.13 (RESET)
/SPK_GO: J1.10
/SPK_OUT: J1.9
/TC: J9.27 (TC), U3.6


Board: 2 copper layers, 132.0 x 73.9 mm, 17 parts (0 on the bottom side), 55 nets.

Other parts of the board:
R: L; Large_Via
R#2: L; Large_Via

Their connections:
/GND: R.1, R#2.1; also elsewhere on the board

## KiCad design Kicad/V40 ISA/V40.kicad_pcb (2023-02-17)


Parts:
C1, C2, C3, C4: 0.1uF; C_Disc_D4.3mm_W1.9mm_P5.00mm
J1: Conn_02x08_Counter_Clockwise; 16_EDGE_CARD_BUS
J9: Bus_ISA_8bit; BUS_8_BIT
R1, R2: 10K ohm; R_Axial_DIN0207_L6.3mm_D2.5mm_P10.16mm_Horizontal
U1: 70208; PLCC-68_THT-Socket
U2, U3: 74LS573; DIP-20_W7.62mm
U4: 74LS245; DIP-20_W7.62mm
Y1: Crystal; Crystal_HC18-U_Vertical

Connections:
/5+: C1.2, C2.2, C3.2, C4.2, J9.3 (VCC), J9.29 (VCC), R1.2, U1.1 (VDD), U2.20 (VCC), U3.20 (VCC), U4.20 (VCC)
/5-: J9.5 (-5V)
/12+: J9.9 (+12V)
/12-: J9.7 (-12V)
/A0: J9.62 (BA00), U2.12 (Q7)
/A1: J9.61 (BA01), U2.13 (Q6)
/A2: J9.60 (BA02), U2.14 (Q5)
/A3: J9.59 (BA03), U2.15 (Q4)
/A4: J9.58 (BA04), U2.16 (Q3)
/A5: J9.57 (BA05), U2.17 (Q2)
/A6: J9.56 (BA06), U2.18 (Q1)
/A7: J9.55 (BA07), U2.19 (Q0)
/A8: J9.54 (BA08), U1.17 (A8)
/A9: J9.53 (BA09), U1.16 (A9)
/A10: J9.52 (BA10), U1.15 (A10)
/A11: J9.51 (BA11), U1.14 (A11)
/A12: J9.50 (BA12), U1.13 (A12)
/A13: J9.49 (BA13), U1.12 (A13)
/A14: J9.48 (BA14), U1.11 (A14)
/A15: J9.47 (BA15), U1.10 (A15)
/A16: J9.46 (BA16), U3.16 (Q3)
/A16_: U1.9 (A16), U3.5 (D3)
/A17: J9.45 (BA17), U3.17 (Q2)
/A17_: U1.8 (A17), U3.4 (D2)
/A18: J9.44 (BA18), U3.18 (Q1)
/A18_: U1.7 (A18), U3.3 (D1)
/A19: J9.43 (BA19), U3.19 (Q0)
/A19_: U1.6 (A19), U3.2 (D0)
/AD0: U1.26 (AD0), U2.9 (D7), U4.9 (A7)
/AD1: U1.25 (AD1), U2.8 (D6), U4.8 (A6)
/AD2: U1.24 (AD2), U2.7 (D5), U4.7 (A5)
/AD3: U1.23 (AD3), U2.6 (D4), U4.6 (A4)
/AD4: U1.22 (AD4), U2.5 (D3), U4.5 (A3)
/AD5: U1.21 (AD5), U2.4 (D2), U4.4 (A2)
/AD6: U1.20 (AD6), U2.3 (D1), U4.3 (A1)
/AD7: U1.19 (AD7), U2.2 (D0), U4.2 (A0)
/AEN: J9.42 (AEN)
/ALE: J9.28 (ALE), U1.50 (ASTB), U2.11 (Load), U3.11 (Load)
/CH_CK: J9.32 (IO)
/CLK88: J9.20 (CLK)
/D0: J9.40 (DB0), U4.11 (B7)
/D1: J9.39 (DB1), U4.12 (B6)
/D2: J9.38 (DB2), U4.13 (B5)
/D3: J9.37 (DB3), U4.14 (B4)
/D4: J9.36 (DB4), U4.15 (B3)
/D5: J9.35 (DB5), U4.16 (B2)
/D6: J9.34 (DB6), U4.17 (B1)
/D7: J9.33 (DB7), U4.18 (B0)
/DACK1: J9.17 (~DACK1)
/DACK2: J9.26 (~DACK2)
/DACK3: J9.15 (~DACK3)
/DEN: R1.1, U1.56 (BUFFEN), U4.19 (CE)
/DRQ0: J1.12, U1.36 (INTAK/SRDY/TOUT1)
/DRQ1: J9.18 (DRQ1)
/DRQ2: J9.6 (DRQ2)
/DRQ3: J9.16 (DRQ3)
/DTR: U1.57 (BUFR/W), U4.1 (A->B)
/GND: C1.1, C2.1, C3.1, C4.1, J9.1 (GND), J9.10 (GND), J9.31 (GND), R2.1, U1.18 (GND), U1.52 (GND), U2.10 (GND), U3.10 (GND), U4.10 (GND); also elsewhere on the board
/HF_PCLK: J1.11, U1.44 (TCLK)
/HOLD: J1.14, U1.4 (HLDRQ)
/HOLDA: J1.13, U1.3 (HLDAK), U2.1 (OE), U3.1 (OE)
/IORD: J9.14 (~IOR), U1.61 (IORD)
/IOWR: J9.13 (~IOW), U1.59 (IOWR)
/IO_000X: J1.2
/IO_002X: J1.3
/IO_004X: J1.4
/IO_006X: J1.5
/IO_008X: J1.6
/IRQ1: J1.1, U1.37 (INTP1)
/IRQ2: J9.4 (IRQ2), U1.38 (INTP2)
/IRQ3: J9.25 (IRQ3), U1.39 (INTP3)
/IRQ4: J9.24 (IRQ4), U1.40 (INTP4)
/IRQ5: J9.23 (IRQ5), U1.41 (INTP5)
/IRQ6: J9.22 (IRQ6), U1.42 (INTP6)
/IRQ7: J9.21 (IRQ7), U1.43 (INTP7)
/MRD: J9.12 (~SMEMR), U1.62 (MRD)
/MWR: J9.11 (~SMEMW), U1.60 (MWR)
/NC: J9.8 (UNUSED)
/NMI: J1.8, U1.66 (NMI)
/OSC88: J9.30 (OSC)
/POLL: R2.2, U1.47 (POLL)
/RDY1: J9.41 (IO_READY), U1.67 (READY)
/READY: J1.15
/REFRQ: J9.19 (~DACK0)
/RESET: J1.16, U1.68 (RESET)
/RESOUT: J9.2 (RESET)
/SPK_GO: J1.10, U1.46 (TCTL2)
/SPK_OUT: J1.9, U1.45 (TOUT2)
/TC: J9.27 (TC)
/X1: U1.54 (X1), Y1.2
/X2: U1.53 (X2), Y1.1


Board: 2 copper layers, 132.0 x 73.9 mm, 15 parts (0 on the bottom side), 68 nets.

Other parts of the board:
R: L; Large_Via
R#2: L; Large_Via

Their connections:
/GND: R.1; also elsewhere on the board

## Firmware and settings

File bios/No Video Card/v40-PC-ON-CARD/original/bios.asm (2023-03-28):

Date:     Wed, 13 Jan 88 04:26 PST
From:     <MULTI%TRIUMFCL.BITNET@CUNYVM.CUNY.EDU>
Subject:  BIOS.ASM update INFO-IBMPC librarys
To:       hicks@walker-emh.arpa

Page    80,132
Title   BIOS    - For Intel 8088 or NEC "V20" turbo motherboards.  Use MASM 4.0
;
; This bios will work on IBM-PC/xt and many other compatibles that share a
; similar design concept.  You do not need to have a turbo motherboard to
; use this bios, but if you do, then use the following key sequence
;                               CTRL ALT -
; to toggle the computer speed between fast and slow (=IBM compatible)
;
; This BIOS can produce the following error messages at IPL time
;
ER_BIOS equ     01h             ; Bad ROM bios checksum, patch last byte
ER_RAM  equ     02h             ; Bad RAM in main memory, replace
ER_CRT  equ     04h             ; Bad RAM in video card, replace
ER_MEM  equ     10h             ; Bad RAM in vector area, replace
ER_ROM  equ     20h             ; Bad ROM in expansion area, bad checksum
;
; The last two bytes have to be patched with DEBUG as follows
;
;   FFFF 00.xx          ( avoid ER_BIOS on bootstrap ) --------------------
;   FFFE 00.FE          ( leaves IBM-PC/xt signature ) -----------------  |
;                                                                      |  |
; where "xx" results in a zero checksum for the whole BIOS rom, for ex |  |
;                                                                      |  |
;               masm BIOS;              ( Assemble BIOS source code)   |  |
;               link BIOS;              ( Link the BIOS object code)   |  |
;               debug BIOS.EXE          ( Exe2bin  BIOS binary code)   |  |
;               -nBIOS.BIN              ( Name of the output binary)   |  |
;               -eCS:FFFE               ( Opens BIOS signature byte)   |  |
;               .FE                     ( Leave IBM-PC/xt signature) <--  |
;               -eCS:FFFF               ( Opens BIOS checksum  byte)      |
;;  ------->    .DC                     ( Force ROM checksum = zero) <-----
;;              -rBX                    ( Opens hi order byte count)
;;              :0                      (  ... must be 0 bytes long)
;;              -rCX                    ( Opens lo order byte count)
;;              :2000                   (  ... BIOS 2000 bytes long)
;;              -wCS:E000               ( Output to BIOS.BIN   file)
;;              -q
;;
;; You must correct the checksum by manually patching the last byte so as the
;; the entire 2764-2 eprom sums to zero.  I wish DEBUG could checksum blocks.
;
; ************************Miscellaneous definitions************************
;                                                                         *
MAX_MEMORY      =704            ; Maximum kilobytes of memory allowed     *
;SLOW_FLOPPY    =1              ; Define to run floppy always at 4.77 mHz *
;                                                                         *
; ************************Miscellaneous definitions************************
;
entry   macro   x
        pad     =BANNER - $ + x - 0E000h
        if pad LT 0
        .err
        %out    'No room for ENTRY point'
        endif
        if pad GT 0
        db      pad DUP(0FFh)
        endif
endm
;
jmpf    macro   x,y
        db      0EAh;
        dw      y,x
endm
;
retf    macro   x
        ifb     <x>
        db      0CBh
else
        db      0CAh
        dw      x
endif
endm
;
LF      equ     0Ah
CR      equ     0Dh
;
 .SALL                                          ; Suppress Macro Expansions
 .LFCOND                                        ; List  False  Conditionals
;
ASSUME  DS:code, SS:code, CS:code, ES:code
data    SEGMENT at 40h                          ; IBM compatible data structure
        dw      4 dup(?)        ; 40:00         ; RS232 com. ports - up to four
        dw      4 dup(?)        ; 40:08         ; Printer ports    - up to four
        dw      ?               ; 40:10         ; Equipment present word
                                                ;  + (1 iff floppies) *     1.
                                                ;  + (# 64K sys ram ) *     4.
                                                ;  + (init crt mode ) *    16.
                                                ;  + (# of floppies ) *    64.
                                                ;  + (# serial ports) *   512.
                                                ;  + (1 iff toy port) *  4096.
                                                ;  + (# parallel LPT) * 16384.
        db      ?               ; 40:12         ; MFG test flags, unused by us
        dw      ?               ; 40:13         ; Memory size, kilobytes
        db      ?               ; 40:15         ; IPL errors<-table/scratchpad
        db      ?                               ;  ...unused
;---------------[Keyboard data area]------------;
        db      ?,?             ; 40:17         ; Shift/Alt/etc. keyboard flags
        db      ?               ; 40:19         ; Alt-KEYPAD char. goes here
        dw      ?               ; 40:1A         ;  --> keyboard buffer head
        dw      ?               ; 40:1C         ;  --> keyboard buffer tail
        dw      16 dup(?)       ; 40:1E         ; Keyboard Buffer (Scan,Value)
;---------------[Diskette data area]------------;
        db      ?               ; 40:3E         ; Drive Calibration bits 0 - 3
        db      ?               ; 40:3F         ; Drive Motor(s) on 0-3,7=write
        db      ?               ; 40:40         ; Ticks (18/sec) til motor off
        db      ?               ; 40:41         ; Floppy return code stat byte
                                                ;  1 = bad ic 765 command req.
                                                ;  2 = address mark not found
                                                ;  3 = write to protected disk
                                                ;  4 = sector not found
                                                ;  8 = data late (DMA overrun)
                                                ;  9 = DMA failed 64K page end
                                                ; 16 = bad CRC on floppy read
                                                ; 32 = bad NEC 765 controller
                                                ; 64 = seek operation failed
                                                ;128 = disk drive timed out
        db      7 dup(?)        ; 40:42         ; Status bytes from NEC 765
;---------------[Video display area]------------;
        db      ?               ; 40:49         ; Current CRT mode  (software)
                                                ;  0 = 40 x 25 text (no color)
                                                ;  1 = 40 x 25 text (16 color)
                                                ;  2 = 80 x 25 text (no color)
                                                ;  3 = 80 x 25 text (16 color)
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

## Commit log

2021-11-08 update
    update from Raspberry PI files.
2021-11-10 Fixed original files
    Most important add back in jump code to bios.asm
    [bios.asm]
2021-11-16 Added Parts Lists
    [512k.xlsx, 8088 V20.xlsx, Complete.xlsx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]
2021-11-16 Fixed directory names to be more friendly with Linux
    [512k.xlsx, 8088 V20.xlsx, Complete.xlsx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]
2021-11-16 Update 8088 V20.xlsx
    [8088 V20.xlsx]
2021-11-16 Updated Network Drivers
2021-11-17 Deleted Files
    [512k.xlsx, 8088 V20.xlsx, Complete.xlsx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]
2021-11-20 Updated 80188 Schematic
2021-12-25 Update Main Board 8 BIT 7 ISA.pdf
2022-01-04 Added KICAD files
    [512k-B_Cu.gbr, 512k-B_Mask.gbr, 512k-B_Paste.gbr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]
2022-01-08 fixed 5+ pin on PCB
    [Multi.kicad_pcb, Multi.sch]
2022-01-28 Updated Kicad files
    [512k-B_Cu.gbr, 512k-B_Mask.gbr, 512k-B_Paste.gbr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]
2022-03-14 Added 640k Ram Card
    [640k-B_Cu.gbr, 640k-B_Mask.gbr, 640k-B_Paste.gbr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]
2022-03-24 Update to DMA card
    [DMA.kicad_pcb, DMA.sch]
2022-03-24 Updated Gerber files
    [DMA-B_Cu.gbr, DMA-B_Mask.gbr, DMA-B_Paste.gbr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]
2022-03-26 DMA update
    [DMA-B_Cu.gbr, DMA-B_Mask.gbr, DMA-B_Paste.gbr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]
2022-03-26 Gerber update
    [DMA-B_Cu.gbr, DMA-B_Mask.gbr, DMA-B_Paste.gbr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]
2022-03-28 Added port 0x61 read to 4 slot main board
    [Multi.kicad_pcb, Multi.sch]
2022-03-29 4 Slot Main board update
    [Multi-B_Cu.gbr, Multi-B_Mask.gbr, Multi-B_Paste.gbr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]
2022-04-01 Updated 640k Gerber files
    [640k-B_Cu.gbr, 640k-B_Mask.gbr, 640k-B_Paste.gbr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]
2022-04-03 640k update
    [640k-B_Cu.gbr, 640k-B_Mask.gbr, 640k-B_Paste.gbr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]
2022-04-04 Updated DMA card
    [BOM_DMA.xlsx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]
2022-04-05 update 8088 card
    [8088-B_Cu.gbr, 8088-B_Mask.gbr, 8088-B_Paste.gbr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]
2022-04-09 Update main board
    [Multi.kicad_pcb, Multi.sch]
2022-04-16 Updated Schematics
2022-04-25 Added LCD ISA card
    [LCD 8255-B_Cu.gbr, LCD 8255-B_Mask.gbr, LCD 8255-B_Paste.gbr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]
2022-05-24 Added 10 Slot main board
    [Multi-B_Cu.gbr, Multi-B_Mask.gbr, Multi-B_Paste.gbr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]
2022-05-28 Update Gerber files
    [Multi-B_Cu.gbr, Multi-B_Mask.gbr, Multi-B_Paste.gbr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]
2022-06-13 Added CH376 Module
    [CH376S Module-B_Cu.gbr, CH376S Module-B_Mask.gbr, CH376S Module-B_Paste.gbr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]
2022-06-28 Added 386EX prototype
    [386EX.kicad_pcb, 386EX.sch]
2022-07-06 updates to 386
    [386EX.kicad_pcb, 386EX.sch, CH376S Module.kicad_pcb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]
2022-07-20 update label on 80188
    [80188.kicad_pcb]
2022-07-22 added 8088 card with ZIF socket
    [8088-B_Cu.gbr, 8088-B_Mask.gbr, 8088-B_Paste.gbr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]
2022-07-24 add 64k ROM card
    [640k-B_Cu.gbr, 640k-B_Mask.gbr, 640k-B_Paste.gbr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]
2022-09-13 Added 8088 Max mode
    [8088-B_Cu.gbr, 8088-B_Mask.gbr, 8088-B_Paste.gbr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]
2022-09-16 update 8088 max
    [8088.kicad_pcb, 8088.sch]
2022-11-03 Added PCB's
    [64K 640K ISA-B_Cu.gbr, 64K 640K ISA-B_Mask.gbr, 64K 640K ISA-B_Paste.gbr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]
2023-01-02 updated DMA
    Added DMA controller to main board.
    [64K 640K ISA-B_Cu.gbr, 64K 640K ISA-B_Mask.gbr, 64K 640K ISA-B_Paste.gbr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]
2023-02-17 Updated Gerber's
    [386EX.kicad_pcb, 386EX.sch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]
2023-02-21 ADDED Port
    [64K 640K ISA-B_Cu.gbr, 64K 640K ISA-B_Mask.gbr, 64K 640K ISA-B_Paste.gbr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]
2024-05-23 moved files
    [Breadboard Adapter-B_Cu.gbr, Breadboard Adapter-B_Mask.gbr, Breadboard Adapter-B_Paste.gbr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]

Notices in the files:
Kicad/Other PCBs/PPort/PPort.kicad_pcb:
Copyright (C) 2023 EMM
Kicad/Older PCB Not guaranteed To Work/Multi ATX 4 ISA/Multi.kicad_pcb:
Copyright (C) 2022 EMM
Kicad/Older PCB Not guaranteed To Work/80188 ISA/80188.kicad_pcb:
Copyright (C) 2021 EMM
